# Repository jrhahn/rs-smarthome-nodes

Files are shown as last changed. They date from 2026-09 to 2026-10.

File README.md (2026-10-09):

# rs-smarthome-nodes

Async `no_std` Rust ([Embassy](https://embassy.dev)) firmware for a fleet of
**Seeed Studio XIAO ESP32-C3** smart-home sensor nodes. One image serves every
node: `NODE=<name>` at build time selects which sensors are populated, what the
node is called, and whether it sleeps between readings or stays associated.
Home Assistant picks the nodes up automatically over **MQTT
auto-discovery** — no hand-declared entities.

It started as a battery bird-feeder scale, which is still the default node
(`NODE=terrasse`): on each wake-up it reads a load cell via an HX711 amplifier
and compares it against a tare baseline kept in RTC RAM. While the feeder is
empty it polls every couple of seconds from **light** sleep — no radio, and no
cold boot per poll — which bounds how short a visit it can see at all. The
amplifier is powered down between those polls, and its settling time after
power-up is waited out asleep rather than awake. Once weight crosses the threshold it
stops sleeping and **watches the visit through awake**, so the published weight
is a settled median rather than whichever conversion happened to land first, and
the visit gets a real duration instead of one rounded to the sleep interval;
then it brings up Wi-Fi and publishes once (grams converted on-device). A
periodic **heartbeat** (default every 10 min) publishes anyway, so
Home Assistant always has a fresh reading. While online it also pulls any
retained calibration/tuning back from Home Assistant and persists it to flash.

```
┌──────────┐  bit-bang   ┌────────┐       Wi-Fi/MQTT            ┌────────────────┐
│  Load    │────────────▶│ HX711  │──▶ ESP32-C3 ───────────────▶│ Home Assistant │
│  Cell    │  DT / SCK   │ 24-bit │   smarthome/<node>/<key>    │                │
└──────────┘             └────────┘   ◀── config/* (retained) ──│  (calibration) │
   SHT31-D / SCD41 / SGP41 ─ I²C ────▶                          └────────────────┘
   SDS011 ─ UART ────────────────────▶  homeassistant/… (discovery, retained)
   battery divider ─ ADC ────────────▶
```

## The fleet

Pick a node with `NODE=` at build time (`src/node.rs`); an unknown name fails
the build rather than flashing the wrong personality onto a board. A board can
also be **provisioned** to another identity afterwards, without a rebuild.

| `NODE=` | Room | Sensors | Outputs | Power |
| --- | --- | --- | --- | --- |
| `terrasse` (default) | Terrasse | HX711 load cell + SHT31-D + cell voltage | — | battery, deep sleep |
| `schlafzimmer` | Schlafzimmer | SCD41 + SHT31-D | — | mains |
| `wohnzimmer` | Wohnzimmer | SCD41 + SHT31-D + SDS011 + SGP41 | — | mains (fan) |
| `kueche` | Küche | SHT31-D | — | mains, duty-cycled |
| `bad` | Bad | SHT31-D | — | mains, duty-cycled |
| `solarleuchte` | Garten | SHT31-D + cell voltage | LED string (LEDC) | battery, deep sleep |

A board can be told to become another node over MQTT, without reflashing — see
[provisioning](docs/flashing.md#7-provisioning-a-board-without-reflashing).

**Power profiles** decide the loop. *Battery* nodes cold-boot out of deep sleep,
measure, publish only when there is something to say, and sleep again, at the
runtime intervals set from [Home Assistant](docs/home-assistant.md#configure--calibrate-from-home-assistant). *Mains* nodes stay associated and sample on a fixed
per-node cadence — CO₂ continuity and the SDS011's duty-cycled fan both rule out
deep sleep. A sensor whose own cadence is slower than the node's round says so
per slot (`Slot::every`), which is how `wohnzimmer` reads CO₂ every minute while
its fan runs four times an hour.

*Mains, duty-cycled* is the third: on a cable, but deep-sleeping between rounds
anyway. The reason is heat rather than power. A node that keeps Wi-Fi up draws
something like 80–110 mA without pause, which is roughly a third of a watt
warming the inside of a small box, and a node whose entire job is to report the
room's temperature cannot afford to warm the air it is measuring. `kueche` and
`bad` carry nothing that needs continuity, so they stop running between
readings, sleeping their own `sample_secs` — the cadence they already published
at, so no history gets a step in it. Any node that sleeps at all keeps the
`config/deep_sleep` switch, which holds it awake for bench testing.

## Quick start

```bash
cp .env.example .env              # Wi-Fi + MQTT credentials; direnv loads it
NODE=kueche cargo run --release   # build, flash over USB-C, open the monitor
```

The full procedure — toolchain, the partition table, flashing a sleeping node,
what a healthy boot log looks like — is in [docs/flashing.md](docs/flashing.md).

## Documentation

| | |
| --- | --- |
| [docs/flashing.md](docs/flashing.md) | building, flashing, provisioning, Wi-Fi credentials over the console |
| [docs/wiring.md](docs/wiring.md) | pin map and wiring for every node |
| [docs/home-assistant.md](docs/home-assistant.md) | topics, entities, calibration and tuning knobs |
| [docs/enclosure.md](docs/enclosure.md) | the printed enclosures (`cad/`) |
| [docs/base-platform.md](docs/base-platform.md) | design notes: node abstraction, power profiles, discovery, testing |
| [docs/ota.md](docs/ota.md) | over-the-air updates |
| [docs/solar.md](docs/solar.md), [docs/solarleuchte.md](docs/solarleuchte.md) | solar for `terrasse`; the rebuilt garden lamp |
| [docs/long-term-history.md](docs/long-term-history.md) | keeping the fleet's data for years |
| [docs/commissioning.md](docs/commissioning.md) | what is physically built, board by board |
| [docs/annotations.md](docs/annotations.md) | fleet log: rollouts, outages, recalibrations — dated |
| [CHANGELOG.md](CHANGELOG.md) | what changed in the code |

## Repository layout

```
src/            firmware (lib + bin); sensors/ holds the bus-generic drivers
examples/       lamp_bench — bench rig for the solarleuchte lamp
timeseries/     the QuestDB archiver and dashboard (own crate)
cad/            CadQuery source (models.py) and exported STEP/STL
docs/           everything above
partitions.csv  OTA partition table, passed on every flash
```

## Tests

A firmware binary for `riscv32imc` cannot host a test harness, so the crate is
split: [`src/lib.rs`](src/lib.rs) holds everything the binary is made of, and
the parts that are **pure computation** — frame decoding, CRCs, the flash blob
layouts, `Config::apply`, the discovery payloads, the node table — build without
the HAL and therefore run on the host.

```bash
# What CI runs
cargo test --no-default-features --features host-tests \
    --target x86_64-unknown-linux-gnu
```

The sensor drivers themselves are covered too. They are generic over the
`embedded-hal-async` / `embedded-io-async` bus traits, so
[`src/sensors/mock.rs`](src/sensors/mock.rs) can feed the *real* SHT31, SCD41
and SDS011 drivers a scripted bus: canned I²C replies, and a UART that hands
over stale frames, falls quiet, then delivers the frame that matters. That
covers the resync, the CRC rejection, the fan duty cycle, the SCD41's two run
modes and its data-ready handshake, and what happens when a sensor is absent —
but not timing, bus contention or anything electrical, which stay bench
questions.

Anything that touches the chip itself — RTC RAM, flash, the radio, the bit-bang
drivers — sits behind the `hal` feature (on by default), so a normal
`cargo build` is unaffected. Compile-time
`const _: () = assert!(…)` checks stay where they are: they cost nothing and
fail the *build*, which is stronger than a test — the tests cover what
const-eval cannot reach, such as anything that formats a string, negative cases,
and inputs enumerated in a loop.

[CI](.github/workflows/ci.yml) runs the tests, both clippy passes, and builds
every node in the fleet — plus a check that a mistyped `NODE=` still fails the
build.

## Long-term history

Home Assistant sees every node the moment it publishes, and keeps a recorder
database — tuned for weeks. The questions this fleet was built for are slower
than that: did insulating the roof change the bedroom's overnight CO₂, how does
the terrace swing between summers, is the feeder busier this year than last.

[`timeseries/`](timeseries/README.md) is a second consumer on the same broker
whose only job is not to lose anything. It follows the topics the nodes already
publish, writes each reading into **QuestDB** with a **three-year retention**,
maintains three cascading rollup views (`_1m` → `_1h` → `_1d`) so a year-wide
chart reads thousands of rows instead of millions, and serves a small dashboard
that routes each query to the coarsest view still fine enough to answer it.

```bash
nix develop .#timeseries
cd timeseries && cargo run -- timeseries.example.toml   # then http://127.0.0.1:8087
```

It changes nothing about the firmware or the Home Assistant side — a node does
not know it is being archived. The flake carries a package and a NixOS module
(which brings up QuestDB too, since nixpkgs ships the package but no service)
for the home server; see [`timeseries/README.md`](timeseries/README.md) for the
schema, the rollup reasoning, and how to deploy it.

## License

MIT — see [LICENSE](LICENSE).

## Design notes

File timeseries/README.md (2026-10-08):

# `smarthome-timeseries`

The fleet's long-term memory: one process that follows the MQTT topics the
nodes already publish, writes every reading into **QuestDB** with a **three-year
retention**, and serves a small dashboard that reads it back.

```
┌──────────┐   smarthome/<node>/<key>   ┌───────────────┐   ILP/HTTP   ┌──────────┐
│  nodes   │───────────────────────────▶│   this        │─────────────▶│ QuestDB  │
│ (ESP32)  │   homeassistant/…/config   │   service     │◀── SQL ──────│ readings │
└──────────┘───────────────────────────▶│               │              │ + 3 views│
                                        └───────┬───────┘              └──────────┘
      ┌────────────────┐                        │  HTTP :8087
      │ Home Assistant │◀── same broker ────────┘  charts, live values, health
      └────────────────┘
```

Nothing here touches the firmware or Home Assistant's configuration. A node does
not know it is being archived; switching this off leaves the house working
exactly as before.

## Why it exists

Home Assistant already sees every node — the firmware announces itself over MQTT
auto-discovery — and it keeps a recorder database. What it does not keep is
*years*. Its recorder is tuned for weeks, and the questions this fleet was built
to answer are the slow ones: did insulating the roof change the bedroom's
overnight CO₂, how does the terrace swing between summers, is the bird feeder
busier this year than last.

So: a second consumer on the same broker, whose only job is not to lose
anything.

## What it stores, and what it does not

The firmware's topic layout is the entire schema:

| Topic | Stored as |
| --- | --- |
| `smarthome/<node>/<key>` | a row in `readings` |
| `smarthome/<node>/status` | a row in `node_status`, **on change only** |
| `smarthome/<node>/config/<key>` | nothing — a setting, not an observation |
| `smarthome/provision/<mac>` | nothing — an instruction |
| `homeassistant/sensor/<node>/<key>/config` | nothing; read for units and names |

Two details that are easy to get wrong, and are tested:

- **`provision` is not a node.** `smarthome/provision/a1b2c3d4e5f6` has the same
  three segments as a reading, and would otherwise be archived as a node called
  `provision` with a sensor called `a1b2c3d4e5f6`.
- **A retained reading is not a new reading.** The broker replays retained
  messages when this service subscribes, and the only timestamp available here
  is "now" — so a replay would stamp an old value as current. Readings arriving
  with the retain flag are skipped. This does not affect live publishes: MQTT
  clears the flag on messages delivered to an already-subscribed client, so a
  node publishing retained data is still archived normally.

Timestamps are when the bridge received the message. The nodes send none of
their own — they are `no_std` boards without a clock — and on a broker on the
same LAN the gap is milliseconds.

## The database

```sql
readings(timestamp TIMESTAMP, node SYMBOL, sensor SYMBOL, value DOUBLE)
  TIMESTAMP(timestamp) PARTITION BY DAY TTL 3 YEARS
```

plus three cascading materialized views, each aggregating the next finer one:

| View | Bucket | Reads | Partition |
| --- | --- | --- | --- |
| `readings_1m` | 1 minute | `readings` | day |
| `readings_1h` | 1 hour | `readings_1m` | month |
| `readings_1d` | 1 day | `readings_1h` | year |

Each stores `min`, `max`, `sum` and `count` per channel per bucket. The mean is
re-derived at read time as `sum(sv)/sum(n)` — the exact mean of the underlying
readings, not an average of averages that would weight a sparse hour (node
asleep, one reading) like a full one.

**Why cascade.** QuestDB refreshes a view by re-aggregating the buckets the new
rows touched. A daily view built directly on the base table therefore re-scans
the whole current day on every commit, for ever. Built on the hourly view it
re-reads twenty-four rows per channel.

**Why not timers.** The gateway firmware puts its coarse tiers on `REFRESH EVERY
5m` / `1h`, because at 100 Hz ingest an immediate refresh of every tier is what
pegged three CPU cores. This fleet publishes about one reading a minute per
channel, so there is nothing for a timer to save — and on QuestDB 9.3.5 a
timer-refreshed view created over a source that was still empty did not pick up
2160 rows inserted into that source over the following twenty minutes. That is
exactly the shape of a first install. Every tier here is `REFRESH IMMEDIATE`.

**Retention** is a QuestDB table TTL, applied to the base table and to every
view, and re-applied on each start — so changing `retention` in the settings
file is enough to change it on a table that already exists. QuestDB drops data a
whole partition at a time, which is why the setting must be a whole number of
days or coarser.

## Reading it back

`GET /api/series?node=…&sensor=…&from=…&to=…&points=…` picks a bucket from a
fixed ladder (1s … 30d), then routes the query to the **coarsest view whose
bucket is still fine enough**. Below a minute, and whenever a view is missing,
it reads the base table. The response is identical either way — `lo`, `hi`, `av`
per bucket — so the chart never branches on where the numbers came from.

Two things make that promise literal rather than approximate:

- The window is **widened to whole buckets** before querying. Ask for "the last
  365 days" at a daily grain and the window starts mid-day: the raw table would
  answer with a partial first bucket while the daily view's row for that day
  starts before the window and is filtered out entirely. Rounded out, both
  answer with the same full bucket.
- A rollup that returns nothing is **retried against the base table**, so a view
  that is somehow behind shows the truth rather than a blank chart.

This is checked against a live database rather than asserted: see the smoke test
below, which compares every zoom level against a full scan of the raw table.

| Endpoint | |
| --- | --- |
| `GET /` | the dashboard (three embedded files, no CDN, no build step) |
| `GET /api/overview` | every channel at once: labels, last value, and a sparkline |
| `GET /api/series` | one channel, full resolution |
| `GET /api/periods` | every channel per day / week / month in local time; meters as consumption |
| `GET /api/annotations` | the notes in a window; `POST` writes one |
| `POST /api/annotations/void` | takes one back, by `at_ms` and `node` |
| `GET /api/channels` | the channel list without any series — for scripts |
| `GET /api/health` | broker and database reachability, rollups, counters |

`/api/overview` is one database query for the whole screen rather than one per
channel. Thirty-one round trips to paint a page would be the obvious way and the
wrong one; the rollups are already grouped by channel, so the same `SAMPLE BY`
without a `node`/`sensor` filter answers all of them together.

## Periods: per day, week and month

`GET /api/periods?period=day|week|month&count=N` answers the question the
sliding window cannot: how much water did Tuesday take, is this month's
electricity more than last month's. Periods start where the house's day starts —
local midnight, Monday, the 1st, in `Europe/Berlin` — via `SAMPLE BY 1d|1w|1M
ALIGN TO CALENDAR TIME ZONE`.

- **Meters** — channels whose discovery message says `state_class`
  `total_increasing` or `total` — are reported as **consumption**: the period's
  last reading minus the previous period's last reading. Not the maximum: the
  water meters are read by a camera, a misread digit sends one reading up and
  the next back, and differences of last readings still sum to exactly the
  meter's movement over the range. A period that went backwards (misread,
  reset) is kept and flagged `approx`; so is the first period of a history,
  which has nothing to subtract.
- **Everything else** gets min / mean / max per period.

Meters are read from the base table, because the rollups keep no `last()`;
measurements from `readings_1h`, whose hourly buckets line up with local days in
both CET and CEST.

The page shows them as a second view (**Periods** in the header, `#p/day`): a bar
per period for every meter with a unit, unitless counts folded away beneath,
and a table of means per node. Channels Home Assistant marks `diagnostic` are
left out.

## What the dashboard shows

Two views, and the split is the useful part.

**The overview** is a wall of tiles, one per channel, grouped by node: the
current value, its unit, a sparkline over the selected range, and the span that
sparkline covers. Small multiples rather than one chart with thirty-one lines
on it — the channels are in different units, and a shared axis across
micrograms, parts per million and degrees would be a lie. Node headings carry an
online/offline word beside the dot, because green and red are precisely the pair
a colour-blind reader cannot separate.

**The detail view** is one channel at full size: the min/max band with the mean
through it, min / mean / max / last as numbers above it, a crosshair that reads
out the bucket under the pointer, and the same numbers as a table for anything a
curve reads badly. Time ticks land on the hour, midnight or the first of the
month rather than on the span divided by eight — evenly spaced ticks put
`10.09.` on the axis twice on a week-wide chart.

Both views live in the URL: `#c/<node>/<sensor>/<range>` is a chart worth
sending to someone, and reloading keeps it.

### Zooming

Drag a span on the chart, scroll to zoom around the pointer, double-click to go
back — the same three gestures as the gateway's plots, because a chart you have
to learn twice is a chart nobody drags.

Two things make it behave rather than merely respond. A zoom pins an **absolute**
window, so the 30 s refresh stops sliding it: a window that moves while you are
measuring something against it is worse than no zoom at all. And a double-click
returns to the view that was active *before* zooming in, not to the widest range
there is — it is an undo, not a reset.

The window goes into the URL as `#c/<node>/<sensor>/<from>-<to>` in epoch
seconds, so a zoomed chart is as shareable as a preset one. While a zoom is
active no preset button is lit, because none of them is what is on screen, and
the footer says so along with the way out.

Nothing is vendored for this. The chart is a few hundred lines of canvas, and
three mouse handlers is a smaller thing to own than a plotting library.

### Comparing with the windows before it

**Compare** lays the six preceding windows of the same length behind the current
one. With the 24 h range that is today against the same hours of the last six
days — which is the question a house actually raises: *is this normal for a
Tuesday, or is something different?* With 7 d it is this week against the last
six weeks.

Each overlay is shifted forward by exactly one window length, so the clock lines
up: an hour on the axis is the same hour in every line, and with a 7 d window
the same weekday too. That alignment is the whole feature.

They are drawn as six steps of **one** hue at falling opacity, not six colours.
These are the same measurement at different times, which is an *order*, and an
order wants a ramp — six hues would claim they are six different things. The
current window keeps the solid 2 px line; the rest are thinner and quieter,
because one of them is the subject and six are the backdrop.

Two details that make it readable rather than merely correct. The min/max band
is dropped while comparing: it is the spread *within* one window laid over six
other windows' lines, and it is the one element wide enough to hide exactly what
the mode was turned on to show. And the tooltip lists all seven values at the
crosshair — the eye can see the lines differ, and this is what says by how much.

The earlier windows count towards the y-axis by their mean only, so one old
outlier's envelope cannot squash the window being looked at.

**Where the alignment is approximate:** a shift is a fixed number of
milliseconds. For 6 h, 24 h and 7 d that is exact. For 30 d it is not a calendar
month, and for 1 y it is 365 days, so leap years and month lengths drift. Read
those two as "roughly a month/year back", not as the same date.

**The page is in English and formats in `en-GB`**, pinned rather than taken from
the browser. A dashboard whose decimal separator depends on who opens it makes
two screenshots of the same reading disagree, which is a bad property for a
thing whose whole job is to be looked at later.

### CSV

The detail view's **CSV** button downloads what is plotted: the buckets behind
the chart and the table, not the raw readings — a three-year range is millions
of rows, and the page never had them.

The file formats for whatever opens it next rather than for a reader, and the
two are not the same thing. Timestamps are ISO 8601 in UTC, numbers carry full
precision with a dot, the separator is a comma and the line ending is CRLF, per
RFC 4180. Column headings name the unit (`mean (°C)`), and the file begins with
a byte-order mark for one reason: without it Excel reads the degree sign as two
characters of noise.

The bucket width is in the filename —
`kueche_temperature_2026-09-13_2026-09-14_5m.csv` — so a spreadsheet found again
in three months still says what one row covers.

## Annotations

A series outlives the memory of the hardware that produced it. The terrace's
weight steps because the scale was recalibrated, not because a heavier bird
arrived; the living room's VOC index climbs from 1 for a day because the
algorithm is learning the room. None of that is in the numbers.

`annotations` is a table beside the readings — timestamp, node, one sentence —
and the notes are drawn on the chart at the moment they describe. **It carries
no TTL at any setting**: a note that expires before the data it explains is
worse than no note at all.

The dashboard's *Notiz …* button writes one. `docs/annotations.md` in this
repository keeps the same history in prose and is the better place for the long
version; this is the half that a chart can draw.

### A note is confirmed, and can be taken back

Two properties this table needs that the readings do not, both learned the
expensive way on 2026-09-13.

**The write is read back before it returns.** QuestDB answers before it stores:
ILP over HTTP returns 204 once the line is *accepted*, so a line written against
a table created moments earlier can be dropped with the caller told it
succeeded. That is tolerable for a reading — another arrives in two minutes —
and not for a note, which is written once, by hand, about something nobody will
remember well enough to write again. `insert` therefore polls until the row is
visible and fails loudly if it never is.

**A note can be voided, because it can never be corrected.** The timestamp is
the designated column, so no `UPDATE` may move it, and QuestDB deletes no rows
at all. Before this, one mistyped timestamp could only be fixed by dropping the
whole table. Each note now carries `voided`, the *zurücknehmen* button beside it
sets it, and voided notes are left out of `GET /api/annotations`.

Marked rather than removed, on purpose: a log of what happened to the fleet
that silently loses its own corrections has a blind spot exactly where somebody
already got something wrong once. The row stays, and `select ... from
annotations` still shows it.

`UPDATE` needs the same read-back as the insert, and for a sharper reason —
QuestDB reports `{"dml":"OK","updated":N}` where `N` is a running total, not the
rows this statement touched. An `UPDATE` that matched nothing is indistinguishable
from one that matched everything. So voiding checks that a note is standing
there first, and afterwards that it no longer is.

An existing table is migrated on start: `CREATE TABLE IF NOT EXISTS` leaves one
alone, so the column is added by a separate `ALTER TABLE ... ADD COLUMN IF NOT
EXISTS`, which QuestDB accepts repeatedly and backfills as `false` — every note
written before anyone could take one back still counts.

## Configuration

One TOML file, every field optional — see
[`timeseries.example.toml`](timeseries.example.toml). Defaults assume a broker
and a QuestDB on localhost. Passwords can come from `password_file` so they stay
out of the file (and, on NixOS, out of the store).

## Building and running

The firmware's toolchain pin does not apply here; this crate has a
`rust-toolchain.toml` of its own and a `.cargo/config.toml` that undoes the
riscv32 default.

```bash
nix develop .#timeseries      # nixpkgs rustc, plus questdb and mosquitto
cd timeseries
cargo test                    # 75 tests, no database needed
cargo clippy --all-targets -- -D warnings
cargo run -- timeseries.example.toml
```

### The end-to-end smoke test

The unit tests cover the parts that are pure computation — topic classification,
ILP formatting, DDL shape, tier routing, bucket snapping. What they cannot cover
is whether QuestDB accepts any of it. That needs a real database:

```bash
# a QuestDB and a broker of their own, on ports nothing else uses
mkdir -p /tmp/ts-smoke/qdb/conf
cat > /tmp/ts-smoke/qdb/conf/server.conf <<'EOF'
http.bind.to=127.0.0.1:19000
http.min.net.bind.to=127.0.0.1:19003
pg.net.bind.to=127.0.0.1:18812
line.tcp.net.bind.to=127.0.0.1:19009
EOF
questdb.sh start -n -d /tmp/ts-smoke/qdb &
printf 'listener 11883 127.0.0.1\nallow_anonymous true\n' > /tmp/ts-smoke/mosquitto.conf
mosquitto -c /tmp/ts-smoke/mosquitto.conf &

# then point a settings file at 11883 / 19000 and run the service against it,
# publish with mosquitto_pub, and compare a rollup-answered chart against a
# full scan of the base table.
```

Doing exactly that is what turned up the two edge cases the code now handles
(partial buckets at a window's edge, and coarse views left empty by a timer).

## On the home server

The flake exposes a package and a NixOS module. The module also brings up
QuestDB itself, because nixpkgs ships the package but no service:

```nix
{
  inputs.smarthome-nodes.url = "github:jrhahn/rs-smarthome-nodes";

  # in the host's configuration:
  imports = [ inputs.smarthome-nodes.nixosModules.smarthome-timeseries ];

  services.smarthome-timeseries = {
    enable = true;
    settings = {
      mqtt.host = "127.0.0.1";       # the broker Home Assistant already uses
      questdb.retention = "3y";
      web.bind = "127.0.0.1:8087";
    };
    # Kept out of the store; systemd hands it over as a credential.
    mqtt.passwordFile = "/run/secrets/mqtt-password";
  };
}
```

The archiver runs as a `DynamicUser` with no state of its own. QuestDB gets a
static user and `/var/lib/questdb`, which is **the one directory worth backing
up** — it holds the data, the write-ahead log and the configuration.

Both QuestDB ports bind to loopback by default. That is deliberate: QuestDB's
HTTP interface serves ingestion, arbitrary SQL *and* a web console, none of it
authenticated.

> **Upgrades are one-way.** QuestDB's storage format only moves forward: a data
> directory written by one version cannot be opened by an older one, so rolling
> the package back after an upgrade does not roll the data back with it.

### How much memory QuestDB takes

More than it needs, unless told otherwise. A JVM with no `-Xmx` uses a quarter
of physical memory as its maximum heap, and QuestDB's launcher adds
`-XX:+AlwaysPreTouch` and the parallel collector, which never gives a committed
page back. So the database does not settle at its working set; it drifts up to
25 % of the machine and stays there.

`questdb.maxHeapPercent` caps it, 12.5 % by default — half of what the JVM would
have taken. It is passed through `JVM_PREPEND`, the launcher's own hook, which it
appends after its own flags, and a later JVM flag wins over an earlier one.
Measured on a 14.7 GB machine: 3688 MB of maximum heap without it, 1844 MB with.

A percentage rather than a fixed size so one configuration is sane on a 4 GB box
and a 32 GB one. It is a smaller number than it looks, because most of QuestDB's
memory is not heap at all — columns are memory-mapped files, and the kernel
reclaims those under pressure. The symptom of setting it too low is a query
failing on heap, which is loud and obvious; raise it then.

This matters most at a moment that has nothing to do with the database. A
`nixos-rebuild` needs around a gigabyte just to *evaluate* a full home-server
configuration, before it compiles anything — and it asks for it on a machine
where the quarter QuestDB took is not available to give back.

## Operations

**Change the retention.** Edit `questdb.retention`, restart. The service issues
`ALTER TABLE … SET TTL` on every start, for the base table and for every view.

**Look at the data directly.** QuestDB's console is on port 9000 (loopback, so
over an SSH tunnel), and the PostgreSQL wire protocol on 8812 for anything that
speaks it — Grafana, `psql`, a notebook.

**After changing a view's definition** in `rollup.rs` or `schema.rs`: the DDL is
`IF NOT EXISTS`, so an existing view is left alone. Drop the affected views
(coarsest first) and restart; they backfill from the history on creation.

```sql
DROP MATERIALIZED VIEW readings_1d;
DROP MATERIALIZED VIEW readings_1h;
DROP MATERIALIZED VIEW readings_1m;
```

**If a view is ever behind**, `REFRESH MATERIALIZED VIEW readings_1h INCREMENTAL`
catches it up without a full rebuild. `SELECT view_name, view_status,
refresh_base_table_txn, base_table_txn FROM materialized_views()` is how to tell.

## How long to keep it, and what that costs

Measured rather than guessed, and written up in
[`docs/long-term-history.md`](../docs/long-term-history.md): the fleet produces
~25,900 readings a day, a finished daily partition of exactly that shape came to
**828 KB**, and three years of raw data is therefore under a gigabyte. That page
also argues why the rollups should outlive the raw table rather than expire with
it, and what threatens a long series once storage has stopped being the problem.

## Limits worth knowing

- **Readings are lost if the database is unreachable for a long time.** The
  writer retries a failed batch on the next flush and keeps up to 100 000 rows
  buffered — over a day of this fleet's output — then drops the backlog with a
  loud log line rather than growing until the machine swaps.
- **No authentication on the dashboard.** It is read-only and binds to
  loopback; anything more is the reverse proxy's job.
- **The service does not create the MQTT user.** It is a normal client; give it
  read access to `smarthome/#` and `homeassistant/#`.

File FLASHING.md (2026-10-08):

# Building & flashing `rs-smarthome-nodes`

Preparing the firmware and getting it onto a Seeed XIAO ESP32-C3.

**TL;DR — you flash by just plugging the XIAO into USB-C.** The ESP32-C3 has a
built-in USB Serial/JTAG controller, so no external programmer or probe is
needed. See [§4](#4-flash-over-the-xiaos-native-usb-c-the-normal-way).

The Raspberry Pi Pico probe in [§5](#5-optional-flash-with-a-raspberry-pi-pico-picoprobe)
is **entirely optional** — only for when the native USB isn't usable (board
sealed in the enclosure, galvanic isolation, USB-JTAG disabled).

---

## 1. Prerequisites (one-time)

```bash
# Toolchain (pinned by rust-toolchain.toml, but install it explicitly once)
rustup toolchain install 1.95.0
rustup target add riscv32imc-unknown-none-elf --toolchain 1.95.0

# Flasher / monitor. espflash speaks the ESP ROM bootloader over any serial port.
cargo install espflash --version '^4'
```

> **espflash 4.x since #32.** Until then this page pinned 3.x: espflash 4
> refuses an image without an ESP-IDF app descriptor, and esp-hal 0.22 emitted
> none. The firmware now carries one (`esp_app_desc!`), so the flasher in
> `nix develop` is plain `pkgs.espflash`.
>
> **An image built before #32 still needs 3.x** — flashing an old commit with
> 4.x fails with `ESP-IDF App Descriptor missing`, and that looks like a broken
> board rather than a wrong tool. Do not force it with `--ignore-app-descriptor`:
> that writes garbage into the header's min-efuse-revision fields and the
> bootloader then rejects the app on every boot.

> The XIAO ESP32-C3 is RISC-V, so it uses the stock bare-metal target —
> **no Xtensa `espup` toolchain is needed.**

## 2. Configure the build

Everything below is baked in at compile time (see [`.env.example`](.env.example);
`direnv` exports a local `.env` automatically):

| Setting | Where |
| --- | --- |
| **Which node** | `NODE` env var — decides the sensors, topics and power profile |
| Wi-Fi SSID / pass | `SSID` / `PASSWORD` env vars at build |
| MQTT broker | `MQTT_BROKER` env var (dotted IPv4) |
| MQTT credentials | optional `MQTT_USER` / `MQTT_PASSWORD` env vars |
| MQTT port | `MQTT_PORT` in [`src/main.rs`](src/main.rs) |

`NODE` is the important one — one image serves the whole fleet:

| `NODE=` | Sensors | Power |
| --- | --- | --- |
| `terrasse` (default) | the outdoor node and the bird scale; every slot off while it is wired up | battery, deep sleep |
| `schlafzimmer` | SCD41 + SHT31-D | mains |
| `wohnzimmer` | SCD41 + SHT31-D + SDS011 | mains |
| `kueche`, `bad` | SHT31-D | mains |

A typo fails the build rather than flashing the wrong personality onto a board:

```
error[E0080]: evaluation of constant value failed
  = the evaluated program panicked at 'unknown NODE; expected one of:
    schlafzimmer, wohnzimmer, kueche, bad, terrasse'
```

## 3. Compile

```bash
# Just build the ELF (defaults to NODE=terrasse)
cargo build --release
# -> target/riscv32imc-unknown-none-elf/release/rs-smarthome-nodes

# …or build for another node
NODE=kueche cargo build --release
```

> Each node is a **separate build**, so rebuild before flashing a different
> board — the ELF path is the same for all of them. Or flash the same image
> everywhere and tell each board what it is afterwards; see
> [§7](#7-provisioning-a-board-without-reflashing).

`espflash` reads that ELF directly; there's no separate objcopy/bin step.

---

## 4. Flash over the XIAO's native USB-C (the normal way)

**This is all you need.** The ESP32-C3 has a **built-in USB Serial/JTAG
controller**, so the XIAO's USB-C port is the programmer — plug it straight into
your computer, no probe or adapter involved.

```bash
# Build, flash, and open the serial monitor in one step
# (`cargo run` uses the runner from .cargo/config.toml, which passes
#  `--partition-table partitions.csv` -- see below)
SSID="MyNetwork" PASSWORD="s3cret" cargo run --release

# …for one of the other nodes
NODE=kueche SSID="MyNetwork" PASSWORD="s3cret" cargo run --release

# …or flash an already-built ELF explicitly:
espflash flash --monitor --partition-table partitions.csv \
  target/riscv32imc-unknown-none-elf/release/rs-smarthome-nodes
```

Useful checks:

```bash
espflash board-info          # confirm the chip is detected
```

### Every flash now carries the partition table

`cargo run` passes `--partition-table partitions.csv`, and a hand-written
`espflash flash` must do the same:

```bash
espflash flash --partition-table partitions.csv --port /dev/ttyACM0 "$ELF"
```

**Leaving it out is not a no-op.** `espflash` then writes its own default table
— one `factory` app, no second slot, no `otadata` — and the board silently loses
the ability to update itself over the air. It still boots and still publishes,
so nothing about it looks wrong.

The table splits the flash into two 1 984 KB application slots either side of a
selector sector, and keeps `nvs` exactly where it was: the config blob at
`0x9000`, the identity at `0xA000` and the stored Wi-Fi credentials at `0xB000`
all stay addressable, so **the migration costs no board its calibration**. The
reasoning, and what the second slot is for, is in [`docs/ota.md`](docs/ota.md).

Check what a board actually has before assuming:

```bash
espflash partition-table partitions.csv     # what we intend to write
```

and after flashing, the boot log lists what is really there — a board that has
been migrated shows `ota_0` and `ota_1` where it used to show `factory`.

> **Getting into download mode:** a battery node (`NODE=terrasse`) enters deep
> sleep a couple of seconds after boot, which can interrupt a flash — mains
> nodes stay awake. If `espflash` can't sync, force the
> ROM bootloader: **hold the `B` (BOOT / GPIO9) button, tap `R` (RESET), release
> `B`.** Then re-run the flash command.

### Flashing a battery node without reaching its buttons

The buttons are not always reachable — a node in its enclosure, on a mast, or
wired into a scale. There is no need for them.

The reason a single `espflash flash` fails is not that the node is unreachable;
it is that it is only reachable *briefly*. It deep-sleeps about two seconds
after boot and its USB port goes with it, so one invocation started at the
wrong moment finds nothing.

**Check `espflash --version` first.** A flasher that does not match the image
(see [Prerequisites](#1-prerequisites-one-time)) fails on every single attempt
for a reason that has nothing to do with timing, and a retry loop turns that into
thousands of identical failures that read like an unreachable board.

**Waking up is not enough, and this is the part that wasted half an hour on
2026-09-12.** The USB controller does come back on every wake and does start to
enumerate — but an idle round is awake for milliseconds, far less than a host
needs to read a device descriptor. What that looks like from the host is a
device that appears and fails, about every two seconds, forever:

```
usb 6-1: new full-speed USB device number 18 using xhci_hcd
usb 6-1: device descriptor read/all, error -71
usb 6-1: new full-speed USB device number 20 using xhci_hcd
usb 6-1: device descriptor read/all, error -71
```

Seventy-six such attempts in three minutes, and **no `/dev/ttyACM*` is ever
created**, so a poll loop has nothing to fire at. Check `journalctl -k` before
concluding the node is dead: the `-71` storm means it is alive and sleeping.

So the node has to be made to stay awake first, and it has a switch for exactly
that. Publish it retained, because the node is asleep when you send it:

```bash
mosquitto_pub -h "$BROKER" -u "$MQTT_USER" -P "$MQTT_PASSWORD" \
  -t smarthome/terrasse/config/deep_sleep -m 0 -r -q 1
```

It is picked up on the node's next publish round — up to `heartbeat_interval`
away, ten minutes by default — and from then on the port enumerates properly
and stays. Then flash normally, and **put it back afterwards**:

```bash
espflash flash --port /dev/ttyACM0 "$ELF"
mosquitto_pub ... -t smarthome/terrasse/config/deep_sleep -m 1 -r -q 1
```

Watch for `config: deep_sleep = 1` / `deep sleep re-enabled — sleeping` on the
monitor to confirm it took. A battery node left awake is not a small mistake:
it draws about 28 mAh an hour against the ~3.3 mA that makes the cell last
weeks.

The poll loop below is still worth having, but for a narrower case: the node is
awake for several seconds during a publish round, and that window *is* long
enough to enumerate. It is the tool for catching a node that publishes often,
or for firing the instant someone holds `B` (BOOT) while plugging the cable in.

```bash
ELF=target/riscv32imc-unknown-none-elf/release/rs-smarthome-nodes
while :; do
  p=$(ls /dev/ttyACM* 2>/dev/null | head -1)
  [ -n "$p" ] && espflash flash --port "$p" "$ELF" && break
  sleep 0.02
done
```

Start it *before* plugging the node in. The 20 ms poll matters: at 200 ms most
of the window is gone before the first attempt.

**`head -1` is wrong the moment a second board is plugged in**, and that is the
normal case when you are flashing one node from a desk with another already
attached. The loop above would have written the terrace image onto the living
room node on 2026-09-13. Pick the port by MAC instead — `udevadm` reports it
without touching the board, which `espflash board-info` cannot claim, since it
resets the chip to ask:

```bash
udevadm info -q property -n /dev/ttyACM0 | sed -n 's/^ID_SERIAL_SHORT=//p'
# -> AC:27:6E:80:51:F8
```

That is also the quickest way to answer "which of these two is which" before
doing anything at all.

**And check whether you need the loop.** It exists for a node that never
enumerates. Once a `/dev/ttyACM*` is present and *stays* — the board is in the
ROM bootloader, or `deep_sleep = 0` has taken effect — a plain
`espflash flash --port` is simpler, and it reports its own success. A poll loop
that is watching a port which is already sitting there is a loop with a bug in
it, not a safety net.

One more thing the loop has to survive: a port that has just appeared may not
have its udev ACL applied yet, so the first open fails with `Permission denied`
even though the device is there. Retry a few times rather than treating the
first failure as absence.

`--port` is required, not optional: without it `espflash` asks which port to
use, and a non-interactive shell gets `IO error: not a terminal` rather than a
prompt.

Whichever route you take: **a reflash does not clear RTC RAM.** The tare
baseline, the presence flag and the discovery digest all survive it (see
[`src/state.rs`](src/state.rs)). If the point of the reflash was to clear a bad
baseline, pull the power afterwards and leave the beam alone for that boot.

The same fact has a sharper edge for *new* firmware. A
`#[ram(rtc_fast, persistent)]` word is never zeroed by the startup code, so one
that has just been added comes up holding whatever was in that slot — and
because the reflash preserved RTC RAM, the first boot on the new firmware is
**not** a cold boot, so a cold-boot check does not save you. The visit counter
came up at 2,345,324,652 that way on 2026-09-12. Guard such a word with a
checked pair rather than with a boot-time branch; `scale::VISITS_MAGIC` is the
worked example.

### Do not use `espflash monitor` to check *whether* an app is running

It resets the chip in order to attach — `--before default-reset` is the
default — so on this chip it destroys the thing you are trying to observe:

1. the pre-connect reset drops the chip into the ROM bootloader, which prints
   `boot:0x0 (USB_BOOT)` and `wait usb download`;
2. `--after hard-reset` then resets again so the app runs;
3. that second reset makes the USB serial/JTAG **re-enumerate**, which
   invalidates the monitor's open handle — it dies with `Broken pipe`, usually
   before the app has logged anything.

The result reads exactly like a board stuck in download mode, and it is not.
Both lines come from `espflash` on the way in, not from the board's final
state. Cost of learning this the hard way: a board declared dead, a BOOT/RESET
dance, and a power cycle, all for a node that had been booting correctly the
whole time.

To watch a battery node, read the port **passively** instead — no `espflash`,
no reset:

```bash
# wait for the port to appear, then just read it
while [ ! -e /dev/ttyACM0 ]; do sleep 0.2; done; cat /dev/ttyACM0
```

Two independent signals are worth more than the monitor here:

- **Port presence.** A board in download mode holds USB open continuously. One
  whose `/dev/ttyACM*` *disappears* is in deep sleep, and only the app sleeps.
  Absence of the port is evidence the app is running.
- **`Saved PC:` in the boot banner.** It is only printed when the chip came out
  of deep sleep, so it says the app ran on the previous cycle.

`espflash flash` is unaffected — it reports `Flashing has completed!` on its
own, and that line is trustworthy. It is only *observation after the fact* that
needs the passive read.

---

## 5. (Optional) Flash with a Raspberry Pi Pico ("picoprobe")

> **You almost certainly don't need this.** Use [§4](#4-flash-over-the-xiaos-native-usb-c-the-normal-way)
> unless the XIAO's own USB-C is unavailable — e.g. the board is potted in the
> feeder enclosure, or you want galvanic separation from your PC.

### 5a. Turn the Pico into a probe

Flash the Pico with the official **debugprobe** firmware (hold BOOTSEL, drag the
`debugprobe_on_pico.uf2` from
<https://github.com/raspberrypi/debugprobe/releases> onto the `RPI-RP2` drive).
`debugprobe` exposes two USB interfaces: a CMSIS-DAP debug port **and a
USB-to-UART bridge**.

### 5b. Which method — UART, not JTAG

The ESP32-C3 is a **RISC-V JTAG** target, but the debugprobe's CMSIS-DAP port is
SWD-oriented, and routing the C3's JTAG to external pins (GPIO4-7) requires
**irreversibly burning the `DIS_USB_JTAG` eFuse**. So the practical picoprobe
path is the **UART bridge** driving the ESP32-C3 ROM serial bootloader — no
eFuse burning, fully reversible.

> For interactive *debugging* (breakpoints via `probe-rs`), skip the Pico and
> use the XIAO's own built-in USB-JTAG over its USB-C port:
> `probe-rs run --chip esp32c3 <elf>`.

### 5c. Wiring (Pico debugprobe UART → XIAO ESP32-C3)

| Pico (debugprobe) | XIAO ESP32-C3 | Direction |
| --- | --- | --- |
| `GP4` (UART TX) | `D7` / GPIO20 (U0RXD)| probe → target |
| `GP5` (UART RX) | `D6` / GPIO21 (U0TXD)| target → probe |
| `GND` | `GND` | common ground |

Power the XIAO from its own USB-C or the LiPo — **do not** back-feed 3V3 from the
Pico. Keep grounds common.

Because the debugprobe UART does not drive the C3's `EN`/`BOOT` lines, download
mode must be entered **manually** (hold `B`/BOOT, tap `R`/RESET, release `B`).

### 5d. Flash over the probe's serial port

The debugprobe UART shows up as a serial device (Linux: `/dev/ttyACM1`, the
second CDC interface; macOS: `/dev/cu.usbmodemXXXX`).

```bash
# 1. Put the C3 in download mode (hold B, tap R, release B).
# 2. Flash over the Pico's UART bridge:
SSID="MyNetwork" PASSWORD="s3cret" \
espflash flash --monitor \
  --port /dev/ttyACM1 \
  --baud 460800 \
  target/riscv32imc-unknown-none-elf/release/rs-smarthome-nodes
```

If sync fails, drop the baud to `115200` (long/loose jumper wires limit rate)
and confirm TX/RX aren't swapped.

---

## 6. Verifying it works

The first line names the node the image was built for — check it before anything
else, it is the one mistake that produces a board that looks perfectly healthy
while publishing to the wrong room.

**Outdoor scale (`NODE=terrasse`, battery)** — a publish cycle:

```
node 'terrasse' (Terrasse) booted, battery profile
config: offset=8388608 scale=420 threshold=10g idle=2s active=10s
HX711 raw reading: 8402193
presence: raw=8402193 baseline=8388608 delta=13585
weight = 32.3 g
DS18B20 = 25.1 °C
SHT31-D found at 0x44
SHT31-D: air_temperature = 21.4
SHT31-D: air_humidity = 47.2
Wi-Fi link up, waiting for DHCP...
Got IP: 192.168.1.42/24
published Home Assistant discovery for node 'scale'
Published 32.3 to smarthome/terrasse/weight
Published 25.1 to smarthome/terrasse/temperature
Entering deep sleep for 10s
```

Idle cycles are much quieter — an empty feeder skips the radio, the DS18B20 and
the I²C sensors entirely, which is the whole point of the battery profile:

```
node 'terrasse' (Terrasse) booted, battery profile
HX711 raw reading: 8388601
Entering deep sleep for 2s
```

**An air-quality node (`NODE=wohnzimmer`, mains)** stays associated and loops.
Most rounds are the 60 s ones; the SDS011 joins one round in fifteen, which is
the only time the fan is heard:

```
node 'wohnzimmer' (Wohnzimmer) booted, mains profile
Wi-Fi link up, waiting for DHCP...
Got IP: 192.168.1.51/24
SHT31-D: temperature = 21.8
SHT31-D: humidity = 61.4
SCD41: co2 = 734
SDS011: pm25_raw = 8.3
SDS011: pm10_raw = 12.1
SDS011: pm25 = 6.1
SDS011: pm10 = 8.9
published Home Assistant discovery for node 'wohnzimmer'
Published 6.1 to smarthome/wohnzimmer/pm25
```

Weight is published in **grams** (converted on-device from the flash-stored
calibration); the `config:` line shows the values loaded from flash (or
built-in defaults on a blank device). Calibration and tuning are changed from
Home Assistant — see the [README](README.md#configure--calibrate-from-home-assistant).

### If a sensor is quiet

Every sensor is optional at runtime: one that does not answer is logged and
omitted, never fatal. What the log says, and what it usually means:

| Log line | Check |
| --- | --- |
| `HX711 not responding` | DT/SCK on D1/D0, and that the amp has power |
| `DS18B20 not responding; skipping temperature` | DATA on D2 **and the 4.7 kΩ pull-up to 3V3** |
| `no SHT31-D at 0x44 or 0x45 — check SDA/SCL and the pull-ups` | nothing ACKed on the bus: SDA=D4, SCL=D5, pull-ups present, sensor powered |
| `SHT31-D found at 0x45 (ADDR strapped high); using it` | nothing — the breakout straps ADDR high and the firmware adopted it |
| `no SCD41 at 0x62 …` | same bus checks; the SCD41 also needs a solid 3V3 supply, it draws ~200 mA in bursts |
| `SCD41 found …` but no readings on the first round | expected: the first measurement on the low-power periodic cadence needs ~30 s, it arrives next round |
| `SDS011 not responding; skipping its readings` | UART RX on D3 ← sensor TX, TX on D10 → sensor RX (not swapped), and the sensor on **5 V** |

The `found at 0x…` lines come from a one-shot I²C probe on the first measurement
of each boot, so a bus problem is visible before the first reading is even
attempted.

Subscribe on the broker side to confirm the payload:

```bash
# One node
mosquitto_sub -h <broker-ip> -t 'smarthome/terrasse/#' -v

# Everything the fleet publishes, including the discovery configs
mosquitto_sub -h <broker-ip> -t 'smarthome/#' -t 'birds/#' -t 'homeassistant/#' -v
```

The entities appear in Home Assistant by themselves — each node publishes
retained discovery configs on its first connect after a power-up, for its
readings *and* for its calibration/tuning controls. Nothing is declared by hand;
see [`home-assistant/README.md`](home-assistant/README.md) for the entity list
and for calibrating the scale.

> **Re-flashing does *not* re-announce discovery.** The "already announced" flag
> lives in RTC fast RAM, which survives both the flash and the reset that
> follows it — confirmed on hardware. It survives a power cycle too, often
> enough that nothing may depend on power clearing it: the living-room node came
> back from several seconds unplugged with its flags intact.
>
> Discovery no longer cares. It is gated on a digest of every message it would
> publish, so switching a sensor on and reflashing re-announces on the next
> connect all by itself. If you want to force it anyway, clear the retained
> configs with
> `mosquitto_pub -h <broker-ip> -t 'homeassistant/sensor/<node>/<key>/config' -r -n`.

---

## 7. Provisioning a board without reflashing

`NODE=` is only the identity a board *starts* with. Any board can be told to
become another node over MQTT — useful to repurpose one, to swap in a spare, or
to flash the whole fleet with one image and sort out which is which afterwards.

Every boot prints the topic to address that board on. It is keyed by MAC,
because that is the only name a board is sure of before it knows anything else:

```
node 'terrasse' (Terrasse) booted, battery profile
provision topic: smarthome/provision/a1b2c3d4e5f6
```

```bash
# Become the kitchen node
mosquitto_pub -h <broker-ip> -r -t smarthome/provision/a1b2c3d4e5f6 -m kueche

# Go back to the identity it was flashed with
mosquitto_pub -h <broker-ip> -r -t smarthome/provision/a1b2c3d4e5f6 -m default
```

**Publish it retained** (`-r`). The node only looks while it is online for a
publish, so for a sleeping battery node the retained message is what gets the
change delivered on its next wake-up. Then:

```
provisioned as node 'kueche'; restarting
…
node 'kueche' (Küche) booted, mains profile
provisioned as node 'kueche' (from flash)
```

Notes:

- The restart is deliberate — the sensor set decides which buses are brought up,
  which happens during boot.
- A name the firmware doesn't know is logged and ignored, and the board carries
  on as it was: `provisioning asked for unknown node 'kuche'; expected one of: …`
- The retained message is re-delivered on every connect, so the firmware writes
  flash only when the value actually changes.
- The identity lives in its own flash sector, so provisioning a board never
  disturbs a scale's stored tare/calibration.
- Remember to clear the retained message (`-r -n`) if you later hand the board
  to a different room by reflashing, or it will provision itself back.

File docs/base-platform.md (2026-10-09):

# Base sensor platform — design notes

Tracking: **#11** (epic) with sub-issues #12–#17.

The firmware started as a single-purpose bird-feeder scale. It is now one
configurable base for several ESP32-C3 nodes, each carrying a different subset
of sensors, selected with `NODE=<name>` at build time.

## Fleet

The node table — which `NODE=` carries which sensors on which power profile —
is in the [README](../README.md#the-fleet); `src/node.rs` is its source.

A node's sensors need not share a cadence: `sample_secs` is the base round, and
a slot may ask for a slower one of its own (`Slot::every`). `wohnzimmer` is the
case that forced it — a 60 s round for the SCD41, and one round in fifteen for
the SDS011, whose fan is a ~8000 h consumable.

Per-node wiring — which sensor sits on which pad, with the pull-ups and supply
notes — is in [wiring.md](wiring.md).

## Sensor set

| Sensor | Bus | Emits | Status |
| --- | --- | --- | --- |
| HX711 load cell | bit-bang | force → grams | done (`hx711.rs`) |
| DS18B20 | 1-Wire | temperature | done (`ds18b20.rs`) |
| SHT31-D | I²C 0x44 | temperature, humidity | done (`sensors/sht31.rs`, #13) |
| SCD41 | I²C 0x62 | CO₂, temperature, humidity | done (`sensors/scd41.rs`, #14) |
| SDS011 | UART 9600 | PM2.5, PM10 | done (`sensors/sds011.rs`, #15) |
| SGP41 | I²C 0x59 | VOC index, NOx index | done (`sensors/sgp41.rs`) |

I²C addresses do not clash, so SHT31-D, SCD41 and SGP41 share one bus. SDS011 is the only
UART sensor, and on `wohnzimmer` it runs alongside that bus. HX711 stays a
blocking bit-bang critical section.

The SDS011's readings are corrected for humidity where a node also carries an
SHT31 (`Slot::compensated`): a nephelometer over-reads in damp air, so the
κ-Köhler growth factor is divided back out and both the corrected and the raw
values are published. κ is a Home Assistant slider, because it is a property of
the room's aerosol rather than of the sensor.

## Abstraction (#12)

`sensors::Sensor` is HAL-agnostic:

- `measure() -> Vec<Reading>` — one measurement; empty on absence (never fatal).
- `descriptors() -> &[EntityDescriptor]` — per-reading metadata for HA discovery.

`Reading` carries a `key` (topic suffix) + a pre-formatted, float-free `value`,
matching the existing on-device formatting. Shared helpers live in
`sensors/mod.rs`: `crc8_sensirion` + `crc_word` (SHT31/SCD41), `write_tenths`,
`write_int`.

The drivers are generic over the `embedded-hal-async` (I²C) and
`embedded-io-async` (UART) bus traits, so they name no esp-hal type.
`platform.rs` is the one place that does: it brings up only the buses this node
needs, wraps the single I²C peripheral in a `SharedI2c` handle (a
`NoopRawMutex` — everything is sequential on one executor) so both I²C drivers
can *own* their bus as the trait wants, and exposes one `measure_all()`.

`node.rs` holds the per-node table: identity (id/name/namespace), the sensor
slots, the power profile and the mains sampling cadence. A slot can rename its
readings (`prefix` / `label`) so two sensors emitting the same quantity don't
collide — the outdoor node's DS18B20 keeps `temperature` while its SHT31-D
publishes `air_temperature` / `air_humidity`. An unknown `NODE` value fails the
build in const-eval.

### Which node am I? (build-time default + NVS override)

The identity is resolved once at boot, before any peripheral is touched, since
the sensor set decides which buses come up at all:

1. `BUILT_AS` — the `NODE=` the image was compiled with (default `terrasse`);
2. a name stored in flash, which overrides it.

`node::active()` returns the result. It is a plain `Copy` struct read from a
`static`, written once by `node::init()` — the same single-context discipline
`state.rs` uses for its RTC-RAM cells, which is sound here because nothing runs
before `init()` and nothing writes after it.

The override is set over MQTT on `smarthome/provision/<mac>` (retained), keyed
by MAC because that is the only name an unprovisioned board is sure of. A valid,
*different* name is written to flash and the board restarts into it; anything
else — an unknown name, or the name it already answers to — is ignored without
touching flash, which matters because a retained message is re-delivered on
every single connect.

The identity blob lives in the **second** NVS sector (`0xA000`), separate from
the calibration blob at `0x9000`: provisioning must never be able to disturb a
scale's tare, and the two have completely different write frequencies. Same
discipline as the config blob — magic, version, length, CRC-32 — so a blank,
erased, corrupt or half-written sector reads back as "no override" and the board
falls back to what it was built as.

The publish path iterates whatever the node produced (`Samples`) instead of
hard-coded HX711/DS18B20 calls. The HX711 and DS18B20 keep their own read paths
— the first because its reading drives the tare baseline and presence edge, the
second because its 750 ms conversion is only worth spending on publish cycles —
and contribute their readings and discovery descriptors to the same pipeline.

### Three ways a visit used to go missing

The presence decision moved out of `main` into
[`presence`](../src/presence.rs) once it became clear that the one piece of
arithmetic deciding whether a visit is recorded *at all* was also the only part
of the firmware no host test could reach. Two of the three holes it had are now
closed; the third is a physical trade-off and stays open.

**Absorbed by the drift tracker.** The baseline nudged itself by `delta/16` on
*any* sub-threshold reading, which is right for slow thermal and mechanical
creep and wrong for a bird. A visitor whose load sat below `threshold` — a small
species, or one perched half on the rim — was pulled into the baseline within
roughly 16 cycles, so the scale read "empty" again while it was still standing
there. On departure the delta went *negative*, also sub-threshold, so no falling
edge fired either and the baseline crept back. The visit left no trace in the
logs or on the broker, and the failure was systematic rather than random: it
discriminated against light birds specifically. Drift is now confined to a band
of `threshold/4`; anything between that band and the threshold is
`Decision::Unexplained`, which leaves the baseline alone and says so in the log.

**Detected, then badly weighed.** On a rising edge the firmware used to publish
one arbitrary conversion and deep-sleep for `active_interval` (default 10 s) —
*slower* than the 2 s idle poll, so the cadence dropped exactly when dense data
was wanted. One unaveraged sample could land while the bird was still settling,
the departure was quantised to the same 10 s grid, and every one of those cycles
paid its own Wi-Fi connect: a two-minute visit cost about twelve of them. A
visit is now watched through awake with the radio off — cheap, since visits are
short — sampling the cell continuously into a 32-deep ring. The published weight
is the median of that ring, which is deliberately the *most recent* samples: a
bird that has just landed is still moving, so the tail of a visit describes it
better than the head. `VISIT_MAX` caps one awake window at 60 s so a load that
is not a bird (snow, a twig) cannot hold the CPU awake; such a load falls back
to the old `active_interval` polling, which is all that knob is still for.

**Shorter than the idle interval.** A visit that begins and ends between two
polls is invisible, and with `idle_secs: 2` plus the ~0.3 s cold boot that
window is real. This one is not a bug and is not fixed: the HX711 has no
threshold output that could wake the ESP32-C3 from deep sleep, so the only
control is the wake rate — which is itself the dominant battery cost on this
node, well ahead of the radio. Lowering `idle_interval` trades runtime for
short-visit coverage, and nothing in the firmware can make that trade for you.

The published visit duration is a **lower bound** for the same reason: the
arrival is only known to within one idle interval.

### Where the battery actually goes

The node was built around "deep sleep is free, the radio is expensive", and
that turned out to have the ranking backwards. Two things dominated instead,
and neither was the radio.

**The boot overhead.** Deep sleep sat inside the poll loop, so a 2 s idle poll
cost a full ROM boot plus app init — 269 ms measured — to clock out one 100 ms
conversion. At `idle_secs: 2` that is roughly a quarter of the node's life
spent booting, against the ~18 s an hour the radio was actually up. The polls
now run inside one boot with light sleep between them, so a cold boot happens
once per *publish*: about six an hour rather than eighteen hundred.

**The amplifier.** The HX711 and the bridge it excites draw continuously —
about 1.5 mA for the chip plus whatever the load cell's bridge takes, which for
a 1 kΩ cell at ~3.2 V excitation is another ~3 mA. `power_down()` and
`power_up()` had been written, documented and then never called, because there
was no sleep that retained the pad level: in deep sleep the pad goes
high-impedance and `PD_SCK` is left to leakage, which is also why the
amplifier's deep-sleep current was never a known quantity. The amplifier is now
powered down between polls, and the datasheet's 400 ms settling wait after
power-up is spent *in light sleep* rather than awake — the amplifier needs to be
on for it, the CPU does not, and waiting it out awake would have cost more than
the power-down saves.

The two changes compose: light sleep is what makes the power-down possible,
because it retains GPIO output levels. RTC pad hold on `SCK` (issue #5) was only
ever necessary because deep sleep was the steady state. It no longer is — deep
sleep now lasts one poll interval per publish, purely so the next cycle gets a
fresh `Radio`, since `publish` consumes it.

**These are estimates, not measurements.** The only measured figure in the
paragraphs above is the 269 ms boot time, read off a real serial log. The
current figures come from datasheets, and the two that would move the answer
most are the load cell's bridge resistance — a 350 Ω cell triples that term —
and the light-sleep current with this chip's `RtcSleepConfig` default, which
keeps the digital domain powered and so does not match the datasheet's headline
light-sleep number. A multimeter in series with the cell, once asleep and once
awake, settles both.

There is a third answer that does not touch the budget at all: stop discharging
the cell on a schedule and let a panel carry it. That is [solar.md](solar.md),
and it is the only one of the three that also stops the box being opened.

### The measurement happened, and the estimate was 3× optimistic

Measured 2026-09-16, and it settles the paragraphs above: the node draws
**~10 mA**, not 3.3 mA. Runtime on the 2000 mAh cell is 8–9 days, not 25.

It needed no bench meter. The QuestDB archiver on the family server records
`battery_voltage`, and the discharge curve *is* the measurement — 4.14 V →
3.70 V over 3.5 days, roughly 840 mAh, i.e. ~10 mA averaged over everything the
node actually does, at the real duty cycle and the real temperature. That is
strictly better than a shunt reading of the standing states, which is what this
page asked for: no extrapolation from datasheet currents, no assumption about
how long a connect takes.

**It also answers the second question, and the answer is no.** The connect rate
over those days was 143/day ≈ 6/h — exactly what the estimate assumed, so joins
are not slow or failing. The radio is therefore 6 × 3 s × 110 mA ≈ 0.55 mA,
which was the right figure all along; only the denominator changed. So the radio
is **~5 %** of the budget, not 17 %, and the two options below cap out near
1.05× runtime rather than 1.2×. **Neither is worth building.**

Where the other ~9.5 mA goes is now the open question. The candidates are the
ones this page already names as unknown: the light-sleep floor with this chip's
`RtcSleepConfig` default, and the amplifier's on-time, which at ~500 ms of every
2 s idle cycle is a 25 % duty on ~4.5 mA. The cheap experiment is the runtime
knob rather than a meter — `idle_interval` went 2 s → 5 s on 2026-09-16, and if
the poll cycle is the dominant term the discharge curve will visibly flatten
within a week.

### Measuring it with what you have

The measurement above does not need a lab supply or a current probe, which is
the usual reason it does not get done.

**What a cheap multimeter cannot do is average.** The node alternates between
light-sleep polls, brief awake conversions and ~110 mA radio bursts of a few
seconds, six times an hour. A DMM updates two or three times a second and shows
something instantaneous; the figure wanted here is an integral, and it will
never appear on that display. Resolution is not the problem — a 200 mV
full-scale meter on its 200 mA range has a 1 Ω shunt, so 3.3 mA reads as 3.3 mA
with 3.3 mV of burden voltage, which is plenty to tell 1.5 mA from 3.3 from 8.

Two ways round it, in order of preference:

**1. Let the node measure itself.** It already publishes `battery_voltage` every
heartbeat. Charge the cell, run it flat, and read the answer off the broker:

```
I_avg [mA] = 2000 mAh / (24 h × days)
```

25 days is 3.3 mA; 12 days is 6.9 mA. This is not a worse substitute for the
bench measurement, it is a better one — it integrates every burst, every slow
Wi-Fi join and every visit, at outdoor temperature and the real duty cycle,
which is exactly the quantity the estimates above are guessing at. It costs
nothing but time, and it needs `src/battery.rs` on the hardware, which is
outstanding anyway.

**2. A 1 Ω shunt in the battery lead, read as millivolts.** For the breakdown —
how much is the amplifier, how much the light-sleep floor — the standing states
are steady and a meter reads them fine. Use voltage mode across a fixed shunt
rather than the meter's own current range: no fuse, no range switching, and no
brownout when the radio comes up. **On the 20 mA range a 110 mA burst puts
1.1 V across the meter's 10 Ω shunt**, which drops the board to ~2.6 V and
resets it mid-measurement. Short the leads first and note the offset; these
meters have one.

The second question — how long a real connect takes — comes off the serial log's
timestamps and needs no instrument at all.

### Radio options, parked behind a measurement

Two further battery ideas are on the table. **Neither should be started before
the measurement above exists**, and that is the whole reason they are written
down here rather than built: both of them optimise the radio, and on this node
the radio is the term everybody suspects first and the smallest one that
matters.

Against the estimated budget the radio is roughly **17 %** — about 0.55 mA of
~3.3 mA, from six connects an hour at ~3 s and ~110 mA. Driving it to *zero*
therefore caps out near **1.2×** runtime. Any proposal promising more than that
is either counting a different budget or assuming a different failure rate.

Which is the one case that changes the ranking: `WIFI_BUDGET` is **20 s**, the
bound on a join that never completes. If joins here are routinely slow or
failing, six of those an hour is ~3.7 mA and the radio genuinely does dominate.
So the measurement has to answer two questions, not one:

1. **What is the standing current**, asleep and awake — which settles whether
   the amplifier and the light-sleep floor are where the estimate puts them.
2. **How long does a real connect take**, from wake to `Entering deep sleep`.
   The serial log timestamps this for free. If it is seconds, the table above
   holds and neither option below is worth much. If it regularly approaches
   `WIFI_BUDGET`, go straight to option A.

#### Option A — static address plus a cached BSSID and channel

`ClientConfiguration` is built with `..Default::default()`, so `bssid` and
`channel` are both `None` and every join pays a full scan across all channels;
the stack then pays DHCP on top (`NetConfig::dhcpv4`). Caching the AP's BSSID
and channel in RTC RAM next to the tare baseline, and configuring a static
address, removes both. Estimated to recover a good half of what the radio costs,
for two more `#[ram(rtc_fast, persistent)]` words and a fallback path.

It needs no gateway, no second protocol and no change to the data model, and
its failure mode is benign: a stale cached channel falls back to the full scan
and the node connects anyway.

#### Option B — ESP-NOW to a mains-powered gateway

Connectionless frames on the Wi-Fi PHY: no association, no handshake, no IP,
250 bytes per packet. `esp-wifi` 0.11 gates it behind `esp-now = ["wifi"]` and
we already enable `wifi`, so it is a feature flag on a crate already in the
tree — no new dependency. A mains node would receive and republish to MQTT.

It would shorten the expensive window from seconds to milliseconds, and it
removes the 20 s worst case entirely. The costs are architectural rather than
incidental, and three of them are specific to this fleet:

- **The gateway conflicts with the self-heating fix.** A gateway has to listen
  continuously on-channel, so it cannot run modem sleep — and the obvious
  candidates, `kueche` and `bad`, both carry an SHT31. Keeping the radio awake
  on a mains node costs about 1 °C at the board, measured. The comment
  justifying `PowerSaveMode::Maximum` says the trade works because everything
  inbound is a Home Assistant knob nobody times; inbound sensor frames from a
  sleeping node are neither untimed nor buffered by an AP, so that reasoning
  does not survive the change.
- **Discovery would have to be published by proxy.** Nodes announce their own
  entities from `discovery::entities`. A gateway doing it for them means the
  fleet table moves there or goes over the air.
- **The config path is bidirectional.** A node subscribes to
  `node.config_wildcard()` and drains retained values into `Config::apply`,
  which is the broker's retention doing real work. A sleeping node cannot be
  pushed to, so it would have to *request* its config inside its awake window
  and the gateway would have to answer inside it.

Its failure mode is also worse than option A's rather than equivalent. Both
depend on a cached channel, but a Wi-Fi node with a stale one scans and
connects; an ESP-NOW node with a stale one is mute, and the gateway cannot tell
it, because it cannot reach it. Announcing the channel retained over MQTT only
helps nodes that already got through — precisely not the ones with the problem.
The remaining fix is pinning the AP's channel, which makes the sensor network
depend on a router setting that any firmware update can undo.

#### If they are looked at again

Take option A first regardless: it is strictly smaller, it shortens the same
window option B would delete, and the two are not exclusive. Option B earns its
keep only if the AP turns out to be unreliable, if the fleet grows several more
battery nodes (today there is exactly one, `terrasse`), or if
something needs sub-second latency — a button or a PIR rather than a scale that
reports every ten minutes.

## MQTT auto-discovery (#16)

On the first connect after a power-up, each node publishes one retained
`homeassistant/sensor/<node>/<key>/config` per reading, so Home Assistant creates
the device (identifiers = node id) and all its entities. State topics are
`<namespace>/<node>/<prefix><key>`; the config/command topics stay
`<namespace>/<node>/config/<key>`.

Whether to announce is decided by a digest of every topic and payload the
node would publish, kept in RTC RAM (`discovery::announcement_tag`): a changed
sensor set, cadence or identity re-announces on the next connect, and an
unchanged one sends nothing, so a deep-sleep wake costs no airtime for it. It
replaced a plain "announced once per power cycle" flag, which survived reflashes
and even short power cuts and so could stay wrong for days — see
[home-assistant.md](home-assistant.md#forcing-a-re-announce).

Every node now publishes under the fleet's own `smarthome/<node>/…` namespace.
The outdoor node used to be the exception — it kept a historical `birds/scale/…`
namespace and mirrored its weight to a pre-discovery `birds/scale/state` topic,
both carried purely so hand-declared Home Assistant entities would keep working.
That history was deliberately let go when the node was renamed to `terrasse`,
and the mirror (`legacy_weight_topic`) has since been removed from the firmware.

### Command entities

The knobs that flow the other way — the ones Home Assistant publishes to
`<namespace>/<node>/config/<key>` — are discovered as well, as `number`,
`switch` and `button` entities under the device's *Configuration* category. They
used to be the one thing still hand-declared in YAML, which meant each node in
the fleet needed its own copy-pasted block.

Which knobs a node gets follows from what it *is*: the calibration ones only on
a node with a load cell, the three interval ones only on a battery node, since
any node on a cable samples on its build-time cadence. The `deep_sleep` switch
splits off from those and follows *sleeping* rather than the power source, so a
duty-cycled mains node keeps its one way of being held awake on the bench. A
dead control on a device card is worse than a missing one.

Two details that are not obvious:

- **The button consumes its own message.** A button's payload is a constant, so
  the firmware cannot tell one press from the next; and the message must be
  retained, because a sleeping node is asleep when the button is pressed. So the
  node deletes the retained message (empty retained payload) once it has
  re-zeroed. The older timestamp-token scheme still works and is still
  remembered, which doubles as a backstop if a delete is ever lost.
- **`stat_t` points back at the command topic.** The node never echoes its
  stored config, so the sliders would otherwise sit at "unknown" until moved.
  Since commands are retained, the command topic already holds the last value
  set — which is exactly the state an optimistic control would show, except this
  one survives a Home Assistant restart.

### Availability

Two mechanisms, because neither alone covers a fleet that is half asleep:

| | Always-on node | Sleeping node (battery or duty-cycled) |
| --- | --- | --- |
| Last will (`avty_t` → `<ns>/<node>/status`) | yes | **no** |
| `expire_after` | 3 × `sample_secs` | 3 × `heartbeat_secs` (battery) or 3 × `sample_secs` (duty-cycled) |

A last will catches the node that dies *while connected*: the broker publishes
retained `offline` and Home Assistant greys the entities out at once. The node
publishes retained `online` right after each connect, and — importantly — sends
a proper MQTT `DISCONNECT` when a round is done, which tells the broker to
discard the will. Without that, a mains node that reconnects per round would be
declared dead after every single publish.

Sleeping nodes get **no** will at all: they are legitimately disconnected almost
all the time, so a will would mark them offline seconds after every reading.
That is about reachability rather than about the power source, so a duty-cycled
mains node drops its will along with the battery one. They rely on
`expire_after` instead, which is also what catches an always-on node that dies
*between* rounds (a clean disconnect discards the will, so nothing else would
notice). Three missed rounds is the threshold — one miss is a lost packet or a
failed join, three is a node that stopped — with a 120 s floor.

`expire_after` is derived from the live config, so changing the heartbeat
interval clears the "discovery published" flag and re-announces the entities
with the new expiry.

## Power profiles (#17)

- **battery**: deep-sleep between samples (the bird-scale behaviour), at the
  runtime idle/active/heartbeat intervals.
- **mains**: stay awake with Wi-Fi up, sample + publish every
  `NodeConfig::sample_secs` (60 s in the bedroom and living room). Continuous
  operation is required for the CO₂ value and for the SDS011's fan, whose duty
  cycle is a per-slot period rather than a node cadence (`Slot::every`).
- **mains, duty-cycled**: on a cable, but deep-sleeping between rounds anyway,
  for `sample_secs` (120 s in the kitchen and bathroom). See below — this
  profile exists because of the thermal problem, not the power one.

The profile is a per-node build-time choice. The live `config/deep_sleep` switch
works on any node whose profile sleeps at all — a node that stays awake has
nothing to gain from sleeping and CO₂/PM continuity to lose, so it ignores it.
The SCD41 follows sleeping rather than the power source: periodic measurement
where the node stays up (what its self-calibration expects), single-shot
wherever it sleeps, because a periodic measurement cut off by a deep sleep is
not periodic.

### Staying awake is a thermal problem

A node that never sleeps turns everything it burns into heat inside the
enclosure — and the sensors then measure their own board instead of the room.
Measured on `schlafzimmer` against a reference thermometer, 2026-09-03: the air
at the electronics sat ~1.5 °C above the room, and both the SHT31-D and the
SCD41 reported it faithfully. Worse, the SCD41's temperature offset had been
calibrated against that same warm SHT31-D, so the error had been copied into it
and the two agreeing with each other proved nothing.

Four things came out of that, in order of how much they were worth:

1. **Mount the sensors away from the board, and get the board's heat out of the
   box.** No firmware can undo a sensor sitting in warm air. This is the fix;
   the rest are refinements. "Away from the board" is not enough on its own —
   see the 2026-09-13 entry below, where a separate chamber still read 2.5 °C
   warm because the board's only way out led through it.
2. **80 MHz instead of 160.** The minimum esp-wifi will run the radio at
   (`MIN_CLOCK` in its `init`), and dynamic power scales with the clock. A round
   is a few I²C transactions and one publish, and I²C/UART timing comes off APB
   rather than the CPU clock, so nothing here notices the difference.
3. **Modem sleep, `PowerSaveMode::Maximum`.** esp-wifi never calls
   `esp_wifi_set_ps` by itself and the stack below comes up in MIN_MODEM, so
   `Minimum` would have been a no-op — `Maximum` is the setting that actually
   changes something. It costs up to ~300 ms before an inbound packet is
   collected; everything inbound here is a Home Assistant knob, and outbound
   traffic never waits on the sleep schedule.

4. **Stop running.** The three above shave the heat; this removes it. A node
   carrying nothing that has to be attended to continuously does not need to be
   associated between readings at all, and `PowerProfile::MainsDutyCycled` says
   so: mains-powered, deep-sleeping for its own `sample_secs`. `kueche` and
   `bad` took it on 2026-09-13. It is not available to `schlafzimmer` or
   `wohnzimmer` — the SCD41's self-calibration and the SGP41's hotplate both
   need a node that stays up — which is exactly why it is a profile and not a
   global setting.

Deliberately *not* done: a software temperature offset for the SHT31-D. The
overtemperature is roughly constant (P·R_th), so an offset is defensible in
principle, but it hides the problem rather than fixing it, depends on airflow,
and would have to correct the humidity alongside the temperature. The last of
those is the one that keeps deciding it: relative humidity is read against
temperature, so a box 2.5 °C warm reports an RH about seven points low, and an
offset that fixes only the temperature leaves the humidity wrong and now also
unexplained.

## Testing

`cargo test` cannot link for `riscv32imc`, and the crate used to be a single
binary that pulled in esp-hal, so it could not be built for the host either.
That left compile-time `const` assertions as the only harness, and the awkward
habit of validating things like the discovery JSON with throwaway host replicas
of the real code — copy-paste that proves nothing once it drifts.

So the crate is now a library plus a thin binary, and everything that touches a
bus, RTC RAM, flash or the radio sits behind the `hal` feature. With it off, the
remainder builds for the host: the protocol decoding, the CRCs, the flash blob
layouts, `Config::apply`, the node table and the discovery payload builders.
That is most of the logic that can be silently *wrong* rather than fail to
build.

Two changes fell out of making that possible, both of which stand on their own:

- `discovery` takes the `NodeConfig` as an argument instead of reading the
  global identity, so the payloads are a pure function of the node;
- the provisioning-payload parser moved out of `main.rs` into `node`, with the
  two facts it needs (the current identity, whether flash holds an override)
  passed in rather than read.

The tests worth having are the cross-checks, not the arithmetic: that a
discovered state topic is exactly the topic the publish path uses, that every
control key is one `Config::apply` accepts, that no two entities on a node share
a topic or a unique id, that the `val_tpl` a sensor announces names the member
its state payload actually writes, and that `KNOWN_NODES` still lists the fleet.
Those are the failures that would otherwise show up as an entity stuck at
"unknown".

That last-but-one is worth naming, because it is the shape all of them share. A
value template is Jinja, evaluated inside Home Assistant: rename the JSON member
a reading carries and nothing fails to compile, nothing fails on the node, and
every sensor in the house goes blank on the next reflash. The test reads the
member name back out of the template string and looks for it in a real payload —
the only place those two halves meet before Home Assistant does.

Compile-time assertions stay: they fail the build rather than a test run, and
they cover invariants a test cannot reach.

### Telling a dead bus from a missing sensor

A targeted probe cannot distinguish them: "no SHT31-D at 0x44" is what you get
whether the sensor is absent, at another address, or the bus is not working at
all — and those have completely different fixes. So when an expected device is
missing, and only then, the firmware sweeps `0x08`–`0x77` with zero-length
writes and reports what answered. Anything answering proves the wiring and the
pull-ups are fine; nothing answering proves they are not.

It is ~110 transactions, which is why it is a reaction to a problem rather than
part of every boot.

### Driver tests against fake buses

Making the drivers generic over `embedded-hal-async` / `embedded-io-async` was
about keeping them free of esp-hal types; the other half of that payoff is that
the **real** drivers run on the host against a scripted bus (`sensors/mock.rs`).
The `hal` feature was split for it: `drivers` brings in only the bus traits and
embassy-time, whose `std` time driver is what lets a test await a conversion.

The UART mock is the interesting one, because the SDS011 driver distinguishes
"stale frames buffered while the fan span up" from "the frame I want" purely by
draining until the line falls quiet. So the script is a list of segments with an
optional gap before each, and a run-dry mock returns `Pending` rather than
`Ok(0)` — which is what a real UART does, and what lets the driver's timeout
fire. Covered: the full duty cycle, the fan being parked on *every* exit path,
resync past noise, a rejected checksum, an absent sensor, and a stray `0xAA`
costing exactly one frame.

Writing them turned up one real hazard. `read_byte` and `drain` looped on a
read that completed with zero bytes, which never yields — so the surrounding
timeout could never fire and the driver would spin for ever. esp-hal's UART does
not do that (it waits for a byte) but the trait permits it, so both loops are
now bounded, with a `StarvedUart` test to keep them that way.

The SCD41 gets the same treatment, and there the two run modes are the point.
Periodic (mains) must send `start_low_power_periodic_measurement` exactly
**once** — a node that re-sent it every round would restart the conversion cycle
and never read anything — and must poll data-ready before reading, or it gets
the previous measurement. The low-power cadence (one sample per 30 s) rather
than the 5 s one: no mains node publishes faster than every 60 s, and the
measurements nobody collects are paid for in heat next to the SHT31-D. Single-shot (battery) does neither: it asks for one conversion,
waits it out, reads. Both must treat `0 ppm` as "no measurement yet" rather than
as air, which would otherwise draw a plausible flat line at zero. That one
single-shot test really does sit through the datasheet's ~5 s conversion; unlike
the SDS011 warm-up it is a fixed sensor timing, not a policy knob, so there is
nothing honest to shorten.

The HX711 gets the same treatment through the `embedded-hal` pin traits, and it
is the one driver that has actually been running — which is precisely why the
bit protocol is worth pinning down. The fake pins share a line, so a test can
check not only *what* was read but *when*: 24 bits most-significant-first, each
sampled while the clock is high (sampling on the low phase reads the next bit on
real hardware and produces plausible numbers rather than obvious ones), 25/26/27
total pulses depending on gain, the clock parked low afterwards so the chip is
not latched into power-down, and a disconnected amplifier timing out rather than
returning noise as a weight.

What this does *not* cover: timing, bus contention, anything electrical. A green
test says the driver handles the bytes correctly, not that the SHT31 answers
within 15 ms on the real bus.

## SDS011 warm-up

The fan cannot run continuously (~8000 h rated), so it is woken per sample — and
how long it stays awake was, until recently, a flat 20 s. That is a guess in
both directions: too long for still air, and too short for air that is actually
changing, which is exactly when the reading matters.

It now serves a **floor** and then watches. The floor (10 s) is not optional:
before the airflow establishes, the sensor repeats its last value, so frames
agree with each other perfectly and a settling check alone would stop on air
that is not moving yet. After it, the driver reads frames until three in a row
agree — within 1 µg/m³ plus 5 % of the larger, an absolute floor for clean air
where the sensor's own noise dominates and a proportional band for dirty air
where it does not — on **both** particle sizes, since PM2.5 settling while PM10
still climbs is not a settled reading.

A ceiling (30 s) stops it there and reports whatever it has: unsettled air is a
reason to publish the latest number, not to keep the fan spinning. One frame is
always read however tight the budget, because an unsettled reading beats an
empty round.

In still air this typically ends around 13 s rather than 20 — roughly 7 s of fan
life back on every sample, which on the kitchen node's four samples an hour is
the difference the duty cycle exists for.

## Wi-Fi credentials

Credentials were compile-time only, which made the one failure that matters
unrecoverable: a board that cannot join the network cannot be told anything
over the network either. MQTT provisioning — how the node identity is set — is
no help, because reaching the broker is precisely what is broken.

So the escape hatch is the **serial console**, the one channel that still works.
On a **cold boot** the board listens briefly for `ssid` / `psk` / `save`, stores
the pair in its own flash sector and restarts into it; `clear` returns it to
whatever it was flashed with. Physical access already implies the ability to
reflash, so this gives away nothing a USB cable did not.

Three decisions worth recording:

- **Cold boot only.** RTC RAM is wiped by a power-up and survives deep sleep, so
  the existing flag distinguishes "someone just plugged this in" from "this woke
  up to take a reading". A battery node pays the window once per power cycle
  rather than every two seconds.
- **The window depends on how stuck the board is.** Three seconds when it has
  usable credentials — it is only offering the chance to intervene — and two
  minutes when it does not, since a board that cannot join has nothing better to
  be doing.
- **Stored credentials are not trusted blindly.** After three consecutive
  refusals the connection task falls back to the build-time pair for the rest of
  the run. Unlike a wrong node name, a wrong passphrase cannot be corrected over
  the air, so without this a single typo would take a board off the network
  until someone walked over with a cable. The count deliberately lives in RAM,
  not RTC RAM: a power cycle should give the stored pair another try, because
  the likeliest cause of a run of failures is an access point that was down.

The passphrase is taken verbatim after the keyword, so one containing spaces
survives; only the line ending and trailing whitespace are stripped. A mangled
passphrase would be indistinguishable from a wrong one, which is a bad evening.
`show` prints the SSID and the passphrase's *length*, never its content — those
lines go to a log that may be scrolling in someone else's terminal.

## Known gaps

- Console provisioning is the only way to *set* credentials; there is no way to
  rotate them across the fleet remotely. Changing the router's passphrase means
  visiting each board with a cable.
- The battery budget is measured only as a whole (~10 mA, 2026-09-16, see
  *The measurement happened*); where the ~9.5 mA that is not the radio goes is
  still open. Both radio options stay parked — the measurement put the radio at
  ~5 % of the budget.
- RTC pad hold on the HX711's `SCK` (issue #5) is still undone, so the
  amplifier's state during deep sleep is undefined rather than powered down.
  Deliberate: deep sleep now lasts one poll interval per publish, so it is not
  worth the register work. It would matter again if deep sleep ever became the
  steady state.

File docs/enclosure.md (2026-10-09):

# Enclosures

[`cad/models.py`](../cad/models.py) is the CadQuery source for every printed
part; the exports are in [`cad/export/`](../cad/export/).

| Parts | For |
| --- | --- |
| `terrasse_body`, `_floor`, `_charger_tray`, `_anchor` | the bird-scale node, outdoors |
| `terrasse_beam_spacer`, `_beam_hanger` | the clamps the scale's bending beam hangs from |
| `wohnzimmer_tray`, `_lid` | the air-quality node |
| `schlafzimmer_tray`, `_lid` | the CO₂ node |
| `climate_tray`, `_lid` | `kueche` and `bad`, the plain climate nodes |
| `solarleuchte_body`, `_lid` | the garden lamp's electronics (#48) |
| `wasserzaehler_tube`, `_strap`, `_cap`, `_bar` | a camera tube for the water meters — not a node, see below |

Only the two terrasse groups are described below; the rest are documented in the
comments above their section of `cad/models.py`.

The clamps the file *started* as were retired in `f858d60` and are not
these — `git show d0df819:models.py` still has the originals, which put the wire
hole where the bar puts it rather than on the box's centre line.

The `wasserzaehler_*` parts are the one real exception to the naming rule. Every
other part here is named after a `NODE=` slug (`climate` after the pair of them) from [`src/node.rs`](../src/node.rs),
and `wasserzaehler` is not one and never will be: it is a camera tube for the
flat's two water meters, which are read by an ESP32-CAM running jomjol's
AI-on-the-edge-device, not by this crate. It lives here because this is where
the CAD toolchain lives, and a second copy of it elsewhere would be worse than
one stretched convention. The meters, the board criteria and the reasoning
behind the camera route are in `nixos-private/docs/zaehler.md`.

```bash
nix develop .#cad        # separate shell: OpenCASCADE is ~500 MB, cargo has no use for it
python cad/models.py     # writes cad/export/*.stl and *.step
```

CadQuery is not in nixpkgs (only the `opencascade-occt` kernel, without the
Python bindings), so the shell pins the wheels and installs them into
`.venv-cad` on first entry (ignored). The exports under `cad/export/` are
tracked, so printing a part does not require the toolchain at all — `.stl` to
slice, `.step` to open in CAD.

## `terrasse_body` + `terrasse_floor` + `terrasse_charger_tray` + `terrasse_anchor`

An **88 × 78 × 71 mm** box for the bird scale, in four parts. The size is not a
choice — it comes from the measured envelopes, plugs included:

| | | | |
|---|---|---|---|
| ESP32-C3 board | 40 × 30 × 35 | HX711 board | 40 × 25 × 30 |
| battery | 65 × 50 × 10 | SHT31 | 20 × 10 × 10 |

That is 128 cm³ with clearance. The first version of this box had a 98 cm³
interior, so no amount of rearranging would have done it; a grid packing search
puts the smallest interior that takes all four at 76 × 66 × 52, and only with
everything stood on end. This one is 80 × 70 × 66, which leaves room for the
mounts themselves — and, since 2026-09-18, for a fifth part the floor could
never have held: the solar charger, on a shelf above the other two boards.

The design follows from it hanging outdoors in the rain:

- **The roof has no seam and no penetration.** The box is a cup opening
  *downward*; the only joint faces the ground, where water cannot climb to it.
  The top 5 mm flare 2 mm past the walls as an eave, so water crossing the roof
  drips clear instead of running down the sides. Nothing is drilled through the
  top — the cord attaches to two round-ended tabs *outboard* of the walls,
  which is why the part reaches 108 mm across.
- **The SHT31 lives in the −X/−Y corner, no longer behind a wall.** Air enters
  through floor slots beneath it and leaves through slots high in *both*
  adjacent walls, tilted 30° down-and-out — every opening faces down or
  outward-down, so there is still a local draught across the sensor.

  There *was* a baffle around it, and it came out because the cable could not
  be got past it during assembly: the slot was widened, then run full height,
  and it still fouled. That costs accuracy, since the board's heat now shares
  the sensor's air — about 0.9 °C on the bedroom node. A box that cannot be
  assembled is worse than one that reads half a degree warm, but keep the SHT31
  in that corner rather than beside the board, or the loss compounds.
- **The floor screws go into M3 heat-set inserts**, Ø4 bores in 9 mm posts,
  which leaves 2.5 mm of wall — thinner than one would choose, and what the
  already-printed floor plate allows.

  The screw positions are not free: they are where the 8 mm post this box
  shipped with put them, and the plate in hand has its countersinks there. So
  the post has to grow *around* a fixed hole, and it meets two features of that
  same plate — the cell reaches x = 31 and the battery guides reach y = ±26.
  Nine millimetres leaves 0.5 mm to both; ten does not fit. The plate's HX711
  rib still fouled one post by 0.5 mm, so that post is relieved there rather
  than shrunk: the rib only has to slide past, the wall has to survive brass
  being melted into it. Warm the inserts properly and do not lean on them; if
  one splits, the way out is a reprinted floor with the holes further in, which
  buys 3.5 mm.
- **The load hangs off a pad** matching the clamp's 25 × 12 face and its screw
  pitch. Two **M4 × 25 countersunk** screws run *down* from inside the box —
  heads countersunk into the nut boss, nuts in a hex pocket under the beam
  spacer, which is the end you can still reach with a spanner once the box is
  together. They ran the other way until 2026-09-18, with captive nuts in
  pockets inside the box; a nut that drops out during assembly is a nut inside
  a sealed enclosure. That pad is
  `terrasse_anchor`, its own part since 2026-09-18 and clamped under the plate
  by the same two M4 screws. It was part of the plate until then, and it was
  the only thing on that face: while it was there the plate could not be
  printed without support, because an 84 × 74 plate laid anchor-down steps out
  over a 33 × 18 flange. Now **no part of this box needs support** — body roof
  down, floor plate down, anchor pad down.
- **The solar charger sits on a tray over the two boards**, on three columns
  rising from the floor plate, and the panel lead comes in through the floor.
  Both are why the box is 71 mm tall rather than 60. See
  [`solar.md`](solar.md).

## `terrasse_beam_spacer` + `terrasse_beam_hanger`

The two clamps that pad exists for. The **spacer** bolts up into the floor's
captive nuts and carries the bar's fixed end; the **hanger** grips the load end,
and the wire leaves from its far end.

Two parts rather than one, because both ends of the bar share the anchor's 15 mm
screw pitch — a single pair of screws cannot fasten the box and the bar at once.
The spacer offsets the fixed end until the pairs clear. `BEAM_DIR` decides which
way the bar runs from there; flipping its sign mirrors the whole assembly, and
since every feature sits on `y = 0`, an already-printed part just turns round.

The hanger is 80 mm, the bar's own length, with the M5 bolts at one end and the
wire hole at the other, **61.5 mm apart**. The wire leaving from the far end is
a requirement — it is where the feeder hangs — and the section is dimensioned
for it rather than around it.

What follows is a cantilever in the load path, which is why the **spine** is the
deep part at 20 mm and not the pad: stiffness goes with depth cubed. Deflection
here is an accuracy problem rather than a strength one — what bends does not
spring back exactly, and that shows up as hysteresis in the weight. If readings
ever differ between a loaded and an unloaded pan, deepen `RAIL_T` before
suspecting anything in the firmware.

**`RAIL_T` was 14 mm until 2026-09-27, and that was not enough.** Over three warm
days the terrace zero walked from +1.4 g to −75.8 g at matched air temperature and
did not return overnight — creep in the printed spine, not deflection. See
[`annotations.md`](annotations.md). 20 mm is 2.9× the stiffness and, since
bending stress goes with the square of the depth, about half the stress. It grows
*downward* into open air, so the 4 mm clearance below is untouched.

**The material matters more than the number.** That spine was PLA, which yields
under sustained load far below its glass transition, and a dark part in direct sun
runs well above the shaded air the SHT31 reads. **Print the hanger and the spacer
in PETG at the least, ASA for preference.** No `RAIL_T` survives PLA in August sun.

> **Nothing but the bar may bridge the two clamps.** Only the hanger's pad
> touches the bar; the spine runs 4 mm clear of it along its whole length and
> 16.7 mm clear of the spacer. If anything touches, the load path goes around
> the strain gauges and the scale reads a fraction of the weight — or none of
> it — without any sign that something is wrong.

**Printing.** The pad reaches down to the rail's underside rather than standing
proud of it, so there is one flat face across all 80 mm and a single 4 mm step
on top — a step *up*, overhanging nothing. The only downward faces off the bed
are the two counterbore ceilings, 112.9 mm² of bridge over a 5.3 mm hole. No
support. The pad is 24 mm thick as a result, and the bolts are **still M5 × 16** —
the counterbore swallows whatever the pad gains, so it deepens with `RAIL_T`
instead of asking for a longer bolt. What the M5 spans is the 8 mm of
`BOLT_BEARING` plus the bar's thread, which is why M5 × 12 does not reach. The
counterbore is now 16 mm deep at 10 mm across, so bring a hex key with the reach.

Calibrate in the fixture: `scale_factor` is what absorbs whatever the mounting
does to the sensitivity.

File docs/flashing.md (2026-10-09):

# Building & flashing

Preparing the firmware and getting it onto a Seeed XIAO ESP32-C3.

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

---

## 1. Prerequisites (one-time)

```bash
# Toolchain (pinned by rust-toolchain.toml, but install it explicitly once)
rustup toolchain install 1.95.0
rustup target add riscv32imc-unknown-none-elf --toolchain 1.95.0

# Flasher / monitor. espflash speaks the ESP ROM bootloader over any serial port.
cargo install espflash --version '^4'
```

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

## 2. Configure the build

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

`NODE` is the important one — one image serves the whole fleet:

| `NODE=` | Sensors | Power |
| --- | --- | --- |
| `terrasse` (default) | HX711 load cell + SHT31-D + cell voltage | battery, deep sleep |
| `schlafzimmer` | SCD41 + SHT31-D | mains |
| `wohnzimmer` | SCD41 + SHT31-D + SDS011 + SGP41 | mains |
| `kueche`, `bad` | SHT31-D | mains, duty-cycled |
| `solarleuchte` | SHT31-D + cell voltage, LED string | battery, deep sleep |

A typo fails the build rather than flashing the wrong personality onto a board:

```
error[E0080]: evaluation of constant value failed
  = the evaluated program panicked at 'unknown NODE; expected one of:
    schlafzimmer, wohnzimmer, kueche, bad, terrasse, solarleuchte'
```

## 3. Compile

```bash
# Just build the ELF (defaults to NODE=terrasse)
cargo build --release
# -> target/riscv32imc-unknown-none-elf/release/rs-smarthome-nodes

# …or build for another node
NODE=kueche cargo build --release
```

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

`espflash` reads that ELF directly; there's no separate objcopy/bin step.

---

## 4. Flash over the XIAO's native USB-C (the normal way)

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

```bash
# Build, flash, and open the serial monitor in one step
# (`cargo run` uses the runner from .cargo/config.toml, which passes
#  `--partition-table partitions.csv` -- see below)
SSID="MyNetwork" PASSWORD="s3cret" cargo run --release

# …for one of the other nodes
NODE=kueche SSID="MyNetwork" PASSWORD="s3cret" cargo run --release

# …or flash an already-built ELF explicitly:
espflash flash --monitor --partition-table partitions.csv \
  target/riscv32imc-unknown-none-elf/release/rs-smarthome-nodes
```

Useful checks:

```bash
espflash board-info          # confirm the chip is detected
```

### Every flash now carries the partition table

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

```bash
espflash flash --partition-table partitions.csv --port /dev/ttyACM0 "$ELF"
```

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

The table splits the flash into two 1 984 KB application slots either side of a
selector sector, and keeps `nvs` exactly where it was: the config blob at
`0x9000`, the identity at `0xA000` and the stored Wi-Fi credentials at `0xB000`
all stay addressable, so **the migration costs no board its calibration**. The
reasoning, and what the second slot is for, is in [`ota.md`](ota.md).

Check what a board actually has before assuming:

```bash
espflash partition-table partitions.csv     # what we intend to write
```

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

### Flashing a battery node without reaching its buttons

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

```
usb 6-1: new full-speed USB device number 18 using xhci_hcd
usb 6-1: device descriptor read/all, error -71
usb 6-1: new full-speed USB device number 20 using xhci_hcd
usb 6-1: device descriptor read/all, error -71
```

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

```bash
mosquitto_pub -h "$BROKER" -u "$MQTT_USER" -P "$MQTT_PASSWORD" \
  -t smarthome/terrasse/config/deep_sleep -m 0 -r -q 1
```

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

```bash
espflash flash --port /dev/ttyACM0 "$ELF"
mosquitto_pub ... -t smarthome/terrasse/config/deep_sleep -m 1 -r -q 1
```

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

```bash
ELF=target/riscv32imc-unknown-none-elf/release/rs-smarthome-nodes
while :; do
  p=$(ls /dev/ttyACM* 2>/dev/null | head -1)
  [ -n "$p" ] && espflash flash --port "$p" "$ELF" && break
  sleep 0.02
done
```

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

```bash
udevadm info -q property -n /dev/ttyACM0 | sed -n 's/^ID_SERIAL_SHORT=//p'
# -> AC:27:6E:80:51:F8
```

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

### Do not use `espflash monitor` to check *whether* an app is running

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

To watch a battery node, read the port **passively** instead — no `espflash`,
no reset:

```bash
# wait for the port to appear, then just read it
while [ ! -e /dev/ttyACM0 ]; do sleep 0.2; done; cat /dev/ttyACM0
```

Two independent signals are worth more than the monitor here:

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

---

## 5. (Optional) Flash with a Raspberry Pi Pico ("picoprobe")

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

### 5a. Turn the Pico into a probe

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

### 5b. Which method — UART, not JTAG

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

### 5c. Wiring (Pico debugprobe UART → XIAO ESP32-C3)

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

### 5d. Flash over the probe's serial port

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

```bash
# 1. Put the C3 in download mode (hold B, tap R, release B).
# 2. Flash over the Pico's UART bridge:
SSID="MyNetwork" PASSWORD="s3cret" \
espflash flash --monitor \
  --port /dev/ttyACM1 \
  --baud 460800 \
  target/riscv32imc-unknown-none-elf/release/rs-smarthome-nodes
```

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

---

## 6. Verifying it works

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

**Outdoor scale (`NODE=terrasse`, battery)** — a publish cycle:

```
node 'terrasse' (Terrasse) booted, battery profile
config: offset=8388608 scale=420 threshold=10g idle=2s active=10s
HX711 raw reading: 8402193
presence: raw=8402193 baseline=8388608 delta=13585
weight = 32.3 g
SHT31-D found at 0x44
SHT31-D: temperature = 21.4
SHT31-D: humidity = 47.2
battery = 3.94 V
Wi-Fi link up, waiting for DHCP...
Got IP: 192.168.1.42/24
published Home Assistant discovery for node 'terrasse'
Published 32.3 to smarthome/terrasse/weight
Published 21.4 to smarthome/terrasse/temperature
Entering deep sleep for 10s
```

Idle cycles are much quieter — an empty feeder skips the radio entirely, which
is the whole point of the battery profile. The SHT31-D is still read on every
wake, quietly, because the scale's temperature correction needs the air
temperature before the presence check:

```
node 'terrasse' (Terrasse) booted, battery profile
HX711 raw reading: 8388601
Entering deep sleep for 2s
```

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

```
node 'wohnzimmer' (Wohnzimmer) booted, mains profile
Wi-Fi link up, waiting for DHCP...
Got IP: 192.168.1.51/24
SHT31-D: temperature = 21.8
SHT31-D: humidity = 61.4
SCD41: co2 = 734
SDS011: pm25_raw = 8.3
SDS011: pm10_raw = 12.1
SDS011: pm25 = 6.1
SDS011: pm10 = 8.9
published Home Assistant discovery for node 'wohnzimmer'
Published 6.1 to smarthome/wohnzimmer/pm25
```

Weight is published in **grams** (converted on-device from the flash-stored
calibration); the `config:` line shows the values loaded from flash (or
built-in defaults on a blank device). Calibration and tuning are changed from
Home Assistant — see [`home-assistant.md`](home-assistant.md#configure--calibrate-from-home-assistant).

### If a sensor is quiet

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

Subscribe on the broker side to confirm the payload:

```bash
# One node
mosquitto_sub -h <broker-ip> -t 'smarthome/terrasse/#' -v

# Everything the fleet publishes, including the discovery configs
mosquitto_sub -h <broker-ip> -t 'smarthome/#' -t 'homeassistant/#' -v
```

The entities appear in Home Assistant by themselves — each node publishes
retained discovery configs on its first connect after a power-up, for its
readings *and* for its calibration/tuning controls. Nothing is declared by hand;
see [`home-assistant.md`](home-assistant.md) for the entity list
and for calibrating the scale.

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

---

## 7. Provisioning a board without reflashing

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

```
node 'terrasse' (Terrasse) booted, battery profile
provision topic: smarthome/provision/a1b2c3d4e5f6
```

```bash
# Become the kitchen node
mosquitto_pub -h <broker-ip> -r -t smarthome/provision/a1b2c3d4e5f6 -m kueche

# Go back to the identity it was flashed with
mosquitto_pub -h <broker-ip> -r -t smarthome/provision/a1b2c3d4e5f6 -m default
```

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

```
provisioned as node 'kueche'; restarting
…
node 'kueche' (Küche) booted, mains profile
provisioned as node 'kueche' (from flash)
```

Notes:

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

---
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

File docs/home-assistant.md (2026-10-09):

# Home Assistant

No YAML. Every node announces itself over retained MQTT discovery, both
directions:

- the **readings** become `sensor` entities (weight, temperature, humidity, CO₂,
  PM2.5/PM10, VOC/NOx index, battery, RSSI);
- the **calibration and tuning knobs** become `number` / `switch` / `button` /
  `light` entities, filed under the device's *Configuration* section.

Adding a node to the fleet therefore needs no change on the Home Assistant side
at all. The only requirement is the MQTT integration with discovery enabled (the
default) on the `homeassistant/` prefix.
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

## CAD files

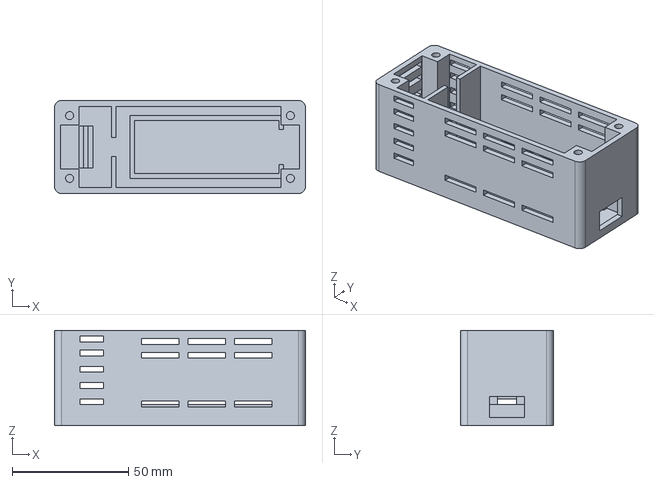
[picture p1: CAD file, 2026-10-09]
cad/export/schlafzimmer_tray.step
108.0 x 40.0 x 41.0 mm

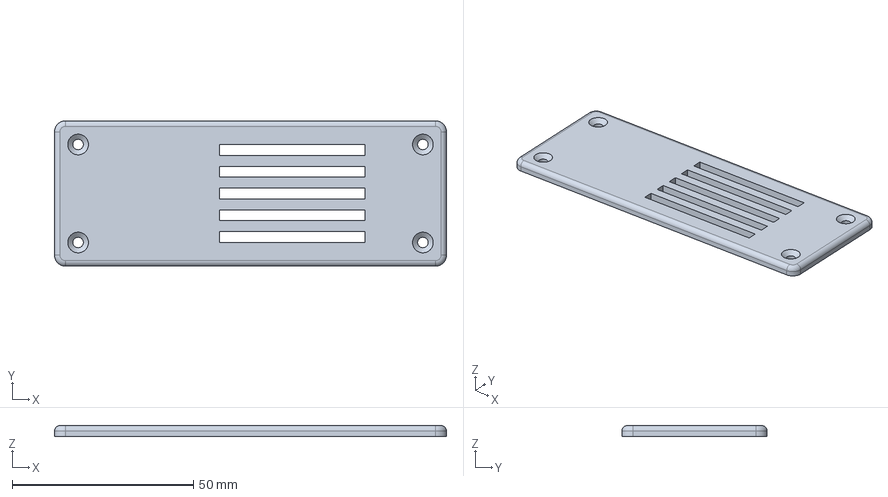
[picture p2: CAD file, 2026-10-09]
cad/export/schlafzimmer_lid.step
108.0 x 40.0 x 3.00 mm

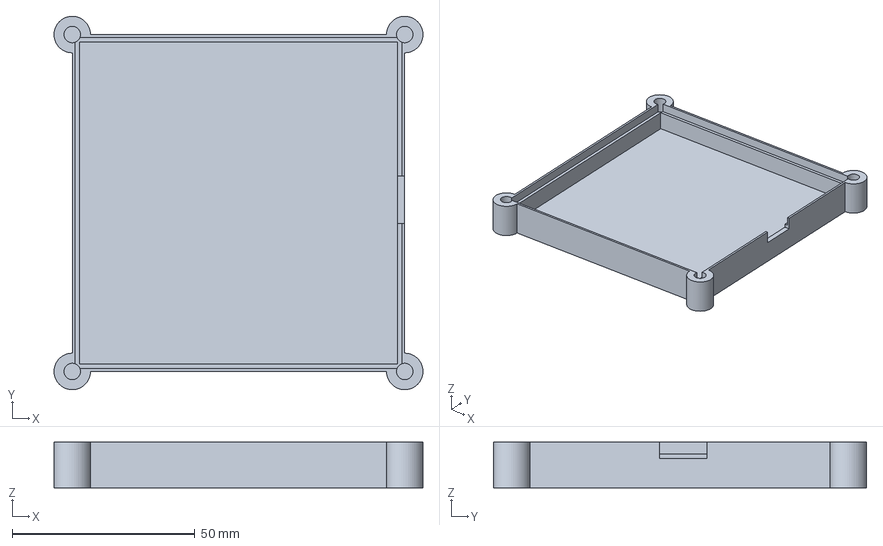
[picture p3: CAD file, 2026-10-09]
cad/export/solarleuchte_lid.step
101.0 x 102.2 x 12.5 mm

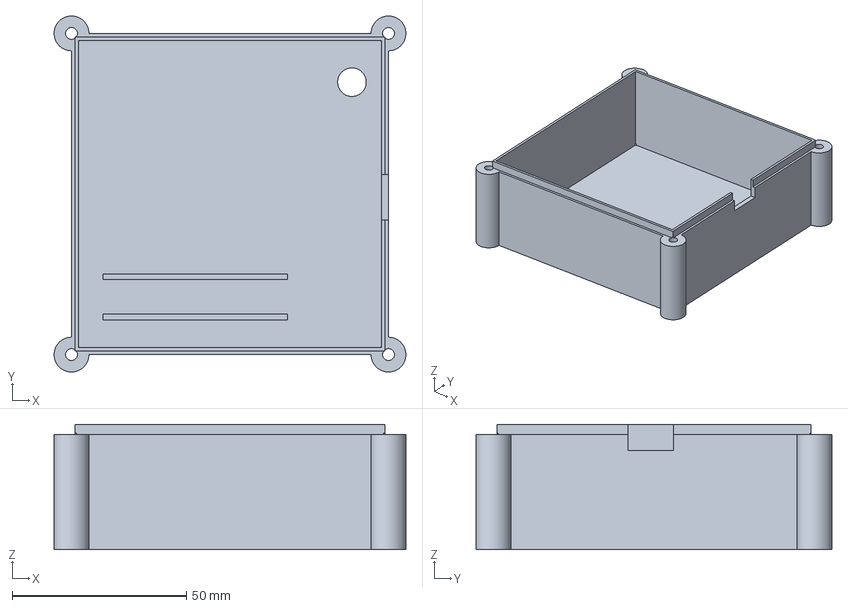
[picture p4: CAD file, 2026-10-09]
cad/export/solarleuchte_body.step
101.0 x 102.2 x 36.0 mm

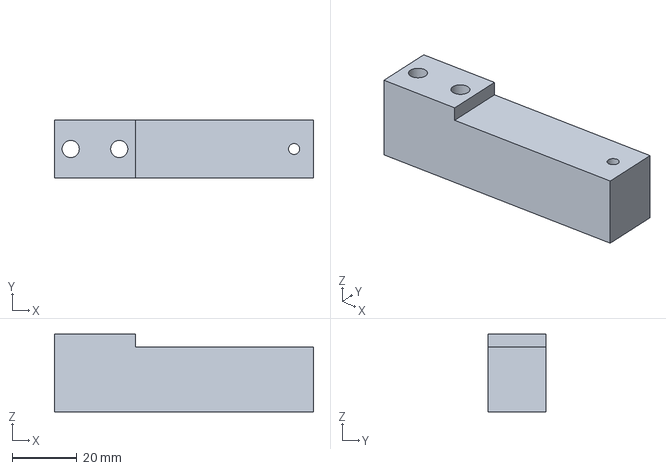
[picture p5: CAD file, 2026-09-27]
cad/export/terrasse_beam_hanger.step
80.0 x 18.0 x 24.0 mm

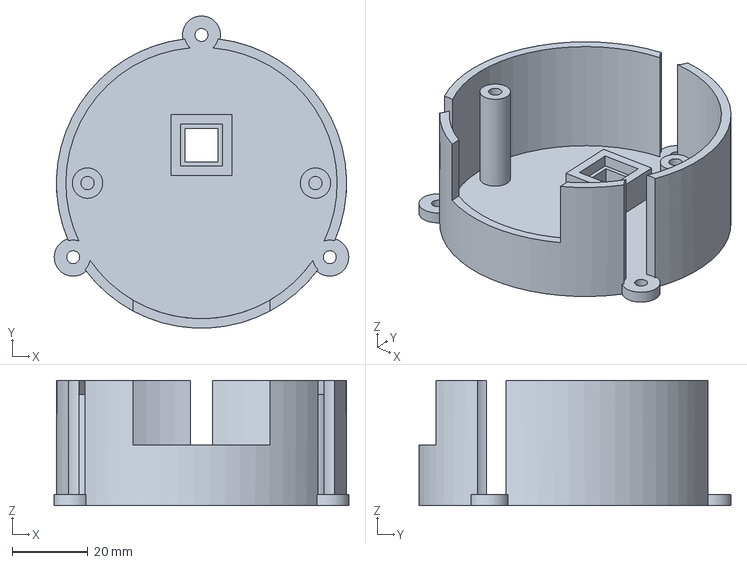
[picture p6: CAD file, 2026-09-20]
cad/export/wasserzaehler_cap.step
77.5 x 82.1 x 33.0 mm

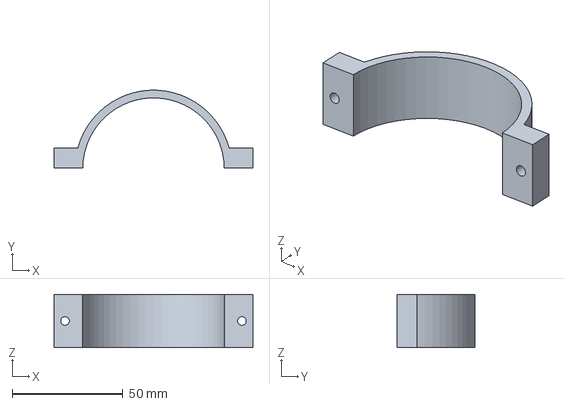
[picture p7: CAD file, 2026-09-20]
cad/export/wasserzaehler_strap.step
90.0 x 35.1 x 24.0 mm

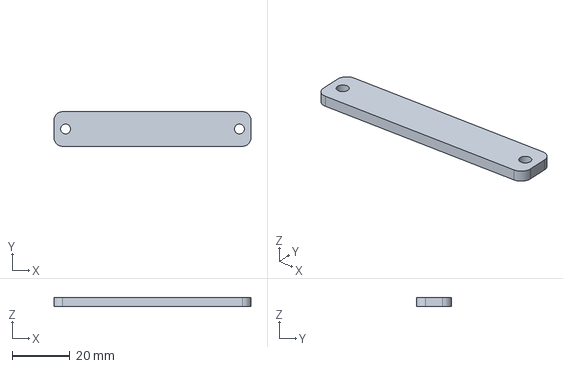
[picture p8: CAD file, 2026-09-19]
cad/export/wasserzaehler_bar.step
68.0 x 12.0 x 3.00 mm

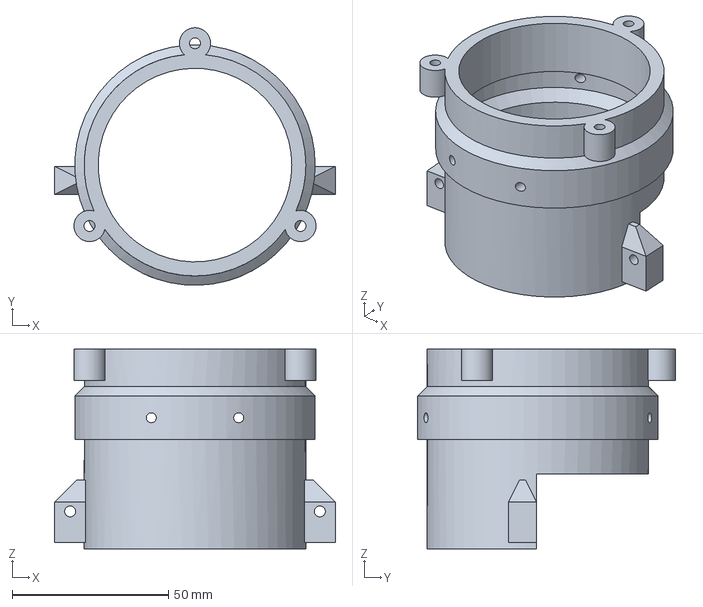
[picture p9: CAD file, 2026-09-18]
cad/export/wasserzaehler_tube.step
90.0 x 82.5 x 64.0 mm

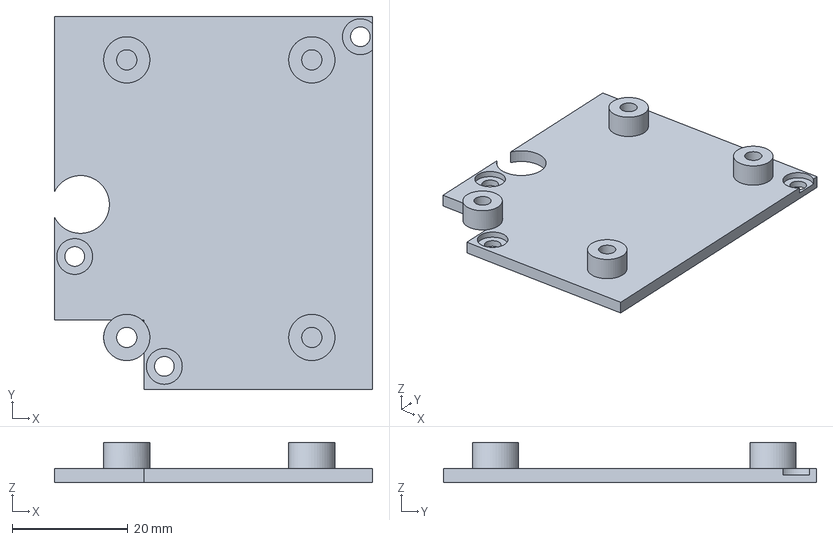
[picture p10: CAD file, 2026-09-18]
cad/export/terrasse_charger_tray.step
55.0 x 64.5 x 7.00 mm

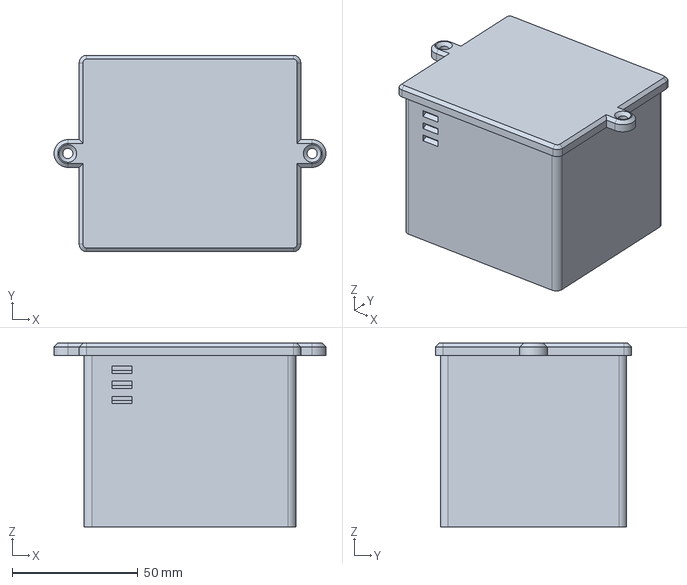
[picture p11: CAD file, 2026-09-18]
cad/export/terrasse_body.step
108.0 x 78.0 x 73.0 mm

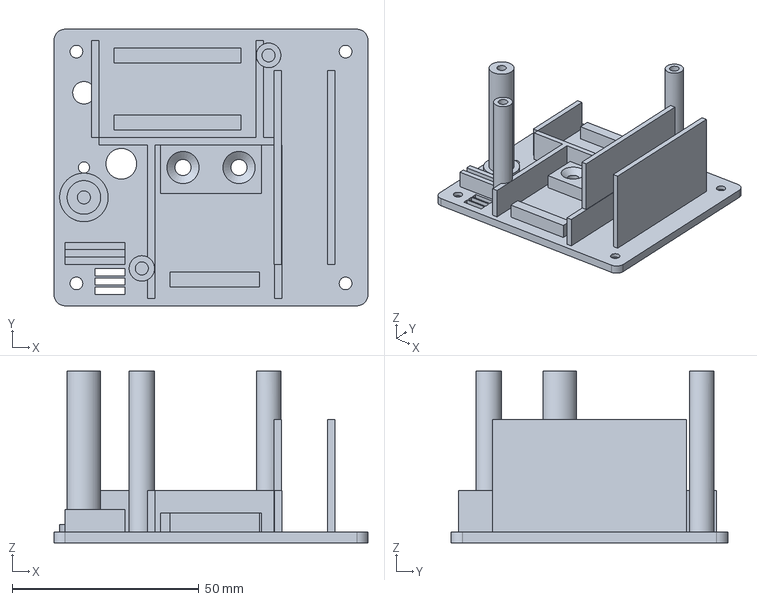
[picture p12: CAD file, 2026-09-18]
cad/export/terrasse_floor.step
84.0 x 74.0 x 46.0 mm

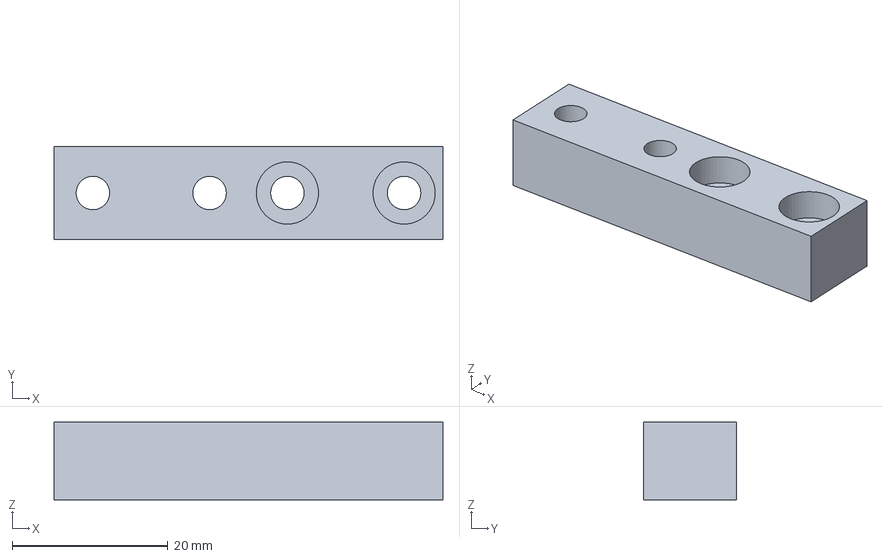
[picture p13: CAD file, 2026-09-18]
cad/export/terrasse_beam_spacer.step
50.0 x 12.0 x 10.0 mm

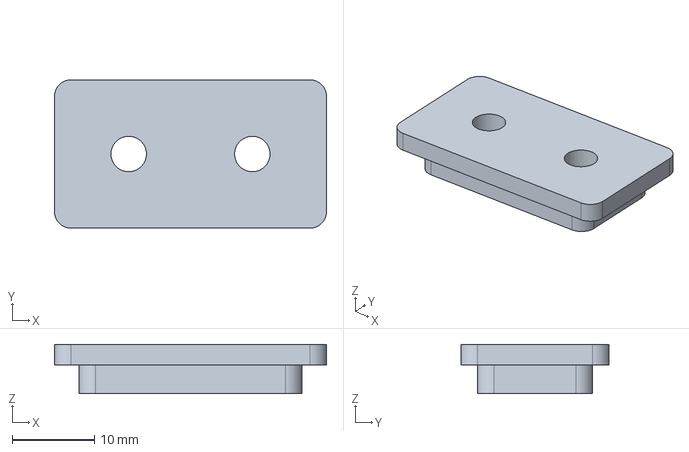
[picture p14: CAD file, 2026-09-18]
cad/export/terrasse_anchor.step
33.0 x 18.0 x 6.00 mm

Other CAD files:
cad/export/wohnzimmer_lid.step
cad/export/wohnzimmer_tray.step
cad/export/climate_lid.step
cad/export/climate_tray.step
cad/export/climate_lid.stl
cad/export/climate_tray.stl
cad/export/schlafzimmer_lid.stl
cad/export/schlafzimmer_tray.stl
cad/export/solarleuchte_body.stl
cad/export/solarleuchte_lid.stl
cad/export/terrasse_anchor.stl
cad/export/terrasse_beam_hanger.stl
cad/export/terrasse_beam_spacer.stl
cad/export/terrasse_body.stl
cad/export/terrasse_charger_tray.stl
cad/export/terrasse_floor.stl
cad/export/wasserzaehler_bar.stl
cad/export/wasserzaehler_cap.stl
cad/export/wasserzaehler_strap.stl
cad/export/wasserzaehler_tube.stl
cad/export/wohnzimmer_lid.stl
cad/export/wohnzimmer_tray.stl

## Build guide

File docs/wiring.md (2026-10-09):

# Wiring, per node

One firmware image, six different boards. What you solder depends on which
`NODE=` the board is going to be — this page has the complete wiring for each,
so you should not have to read the source to build one.

The pin assignments here are taken from the firmware
([`src/platform.rs`](../src/platform.rs) and [`src/main.rs`](../src/main.rs)); if
the two ever disagree, the source wins and this page is the bug.

> Every node on this page is built and running; what is actually on which
> board, and what went wrong building it, is in
> [commissioning.md](commissioning.md). Still check each connection against
> your own modules' silkscreen before powering anything up.
>
> `solarleuchte` is wired on its own page, [solarleuchte.md](solarleuchte.md):
> it is a rebuilt garden light rather than a sensor box.

## The board

Seeed Studio XIAO ESP32-C3. The silkscreen numbers the pads `D0`–`D10`, which
are *not* the GPIO numbers the datasheet and the firmware use:

| Pad | GPIO | Used for | On which node |
| --- | --- | --- | --- |
| D0  | 2  | HX711 SCK | `terrasse` |
| D1  | 3  | HX711 DT | `terrasse` |
| D2  | 4  | Battery divider tap (ADC1); a DS18B20 1-Wire line on a node that has one instead | `terrasse`, `solarleuchte` |
| D3  | 5  | UART RX ← SDS011 TX | `wohnzimmer` |
| D4  | 6  | I²C SDA | every node |
| D5  | 7  | I²C SCL | as SDA |
| D6  | 21 | — **console UART TX** | keep free |
| D7  | 20 | — **console UART RX** | keep free |
| D8  | 8  | LEDC → lamp MOSFET gate | `solarleuchte` |
| D9  | 9  | — **BOOT button** | keep free |
| D10 | 10 | UART TX → SDS011 RX | `wohnzimmer` |

`D6`/`D7` carry the log output. `D9` is the BOOT button, which the bootloader
samples at reset — pulling it low with your own wiring puts the board into
download mode instead of running the firmware. `GPIO0`/`GPIO1` are not broken
out on this board at all.

Power pads: `3V3` (regulated output, and also the input if you feed it from a
regulated supply), `5V` (tied to USB VBUS — an *output* when USB is plugged in),
`GND`, and `B+`/`B-` on the underside for a LiPo through the onboard charger.

## Rules that apply everywhere

- **One ground.** Every module's `GND` goes to the XIAO's `GND`. Sensors on
  their own supply still need their ground tied to the board's, or nothing
  works and the failure looks random.
- **3V3 unless stated.** Only the SDS011 wants 5 V.
- **Nothing above 3.3 V on a GPIO.** The ESP32-C3 is not 5 V tolerant.
- **Keep sensor leads short**, especially I²C. The bus runs at 100 kHz
  (`I2cConfig::default()`), which is forgiving, but 20 cm of unshielded ribbon
  next to a switching supply is not a bus.
- **Wire it with the board unpowered**, then plug USB in last.

---

## `NODE=bad` / `NODE=kueche` — SHT31-D only

The simplest build, and the right one to start with: four wires and one sensor.
If this works, the I²C half of every other node works.

Identical hardware; the two names differ only in which room they publish as.
Both are rooms that get wet on purpose, where the signal worth a long series is
the humidity and how long it takes to fall again after a shower or a pot.

> The kitchen carried the SDS011 particulate sensor until it moved to
> `wohnzimmer` — see that section for why, if you are looking at an older build
> or an older note.

**You need:** XIAO ESP32-C3, SHT31-D breakout, USB-C supply.

| SHT31-D pin | XIAO pad | GPIO | Note |
| --- | --- | --- | --- |
| VIN / VCC | 3V3 | — | |
| GND | GND | — | |
| SDA | D4 | 6 | |
| SCL | D5 | 7 | |
| ADDR | — | — | leave unconnected, see below |

**Address.** The firmware probes `0x44` (ADDR low) and `0x45` (ADDR high) and
adopts whichever answers, so you do not have to care which way your breakout
straps it — but you do have to leave the strap alone rather than floating it
against something. Most breakouts pull ADDR low on board.

**Pull-ups.** SDA and SCL need pull-ups to 3V3. Nearly every SHT31-D breakout
has them fitted (usually 10 kΩ); if yours does not, add 4.7 kΩ on each line.

**Power.** Mains — a USB-C phone charger. It samples every 120 s, and since
2026-09-13 it deep-sleeps in between rather than staying associated: the cable
means energy is free, but the heat is not, and this node has nothing to report
except the air it is sitting in. See `docs/base-platform.md`.

**Expected at boot** (`kueche` says `Küche` in place of `Bad`):

```
node 'bad' (Bad) booted, mains, duty-cycled profile
SHT31-D found at 0x44
SHT31-D: temperature = 21.4
SHT31-D: humidity = 48.2
```

If instead you get `no SHT31-D at 0x44 or 0x45`, the firmware immediately
sweeps the whole bus and tells you which of two very different problems you
have:

```
I²C scan: nothing answered between 0x08 and 0x77 — the bus itself is not working
```

means SDA and SCL swapped, no pull-ups, or the breakout not actually powered.
Whereas:

```
I²C scan: 0x76 answered
I²C scan: the bus works, so the missing sensor is at none of those addresses
```

means the wiring is fine and you have a different device fitted, or one that
straps its address somewhere unexpected.

---

## `NODE=schlafzimmer` — SCD41 **and** SHT31-D

The living room is this build plus a particulate sensor; everything in this
section applies there too, so read it first and then the `wohnzimmer` section
for what it adds.

> **Do not peel the white film off the SCD41's metal cap.** It is not a
> protective sticker or a shipping label — it is the gas-permeable membrane over
> the sensor opening, and it is part of the sensor. Removing it leaves the
> optical path exposed, and the sensor then answers every command perfectly
> while reporting `0 ppm` for ever. That failure cost a module on 2026-08-26 and
> looks exactly like a wiring or supply fault from the outside, so it is worth
> being sure: the film stays on.

**You need:** XIAO ESP32-C3, SCD41 breakout, SHT31-D breakout, USB-C supply.

### Why two sensors

The SCD41 has a temperature and humidity sensor built in, and it is the weaker
one. Sensirion specifies it at **±6 %RH** (±9 outside 15–35 °C / 20–65 %RH)
against the SHT31-D's **±2 %**, because it sits on a die that heats itself for
the CO₂ measurement. So the SHT31-D measures the room, and the SCD41 measures
CO₂ — plus its own temperature and humidity, which are published separately
under `scd41_` because you need them to calibrate its offset (below).

### Wiring

Both sensors share one I²C bus. Four wires leave the XIAO; both breakouts tap
them.

| Sensor pin | XIAO pad | GPIO | Note |
| --- | --- | --- | --- |
| VIN / VDD | 3V3 | — | see *Supply* |
| GND | GND | — | |
| SDA | D4 | 6 | both sensors in parallel |
| SCL | D5 | 7 | both sensors in parallel |

**Addresses** do not collide: the SCD41 is fixed at `0x62`, the SHT31-D sits at
`0x44` or `0x45` and the firmware adopts whichever answers. Nothing to strap.

**Pull-ups.** Both breakouts usually fit their own, which puts them in parallel:
two 10 kΩ become 5 kΩ, and even 2.2 kΩ against 10 kΩ lands near 1.8 kΩ. That is
still inside the 3 mA sink current the SCD4x datasheet guarantees its low level
for, so leave both fitted and only unsolder one set if the bus actually
misbehaves.

**Supply — and this is the one place the topology matters.** The SCD41 draws
175 mA typical, 205 mA maximum while its IR source fires, against microamps
between measurements. Sensirion allows **30 mV** of ripple at the sensor, which
over a 205 mA pulse is a total resistance budget of about **146 mΩ** — for the
regulator, both leads, and every contact on the way. Four DuPont contacts alone
eat most of that, which is why this node wants soldered joints rather than
jumper headers. Ten centimetres of 26 AWG is only ~27 mΩ for the pair, so length
is cheap and distance from the board is affordable.

Run 3V3 and GND from the XIAO **directly to the SCD41** as their own pair rather
than daisy-chaining its supply through the SHT31-D breakout — that would put
extra pads and contacts in the path that carries the pulse. The SHT31-D draws
almost nothing and may branch off anywhere. SDA and SCL carry milliamps, so
those can be looped through in any order.

```
XIAO   3V3 ─────────────────► SCD41 VDD      own pair, short, soldered
       GND ─────────────────► SCD41 GND
        └┬─────────────────► SHT31 VIN       may branch off
         └─────────────────► SHT31 GND

       D4  ──┬─────────────► SCD41 SDA       bus, order irrelevant
             └─────────────► SHT31 SDA
       D5  ──┬─────────────► SCD41 SCL
             └─────────────► SHT31 SCL
```

### Placement

**Both sensors in the same air, both away from the board.** Same air, because
the offset calibration below is the difference between their two temperatures —
mount them next to each other or it measures nothing useful. Away from the
board, because Sensirion's design-in guide names the Wi-Fi module explicitly as
a heat source and asks for maximum distance from self-heating components; a
fixed offset cannot compensate a heat source that varies with radio traffic.

Otherwise as for any air sensor: not inside a sealed enclosure, not where
someone breathes directly on it. The SCD41's automatic self-calibration assumes
the room reaches roughly outdoor CO₂ at some point in a week — a room that is
never aired will drift.

**Power.** Mains, always on. The firmware runs the SCD41 in *periodic* mode on
mains, which is what its self-calibration expects, and samples every 60 s.

### Expected at boot

```
node 'schlafzimmer' (Schlafzimmer) booted, mains profile
SHT31-D found at 0x44
SCD41 found at 0x62
SCD41 serial 0x41AC3D073BD4
```

The serial number is worth a glance. It identifies the physical sensor, and it
is the cheapest counterfeit check available — the SCD4x is widely copied, and
fakes tend to answer with zeroes or with the same number on every unit, which
the firmware calls out. Two genuine modules must return different numbers.

The **first SCD41 round after a power-up reports nothing** — the first
conversion needs about five seconds and the firmware does not block the publish
path waiting for it. Readings appear on the next round:

```
SHT31-D: temperature = 26.3
SHT31-D: humidity = 52.9
SCD41: co2 = 367
SCD41: scd41_temperature = 26.6
SCD41: scd41_humidity = 55.9
```

### Calibrating the temperature offset

The SCD41 cancels its own self-heating with a temperature offset, 4 °C out of
the box — a figure chosen for continuous operation in a particular enclosure,
not for yours. It is not cosmetic: the humidity output is compensated to the
offset-corrected temperature, so an offset that does not match the real
self-heating skews **both** signals, temperature low and humidity high. The
datasheet only claims its RH/T accuracy if the offset is set correctly.

Do this once per node, after the sensors are mounted where they will live:

1. Let it run **at least 15 minutes** in place. Sensirion asks for that much for
   complete thermal equilibration, and the reading really does still drift for
   the first several minutes.
2. Read `temperature` (the SHT31-D) and `scd41_temperature` off the device card.
3. New offset = `4.00 + (scd41_temperature − temperature)`, i.e. subtract however
   much the SCD41 reads *colder* than the reference.
4. Enter it in the **Temperatur-Offset** number entity on the node's device card.

The value is written to the sensor on the next round — which costs one round,
because applying it stops and restarts the measurement. It is deliberately not
persisted to the sensor's own EEPROM (limited write cycles); the firmware keeps
it in flash and reprograms it on every boot.

Calibrate in the final position and enclosure. On a bench, dangling off a USB
cable, the self-heating is different and so is the answer.

### If something is wrong

`no SCD41 at 0x62` or `no SHT31-D at 0x44 or 0x45` — read the bus scan that
follows it, same two cases as for the SHT31-D-only node above.

If a sensor is *found* but produces no readings, the log says where it fell
over rather than just "not responding": whether it refused to start, never
reported a ready measurement, answered with a bad CRC, or returned a well-formed
measurement it considers invalid (`reported 0 ppm`). After three empty rounds
the firmware runs the SCD41's built-in self test, which settles the only
question that matters:

```
SCD41 self test reports a malfunction — the part itself is faulty
SCD41 self test passed — the sensor believes it is healthy, so look at
wiring, supply or placement rather than the part
```

---

## `NODE=wohnzimmer` — SCD41, SHT31-D, SDS011 **and** SGP41

The busiest mains node, and the only one on two buses at once. Build the
`schlafzimmer` node above first — the I²C half is identical, down to the
membrane warning and the supply budget — and then add the SDS011.

**You need:** everything the bedroom node needs, plus an SDS011 and a USB-C
supply that can spare ~100 mA more for its fan.

### Why the particulate sensor is here and not in the kitchen

The kitchen is where the particulates come from, which makes it the obvious
place and the wrong one.

The SDS011 is a nephelometer: an open optical path with a fan pulling room air
through it. Kitchen air carries fat aerosol from frying, and that films the
optics and the fan blade. The sensor does not fail when this happens — it keeps
answering, with a calibration that has quietly walked off. That is the same
shape of failure as the SCD41's membrane, and it is the expensive one, because
nothing in the log says it is happening.

The second reason is that the interesting question is answerable here and not
there. That frying makes smoke is not worth a year of data. How much of it
reaches the room people sit in, and how long it takes to clear, is — and it is
the number an automation can act on.

It also lands where an SHT31 already is, which is what makes the humidity
correction below possible at all.

### SDS011 → XIAO

| SDS011 pin | XIAO pad | GPIO | Direction |
| --- | --- | --- | --- |
| 5V | 5V | — | supply |
| GND | GND | — | |
| TXD | D3 | 5 | sensor → board |
| RXD | D10 | 10 | board → sensor |
| 1µm / 2.5µm | — | — | leave unconnected |

**Crossed, not straight.** The sensor's TX goes to the board's RX and vice
versa. Getting this backwards is silent: no error, just no frames.

**The 5V pad is USB VBUS**, so this node only works while it is plugged into
USB — which it is, being a mains node. If you power the XIAO from a regulated
3V3 supply instead, the `5V` pad gives you nothing and the SDS011 needs its own
5 V source (with the grounds tied together).

**Logic levels.** The SDS011's UART is 3.3 V logic despite the 5 V supply, so no
level shifter is needed in either direction. This is what the module's datasheet
states; if you have a meter, confirming TXD idles at ~3.3 V and not ~5 V before
connecting it to D3 costs a minute and could save the pin.

**Nothing shared with the I²C sensors** but the supply rails. Keep the SDS011's
own 5V/GND pair away from the run that feeds the SCD41, which has a 146 mΩ
budget of its own (see the bedroom section) and does not want a fan's current
steps in it.

### Fan life, and the two cadences

The fan and laser are rated around 8000 hours, so the firmware keeps them asleep
and wakes them only to measure. On this node that matters more than it used to,
because the SCD41 beside it wants a reading a minute and the SDS011 must not
have one.

So the node has a **base round of 60 s** — the SCD41's and the SHT31's cadence —
and the SDS011 sits out fourteen of every fifteen of them, giving it one round
every 15 minutes. That is `Slot::every(900)` in
[`src/node.rs`](../src/node.rs); Home Assistant is told about both cadences
separately, so the PM entities are not marked stale during the fourteen minutes
they are legitimately quiet.

Do not "helpfully" leave the fan running.

### Humidity correction

A nephelometer infers mass from scattered light. Above roughly 60 %RH
hygroscopic particles take up water and scatter like something bigger than
their dry selves, so the reported mass runs high — steeply so as the air
approaches saturation. Without a humidity figure you cannot tell a dusty room
from a damp one.

Because this node has an SHT31, the firmware corrects for it, using the
κ-Köhler growth factor:

```text
C_dry = C_wet / (1 + κ · (RH/100) / (1 − RH/100))
```

Both values are published: `pm25` / `pm10` are corrected — build automations on
those — and `pm25_raw` / `pm10_raw` are what the sensor actually said. You need
the pair to judge the correction, exactly as you need `scd41_temperature` to
judge the CO₂ sensor's offset.

**κ is a property of your air, not of the sensor.** Published values run from
about 0.25 to 0.62 for ambient aerosol; indoor aerosol sits at the low end, so
the default is **0.25** — a starting point, not a calibration. It is a slider in
Home Assistant (*Feuchte-Korrektur κ*, `smarthome/wohnzimmer/config/sds011_kappa`):
watch corrected against raw over a few humid days and move it. Setting it to `0`
turns the correction off and leaves both entities in place.

Two limits worth knowing. Above **95 %RH** the correction is capped — the growth
factor has a pole at 100 %, and air that wet is fog, where the model's premise
has stopped holding anyway. And if the SHT31 does not answer in a round, only
the raw values are published; the corrected ones expire rather than being
quietly filled with uncorrected numbers.

### Placement

The I²C pair goes as in the bedroom section. The **SDS011 belongs next to the
SHT31**, close enough that the humidity it is corrected against is the air it
actually sampled — that is what makes the correction mean anything.

Beyond that: airflow in and out unobstructed, and the sensor must stay dry.
Condensation ruins both the reading and the hardware.

### Expected at boot

```
node 'wohnzimmer' (Wohnzimmer) booted, mains profile
wifi: 'your-network' (built in)
SHT31-D found at 0x44
SCD41 found at 0x62
SCD41 serial 0x4E7003073BC3
Sgp41 found at 0x59
SGP4x serial 0x000005A5F259
```

`Sgp41` and not `Sgp40` on that line matters: the two parts share the address
and most of the command set, and only the SGP41 has a NOx channel. The driver
asks once and remembers, so a board that turns out to carry an SGP40 publishes
one index instead of two rather than inventing the second.

Nothing about the SDS011 — it is only touched on a round of its own. What you
should *not* see is:

```
SDS011 UART init failed: ...; sensor disabled
```

which means the UART could not be configured at all — a build or pin problem,
not a wiring one. A sensor that is wired wrong instead shows up, once every 15
minutes, as:

```
SDS011 not responding; skipping its readings
```

A working PM round takes 10–30 s from the fan starting, then:

```
SDS011: pm25_raw = 24.5
SDS011: pm10_raw = 100.0
SDS011: pm25 = 18.1
SDS011: pm10 = 74.1
```

The corrected values being *below* the raw ones is the expected direction: the
correction only ever removes water, never adds particles.

### SGP41 → XIAO

The gas sensor joins the I²C bus the other two are already on. Nothing is
strapped and nothing collides: the SCD41 is fixed at `0x62`, the SHT31-D sits at
`0x44`/`0x45`, the SGP4x at `0x59`.

| SGP41 pin | XIAO pad | GPIO | Note |
| --- | --- | --- | --- |
| VDD | 3V3 | — | see *Supply* below |
| GND | GND | — | |
| SDA | D4 | 6 | third device on the bus |
| SCL | D5 | 7 | |

**Supply.** The part heats a metal-oxide plate, and that is the whole current
budget: about 50 mA while the hotplate pulse runs, a few microamps between. At
one sample a second the average lands near 3 mA, so it changes nothing on a
mains node — but it is a pulsed load on the same 3V3 the SCD41 pulses on, and
the SCD41's ripple budget is tight (see the bedroom section). Give it its own
short pair back to the XIAO rather than daisy-chaining it through the SCD41's.

### Why the gas sensor is on this node

Because it is the only one that can sample it correctly. What the SGP4x returns
is a hotplate resistance, comparable only while the heater keeps running, and
Sensirion's index algorithm is specified for a 0.5–10 s interval. The firmware
ticks it **once a second** between publish rounds (`GAS_STEP_INTERVAL` in
`main.rs`). A battery node is asleep between rounds and could not do that at
all; a node sampled once a minute would publish a number that looks like a VOC
index and is not one.

The second reason is the same as the SDS011's: this is the room people sit in,
and a VOC index is a statement about the air they are in.

### What the index is, and is not

1 to 500, where **100 is the running average of roughly the last 24 hours in
this room**. It is not a concentration: there is no µg/m³ and no ppb behind it,
because a metal-oxide film responds to a mixture and the same resistance can
mean very different mixtures. What it is good for is *change* — cooking,
cleaning products, a room that has not been aired — against this room's own
recent normal.

That also means a fresh boot has nothing to say for about a minute: ten
conditioning steps, then the algorithm's 45-second blackout, and only then does
`voc_index` appear in a publish. Silence in that window is the sensor working.

**NOx will read its floor indoors, more or less for ever.** NOx comes from
combustion; a flat NOx index is the channel working, not failing.

### When the gas sensor goes quiet

A bus scan is not the answer here, and on 2026-09-13 it was actively
misleading: the scan found `0x59`, so the part was on the bus and powered, and
it answered no command at all. "The sensor is missing" and "the sensor is there
and has stopped talking" look identical from a scan.

What tells them apart is how far a command got, and the driver now says which of
the three it was:

| Log line | What it means | Where to look |
| --- | --- | --- |
| `refuses every measure command at 0x59` | the write was not acknowledged | the part itself, or a stuck state — a **power cycle** clears the second and not the first |
| `takes a measure command at 0x59 and then returns nothing` | the write landed, the read did not answer | the part or its supply, not SDA/SCL |
| `answers at 0x59 with a failed checksum` | bytes arrive and are corrupted | contacts, bus length, a marginal jumper |

Two habits are worth having with this node. **A reset is not a power cycle**:
`espflash monitor` and a reflash both restart the MCU while the sensors keep
their 3V3, and a Sensirion part left part-way through a command answers its
address for ever after while refusing every command — the SHT31-D did exactly
that for three rounds until the board was actually unplugged. And **a sensor
that has stopped answering is no longer asked every second**: after ten
consecutive failures the driver drops to one attempt a minute (see
`sgp41::Cadence`), so a dead part stops competing for the bus with the ones that
still work. It goes back to 1 Hz the moment one attempt succeeds.

---

## `NODE=terrasse` — the bird scale

The busiest board: two sensors, two buses, a battery and the only analogue
measurement in the fleet. This is the one that already exists; the others are
simplifications of it.

**You need:** XIAO ESP32-C3, 1 kg straight-bar load cell, HX711 breakout,
SHT31-D breakout, 1S protection board, two 100 kΩ resistors, one 100 nF
capacitor, LiPo cell.

### Load cell → HX711

The four leads go to the HX711's **input** side. Colours follow the common
straight-bar convention — check against your cell's own datasheet, they vary.

| Load-cell lead | HX711 pin | Meaning |
| --- | --- | --- |
| Red | E+ | excitation + |
| Black | E− | excitation − |
| Green | A+ | signal + |
| White | A− | signal − |

If loading the pan makes the reading go *down*, swap A+ and A−.

### HX711 → XIAO

| HX711 pin | XIAO pad | GPIO | Direction |
| --- | --- | --- | --- |
| VCC | 3V3 | — | |
| GND | GND | — | |
| SCK | D0 | 2 | board → amp |
| DT | D1 | 3 | amp → board |

`DT` is configured with the internal pull-up on, so a *disconnected* amplifier
reads as permanently "not ready" and times out cleanly instead of feeding you
floating garbage. That is deliberate: a scale reading nonsense is worse than one
reading nothing.

### SHT31-D → XIAO

Exactly as for `NODE=bad`: 3V3, GND, SDA→D4, SCL→D5.

On this node the SHT31-D publishes the plain `temperature` and `humidity` keys.
Under its old name, `draussen`, it used `air_temperature` / `air_humidity` to
leave the plain keys to a DS18B20; the prefix went with the rename to
`terrasse`, so history before that sits under the old entities.

### No DS18B20 on this node

The probe used to sit on D2 with a 4.7 kΩ pull-up. The battery divider below
needs the same pad, and there is no second candidate (see *Battery sense*), so
the probe came off. If you are rebuilding an older board: **remove the 4.7 kΩ**,
or it will pull the divider's tap towards 3V3 and every voltage reading with it.

The DS18B20 driver and its node slot are still in the firmware — the pin is a
per-node choice, and the build fails if any node ever enables both. For a node
that takes the probe instead of a divider:

| DS18B20 lead | XIAO pad | GPIO | |
| --- | --- | --- | --- |
| Red (VCC) | 3V3 | — | |
| Black (GND) | GND | — | |
| Yellow (DATA) | D2 | 4 | 1-Wire, **4.7 kΩ pull-up to 3V3** |

The internal pull-up is enabled as a backup, but over a ~1 m cable the external
one is required. The ~750 ms conversion only runs on publishing rounds, never on
an idle poll.

### Power

A LiPo on `B+`/`B-` through the XIAO's onboard charger. This is the only battery
node: it cold-boots out of deep sleep every couple of seconds, reads the load
cell, and only brings up Wi-Fi when there is weight on the pan or the heartbeat
is due.

Two consequences for how you build it:

- **The 5V pad is dead** on battery, which is why the SDS011 is not on this node.
- **Keep the sensors on 3V3 from the XIAO**, so they go down with it in sleep.

Recharging means opening the box and spending another cycle on a USB port that
has already failed once out there. Fitting a panel instead — which panel, which
charger, and why not the XIAO's own — is worked out in [solar.md](solar.md).
None of it is built.

#### Protection board

The XIAO charges the cell but does **not** protect it: there is no low-voltage
cutoff, so a flat battery keeps being drained until it is damaged. Unless your
pack already has a protection PCB tucked under the tape at the tab end — many
do — put a 1S board inline between the cell and the board.

```
LiPo  +  ──►  B+  ┌──────────────────┐  P+  ──►  XIAO  B+
                  │  1S protection    │
LiPo  −  ──►  B−  └──────────────────┘  P−  ──►  XIAO  B−
                      (B = battery)        (P = load)
```

**Read the silkscreen before soldering.** Plenty of 1S boards expose only three
pads — `B+`, `B-`, `P-` — because the positive rail passes straight through and
the MOSFETs switch the *negative* side. On those, the XIAO's `B+` comes from the
board's `B+` and only the negative goes through `P-`. Both layouts are fine;
wiring one as though it were the other is not.

Solder the board to the cell first (`B-`, then `B+`), insulate it, and only then
run the load wires to the XIAO — a bare 2000 mAh pouch will deliver tens of amps
into a slipped iron. Nothing on the XIAO side has reverse-polarity protection.

What such a board does **not** do is keep the cell healthy. The common DW01A-class
part cuts off around 2.4-2.5 V, far below the ~3.0 V where a LiPo starts losing
capacity for good. It is a safety device against fire and deep-discharge damage,
not a longevity one. Noticing the difference is what the divider below is for.

#### Battery sense

**The XIAO has no battery-sense path at all** — `B+` reaches the charger and the
regulator, never an ADC — so reading the cell means fitting a divider:

```
  XIAO B+ (= P+)
        │
      [ R1 ]  100 kΩ
        │
        ├──────────────────►  D2 / GPIO4
        │
        ├────────┐
        │        │
      [ R2 ]   [ C ]
      100 kΩ   100 nF
        │        │
  XIAO GND ──────┴───────  (= P−)
```

As a netlist, which is harder to misread than any diagram:

| Part | From | To |
| --- | --- | --- |
| R1 100 kΩ | XIAO `B+` | node **A** |
| R2 100 kΩ | node **A** | XIAO `GND` |
| C 100 nF | node **A** | XIAO `GND` |
| wire | node **A** | XIAO `D2` |

Node **A** is the tap: four legs meet there, and the two resistors are always in
series between `B+` and ground — never a bridge across one of them.

**Why D2, and why it costs the probe its pin.** The divider needs an ADC1 input.
On the ESP32-C3 those are GPIO2/3/4 = `D0`, `D1`, `D2`, and the HX711 has the
first two. `D3` is on ADC2, which is unusable while Wi-Fi is up, so `D2` is the
only candidate — and the DS18B20 wanted it. The SHT31-D measures air temperature
anyway. `node.rs` fails the build if a node ever asks for both.

**Why the foot goes to `GND` and not to the cell.** The XIAO's ground is the
protection board's `P−`, the switched side. Tie the divider there and the
low-voltage cutoff switches it off along with everything else; tie it straight to
the cell's `B−` and it keeps drawing ~21 µA *after* the cutoff — exactly the deep
discharge the board was fitted to prevent.

**Numbers.** 4.2 V full becomes 2.1 V at the pin, 3.0 V empty becomes 1.5 V; both
sit inside the ~2.5 V that 11 dB attenuation spans, with no over-range while
charging. The 100 nF supplies the ADC's sampling charge, so the 50 kΩ source
impedance does not skew the reading. Standing draw is ~21 µA, about 184 mAh a
year — roughly 9 % of a 2000 mAh pack. Two 1 MΩ resistors would cut that to ~2 µA
if it ever matters.

Use 1 % metal film. The firmware calibrates the *ADC* against the chip's eFuse
reference, so readings arrive in millivolts already corrected for that part — but
nothing corrects the resistors. If a multimeter disagrees, the fix is
`R_TOP_KOHM` / `R_BOTTOM_KOHM` in [`src/battery.rs`](../src/battery.rs) and a
reflash; there is no runtime knob for it yet.

The reading is published as `smarthome/terrasse/battery_voltage`, and the log warns
below 3.0 V. A reading under 2.0 V is not published at all — that is not a flat
cell, it is a divider that is not there, and it says so:

```
battery reads 41 mV, which is no cell at all — check the divider is fitted
between B+ and GND with its tap on D2, and that a cell is connected
```

### Outdoors

Nothing on this node is waterproof, so all of it needs an enclosure — but the
SHT31-D needs to *breathe*, or it reports the humidity of the inside of your box.
A vent with a membrane, or a shielded underside opening, not a sealed lid.

**Expected at boot:**

```
node 'terrasse' (Terrasse) booted, battery profile
provision topic: smarthome/provision/a1b2c3d4e5f6
SHT31-D found at 0x44
HX711 raw reading: 8402913
battery = 4.03 V
```

The node's build-time name and its id are the same string, `terrasse`, as they
are for every node in the fleet. That was not always so: this node answered to
`draussen` while its id — and so its topics — said `scale`, a leftover from
before the fleet existed. Provisioning still compares by **id** rather than by
name, so the two are free to diverge again without a board re-provisioning
itself in a loop.

---

## Which pads stay free

Useful if you want to add something, or are checking you have not double-booked
a pin:

| Node | Free pads |
| --- | --- |
| `bad`, `kueche` | D0, D1, D2, D3, D8, D10 |
| `schlafzimmer` | D0, D1, D2, D3, D8, D10 |
| `wohnzimmer` | D0, D1, D2, D8 |
| `terrasse` | D3, D8, D10 |
| `solarleuchte` | D0, D1, D3, D10 |

`D6`, `D7` and `D9` are excluded everywhere: console UART and the BOOT button.

## Before you power it up

1. Continuity from every module's GND to the XIAO's GND.
2. No 5 V anywhere near a GPIO — only the SDS011's supply pin.
3. SDA and SCL not swapped (the single commonest mistake on these boards).
4. SDS011 TX→RX crossed.
5. On `terrasse`: the divider's foot on the XIAO's `GND` (the protection board's
   `P−`), not on the cell's `B−` — and no 4.7 kΩ left over from a DS18B20 on D2.

Then plug in USB and watch the log — every node reports what it found on its
buses within the first second of booting, which is precisely so that a wiring
mistake is visible before the first reading is even attempted. See
[flashing.md](flashing.md) for getting the firmware onto the board, and
[the platform notes](base-platform.md) for why the fleet is shaped this way.

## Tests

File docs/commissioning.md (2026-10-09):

# Commissioning log

What is physically built, on which board, and what still has to happen to it.

The rest of `docs/` describes how the firmware is *meant* to work. This page
records the state of the actual hardware, which nothing in the code can tell
you: a node's slot being `Slot::on()` says a sensor is expected, not that one
is soldered on.

Keep it honest rather than complete. A stale entry here is worse than a missing
one, because it will be believed.

---

## Boards

Identified by the MAC in the USB serial descriptor, which is also what
`espflash board-info` reports. **Check it before flashing.** Two boards were
plugged in at once during the 2026-09-04 session and the wrong one got written;
the MAC is the only thing that distinguishes them, and reading it takes a
second.

| MAC | Node | Power | Address |
| --- | --- | --- | --- |
| `e0:72:a1:18:e2:c0` | `terrasse` | battery | 192.168.1.81 |
| `ac:27:6e:80:51:f8` | `wohnzimmer` | mains | 192.168.1.87 |
| `ac:27:6e:82:43:94` | `kueche` | mains, duty-cycled | 192.168.1.30 |
| `ac:27:6e:7e:10:a0` | `schlafzimmer` | mains | 192.168.1.72 |
| `ac:27:6e:7f:a6:b4` | `bad` | mains, duty-cycled | 192.168.1.143 |

Complete as of 2026-09-10: the last two were read off `espflash board-info`
during the RSSI rollout, so every board in the fleet is now identifiable
without opening anything. The addresses were filled in on 2026-09-17 from the
nodes themselves — since that evening each one publishes its MAC and address
retained, so this table can be checked against reality rather than trusted:

```bash
mosquitto_sub -h <broker> -u <user> -P <pass> -t 'smarthome/+/meta/board' -v
```

---

## `terrasse` — outdoor, battery

Replaced the node formerly called `draussen`. It carries the bird-feeder scale.

**Verified on hardware 2026-09-04:**

- **HX711** on `D0`/`D1`. Resting readings scatter about ±70 counts out of a
  ±8.4M range — a clean, low-noise chain. A press produced a real presence
  edge: `visit` is published only on the arrival path, so seeing it proves the
  threshold crossing fired and `watch_visit` ran through the press.
- **SHT31-D** at `0x44`, no prefix — it owns the plain `temperature` and
  `humidity` keys.
- **Battery divider** on `D2`, reading 4.11 V off the XIAO's charger with no
  cell fitted. That is the check worth doing before connecting a LiPo: it
  proves the divider is wired and scaled while nothing is at stake.

**Verified on hardware 2026-09-06:**

- **The cell is connected and the node runs on it.** With USB unplugged it
  keeps publishing, `battery_voltage` included, which is the only proof that
  matters — the divider sits on the rail the charger drives, so a reading near
  4.1 V with USB attached is indistinguishable from the 4.11 V measured above
  with no cell at all.
- **It charges.** 3.80 V before a short USB session, 3.93 V after.

**Verified on hardware 2026-09-10 — the scale is calibrated:**

- **Zero taken in the working position**, hanging outdoors with the bird house
  fitted and empty. The mount's own load, the cord tension and the beam's
  orientation all enter the raw value, so a zero taken on the desk would carry
  that whole difference as a standing error. Residual reading afterwards:
  0.5–2.1 g, about a thousandth of the calibration mass.
- **`scale_factor` = 1862.8 ticks/g**, from 545 g of known mass reading 2417.2
  with the placeholder 420 still in place. Verified by the same mass reading
  **545.2 g** afterwards — 0.04 % out.
- **The bird house and mount weigh 451 g**, which is what the +1999 g jump on
  hanging it works out to once the factor is right. Worth writing down as the
  sanity check it is: an implausible number here means the factor is wrong.
- **The threshold was too sensitive, not too coarse.** With the placeholder
  factor, `threshold_grams: 10.0` amounted to `10 × 420 / 1862.8` ≈ **2.3 g** of
  real mass. That, not a mechanical fault, is what had the node publishing
  visits all day against an uncalibrated scale.

### Taring takes its own readings

Since 2026-09-13 a tare **measures**: the press is noticed while the node is
draining retained config, and once that round is over — back where the load cell
is reachable — it takes `presence::TARE_SAMPLES` readings, about 1.6 s at the
cell's ~10 SPS, and adopts their **median** as both the gram zero and the
presence baseline. If the readings spread more than `TARE_MAX_SPREAD` ticks it
refuses, says so, and leaves the old zero standing; press it again once things
are still.

The median is there because the press arrives retained and is acted on whenever
the node next wakes, which nothing stops a bird from coinciding with. A landing,
a hop or a gust occupies a minority of the window and the median ignores it. A
bird that sits *still* through the whole 1.6 s is not caught and cannot be — no
measurement taken at tare time can tell that weight from the feeder's own. That
one is yours to avoid, which is why the window is short enough to stay inside
"I am looking at it".

**What this replaced, and why it is worth knowing.** `Config::apply` used to set
`offset = tare_ref`, and `main` passed `state::baseline()` — the drift-tracked
presence baseline, not a reading taken when the button was pressed. That made
taring inherit every problem the baseline had:

- *You had to wait for the baseline to catch up.* Hanging the house is a load
  far above the threshold, so the node read `Arrived`/`Staying` and only
  absorbed it once `STUCK_AFTER_SECS` (600 s) had passed. Taring before that
  copied a stale zero.
- *Removing a calibration mass left the baseline stuck.* Once absorbed, taking
  the mass off is a large negative delta, which `decide` classifies as
  `Unexplained` — deliberately leaving the baseline alone, with nothing to ever
  move it back. Taring then copied the mass-inclusive value and showed roughly
  minus its weight. The same trap caught any remount that did not reproduce the
  beam's preload.
- The documented way out was to raise `threshold` until the step fell inside the
  drift band (`threshold/4`) — 3000 g for a 545 g mass — wait for the `Quiet`
  drift to pull the baseline back, then set it to 10 g again. The arithmetic
  still holds if you ever need it: the drift keeps 15/16 of the error per 2 s
  round, so 600 s is 300 rounds and `(15/16)^300 = 3.9e-09`, leaving 0.004 ticks
  of 1 015 226. You should not need it. A tare now writes the baseline itself,
  which is the same escape in one button press.

The firmware accepts any finite `threshold ≥ 0` over MQTT; the 500 g maximum is
only the Home Assistant slider's.

**Checking whether a tare worked, without being fooled twice.** Both mistakes
below were made on 2026-09-24 and each produced a confident wrong answer.

The round that *consumes* the press still carries the old zero. `publish()`
sends the samples first and only then re-zeroes:

```rust
let drained = connect_and_publish(...).await;
let updated = if drained.tare { retare(board, drained.cfg).await } else { drained.cfg };
```

So the reading that arrives alongside the press being cleared is the pre-tare
one, and reading it as "still not zero, so it was refused" is wrong. **Check the
round after that.**

And a refused tare is silent from outside. The retained press is cleared whether
or not the readings settled, so a press made while the feeder swings is spent
for nothing; only the serial log says why. `TARE_MAX_SPREAD` is 2000 ticks,
which at `terrasse`'s 1862.8 ticks/g is **1.07 g** across the sixteen samples —
tight enough that a feeder still moving will not pass. Wait until consecutive
published weights agree to a few grams over half an hour; by then the 1.6 s
window is easily still enough.

### The zero moves with temperature, and the coefficient is positive

Measured on `terrasse` across three days and both directions:

| When | Direction | Coefficient |
| --- | --- | --- |
| 2026-09-22 evening | cooling | 9.9 g/K |
| 2026-09-23 morning | warming | 8.6 g/K |
| 2026-09-24 midday | cooling | 8.6 g/K |

Both branches agree to 15 %, which is what says a single linear factor is the
right model and hysteresis is not worth carrying. `temp_coeff` was set to
**8.6** on 2026-09-24 at 15:00, against a tare anchor of 17.5 °C taken at 13:32.

**The sign is the part to get right**, and it is *not* the direction the zero
drifts. This mount's zero falls as it cools, but the coefficient describes the
correction that cancels that, and `drift_ticks` subtracts:

```
kelvin = air − tare_temp          → negative when cooling
drift  = kelvin × coeff × scale   → negative for a positive coeff
raw − drift                      → adds back what the cooling took
```

A negative coefficient would double the error instead of removing it, and
nothing in the published numbers would say so until a cold night.

**Fit it from two quiet points hours apart, not from a transient.** The SHT31
measures air and settles in seconds; the beam and its PLA clamps lag it. Bringing
the node from 22 °C indoors to 16.6 °C outdoors, the air stopped falling at
12:26 while the weight kept moving for another forty minutes — 7.0 g, then 4.6,
2.8, 1.6. A coefficient fitted inside that window comes out far too large.

### The socket is wired with the colours crossed, and that is correct

On this pigtail, **black goes to `B+` and red to `B−`.**

That looks wrong and is not. The JST-PH housing is keyed, so the cell's plug
mates one way only; what is *not* standardised is which contact of the housing
carries positive. This pigtail was made with the opposite convention from the
cell's plug, so matching the colours at the solder joints would have mated them
backwards. **Decide this by continuity and a voltmeter, never by wire colour** —
probe which socket contact reaches `B+`, then check the cell's plug puts red on
that contact.

### A reversed cell reads exactly like a broken divider

It was mated backwards the first time. Nothing was damaged and the cell stayed
cold, but the failure was thoroughly misleading and cost an evening:

1. The 1S protection board **latched off**. `P+`/`P−` collapsed to 1.2 V while
   the cell's own terminals still held 3.8 V.
2. The divider sits on the *protected* rail by design (see the module note in
   [`src/battery.rs`](../src/battery.rs)), so it measured that dead rail and
   reported **exactly 0 mV** — tripping the firmware's "no cell at all — check
   the divider is fitted" warning.
3. The board went on running the whole time, because it was on USB.

So the symptom was a firmware message naming the divider, on a node that was
otherwise healthy, with an intact divider. **0 mV does not distinguish "divider
open" from "protected rail dead."** The signature that separates them is
measuring the two rails against each other: **3.8 V at the cell, 1.2 V at
`P+`** can only be the protection board.

Recovery needed no soldering: plugging in USB applies the charger's voltage
across `P+`, which is the ordinary way to unlatch a DW01A-class board. It went
1.2 V → 4.1 V and has behaved since. The protection did its job — it shut off
instead of dying.

**Not done:**

- **Not calibrated.** `offset` is the factory default, so weight publishes as
  roughly -20 kg. Calibration is `tare` on an empty, mounted pan and then
  `scale_factor` against a known mass, both over the Home Assistant knobs, no
  reflash. It waits on the enclosure.

**Answered 2026-09-09 — the runtime config path was broken, and is fixed:**

`deep_sleep = 0` sat retained on the broker for days and never took effect.
The cause was two `subscribe_to_topic` calls in a row in `publish_samples`.
`rust-mqtt` polls for its own SUBACK and discards anything else that arrives —
*"If an application message comes at this moment, it is lost"*, says
`client.rs:145`, and then it returns an error. So the second subscribe swallowed
the retained config the first one had just asked for. Deterministic, whenever
retained config existed.

It now sends one SUBSCRIBE carrying both filters. Verified on hardware:
`config: heartbeat_interval = 660` followed by `config updated and saved to
flash`. That matters here beyond the flag, because **`tare` and `scale_factor`
go through the same code** — the calibration above could not have landed.

**Five things that cost an evening, so that they do not cost another one:**

- **An address that ACKs while every command NAKs means VCC, not the bus.**
  Verified 2026-09-09, and it cost most of a night. The log said these two
  things at once, every cycle, and they read as a contradiction:

  ```
  WARN - no SHT31-D at 0x44 or 0x45
  INFO - I²C scan: 0x44 answered
  ```

  The sensor's **VCC wire was loose**. With the supply open the chip still
  draws a trickle through the ESD diodes on SDA and SCL, which sit on the bus
  pull-ups to 3V3 — enough to run the address comparator and return an ACK,
  nowhere near enough to execute a command or a conversion. The scan writes
  zero bytes (address only) and passes; the probe writes address plus two
  command bytes and fails. The fault lives exactly in that gap.

  Everything that looked strange follows from it: the sensor recovered
  spontaneously at 22:36:53 while the load-cell readings went unsteady — the
  wire making momentary contact as the node was handled — and only this node
  was affected, because it is a wiring fault and not a driver one. Swapping the
  sensor fixed it; the first full reading set in the session arrived at
  23:29:28 (25.5 °C, 43.1 %).

  **So: when a device answers its address but nothing else, check its supply
  before suspecting the bus, the pull-ups or the driver.** A dead bus fails the
  scan too, which is the distinction the scan exists to draw.

  Recorded against a wrong turn, for honesty: this was first blamed on the
  SHT31's soft reset never being issued (`CMD_SOFT_RESET` was defined and
  unused). That change shipped anyway — it is correct and datasheet-conformant
  — but it is **not** what fixed this, and flashing it changed nothing.
- **The tare baseline lives in RTC RAM** and is taken on the first boot after a
  power cycle. The beam has to be left completely alone for that boot. Taring
  while handling it captured a loaded state and left the node 38k ticks off —
  far outside the drift band and far below the threshold, so every poll landed
  in `Decision::Unexplained` and the baseline was, correctly, never absorbed.
  There is no way out of that except another power cycle.
- **A battery node's USB port enumerates only in flashes.** The earlier note
  here said it does not enumerate at all; that was wrong. It appears for a
  fraction of each 2 s poll cycle. Polling `/dev/ttyACM*` every **20 ms** and
  reading it passively catches whole log lines, including the heartbeat window
  where Wi-Fi comes up; polling every 200 ms mostly misses. Verified
  2026-09-06. Flashing still needs the boot window right after plugging in, or
  the BOOT/RESET hold, and `espflash monitor` is still the wrong tool — see
  [`flashing.md`](flashing.md).
- **Never debug this node on USB with the cell disconnected.** Verified
  2026-09-09, after an evening spent on the wrong three theories. The LiPo is
  what buffers the radio's TX bursts; without it the board browns out and
  resets at the first transmission, and the failure is silent in the worst way:
  the serial log ends on `Wi-Fi modem sleep: max`, which `main.rs` prints
  immediately *before* `connect_async().await`. So output stops at the first RF
  current peak, the USB port vanishes, and the board reboots — with **no**
  `Connected to Wi-Fi` and, crucially, **no `connect to … failed (attempt N)`
  either**. Nothing is failing to join; it never gets that far. The SHT31-D
  fails the same way at the same time, logging the contradictory pair
  `no SHT31-D at 0x44 or 0x45` and `I²C scan: 0x44 answered`. Reattach the cell
  and both come back at once: 4.09 V, 24.5 °C, 38.9 %.

  Two hours went into the credentials before that. They were never the problem
  — the boot banner reads `wifi: 'wifi_42_ext' (built in)`, `.env` agrees, the
  network scans at signal 84 on 2.4 GHz, and nothing is stored in flash, so
  `clear` is a no-op. That banner is printed before the console window and is
  almost impossible to catch, since the C3 discards serial output no host is
  reading yet; it took five cold boots to see it once.
- **Discovery used to be announced once per *power cycle*, and that was not
  something power could be relied on to reset.** A boolean in RTC RAM said
  "already announced"; it survived deep sleep, a reflash, a reset — and, as the
  living-room node showed on 2026-09-09, several seconds with the USB cable out.
  Its entities were simply missing while its readings kept arriving. Discovery
  is now gated on a digest of every message it would send
  (`discovery::announcement_tag`), so a changed entity set re-announces itself
  and a stale word in RTC RAM fails to match by construction.

**Reflashed 2026-09-13**, from `develop`, to pick up the one-second minimum on a
visit (`deeafed`) and the I²C failure reporting (`afb34db`). Two things it
settled:

- **The visit counter survived the reflash: `visits` came back at 219.** That is
  the first real test of the `VISIT_COUNT` / `VISIT_CHECK` pair from `36b5e36`,
  against the 2 345 324 652 that leftover RTC memory produced before it existed.
  The pair is only a defence while both words are already on the board; a board
  flashed from *before* `36b5e36` gains `VISIT_CHECK` as fresh garbage, the two
  disagree, and the counter correctly reads zero and restarts. Either outcome is
  fine and neither needs intervention — but they look different in Home
  Assistant, so know which one to expect.
- **A battery node held awake on the bench publishes every `idle_secs`, i.e.
  every two seconds by default.** `sample_period_secs` takes the idle interval
  for a battery profile, and the stay-awake loop publishes every round. Off its
  beam the node also reports nonsense weight (−456.6 g here, with an
  `Unexplained` warning each round, because the RTC baseline is from the
  mounted state). Both go straight into Home Assistant *and* into QuestDB's
  three-year retention, and `smarthome/terrasse/temperature` is the outdoor
  series — so bench-testing this node indoors writes room temperature into it at
  two-second resolution. Set `deep_sleep` back to `1` as soon as the flashing is
  done, not when the node goes back outside.

After remounting on the beam, press **Tarieren** once with the feeder empty: the
RTC baseline is from the previous mounting and no remount reproduces the beam's
preload exactly. The button publishes retained, so a sleeping node collects it
on its next round — up to ten minutes away. Press it once and wait.

**Re-tared on a desk 2026-09-18 at 00:10**, and this is the one to remember:
the boot after that evening's reflash logged `tared baseline = -194505` with the
node lying on a table. The stored calibration came through untouched
(`scale=1862.8`, as it has been since 2026-09-10 — the partition migration left
`nvs` alone, as intended), but the *baseline* is now the desk. **Press Tarieren
once after remounting**, with the feeder empty, or every reading is measured
against a preload that no longer exists.

### 2026-09-17 — flashed with a `wohnzimmer` image, and eleven hours as a second living room

At **10:39:41** this node published its last round under its own name, with
`reset_reason 21` — a USB reset, so a cable was attached at that moment. It did
not then go quiet. It came back as a **second `wohnzimmer`** and stayed one
until 21:49, so `terrasse` shows an eleven-hour hole while the living room's
series carried two boards at once.

**How it was spotted**, because the shape is worth recognising: `reset_count` on
`smarthome/wohnzimmer` read 2, then 1, then 2 on consecutive rounds. A counter
that only a power-on clears cannot go down, so the rounds had to be coming from
two boards. The confirmation was on the same topics — `status offline`
immediately followed by `status online`, about once a minute, which is two
clients sharing one MQTT client id and kicking each other off the broker. The
values alternated with them: 23.7 °C at −52 dBm against 25.2 °C at −47.

**It was a wrong image, not provisioning.** Those are worth telling apart,
because the fix differs: an identity in the flash sector (`smarthome/provision/
<mac>`, see [`flashing.md`](flashing.md#7-provisioning-a-board-without-reflashing))
survives a reflash and the board would have come back wrong a second time.
There was no retained provision message on the broker, and flashing
`NODE=terrasse` fixed it on the first attempt — so the identity was only ever
in the image.

**Recovered 21:49:28**, first round at 21:51:12: `weight 35.4`, `visits 1`,
`reset_count 3`, `battery_voltage 4.09` / `battery_percent 87`.

Two things that survived, and one that did not:

- **The cell is fine.** The board was on USB the whole time, so the eleven hours
  of a mains profile — no deep sleep, ~28 mAh an hour — were paid by the supply
  and not by the pack. Had it been on the mast, that is roughly 300 mAh out of a
  2000 mAh cell.
- **The stored configuration is fine.** `espflash` skipped `0x0` and `0x8000`
  again, so the `nvs` sector kept the calibration through both wrong and right
  flash.
- **The tare baseline is not.** `weight` came back at 35.4 g against a 25 g
  threshold, i.e. the node believes it is being visited while it sits on a
  desk, and the retained value before the fix was −467.2 g. Eleven hours of an
  image with no scale in it will have left the persistent RTC words holding
  something else. **Press Tarieren once after remounting**, as above — this time
  it is not optional.

---
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

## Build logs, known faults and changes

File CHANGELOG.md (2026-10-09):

# Changelog

What changed in this repository, newest first. Format follows
[Keep a Changelog](https://keepachangelog.com/en/1.1.0/); versions follow
[Semantic Versioning](https://semver.org/spec/v2.0.0.html).

**This is not [`docs/annotations.md`](docs/annotations.md), and the two must not
drift into each other.** This file says *what changed in the code*, one entry
per change, written when the change is made. The fleet log says *what happened
to the hardware* — a rollout, an outage, a measurement that corrected an
assumption — written when it happens. A commit that fixes a join retry belongs
here; the evening it went on `kueche` and `bad` belongs there, and the two link
to each other rather than repeating.

**The version here is part of `FW_VERSION`.** A node publishes
`<node>-<release>-<commit>` (`build.rs`), e.g. `kueche-0.2.0-6c81631`: the
release is `version` from `Cargo.toml`, the commit names the exact build and is
what an over-the-air offer must match. Images built before #39 publish
`<node>-<commit>` only.

Entries start at 0.2.0. Earlier history is in `git log` and in the fleet log;
nothing was backfilled, because a changelog written after the fact is a
reconstruction and reads like one.

## [Unreleased]

### Fixed

- **A mistyped `NODE=` now lists `solarleuchte` among the valid names.** The
  build-time error spelled the list out a second time and had missed it; the
  message and `KNOWN_NODES` now share one literal.
- **A restart of the archiver no longer suspends the readings table** (#53).
  The service re-applied `SET TTL` and `DEDUP` on every start. Each is a
  structure change in QuestDB's WAL even when it changes nothing, and since
  the 2026-10-07 power loss the base table cannot apply those, so every
  restart or reboot stopped ingestion until the transaction was skipped by
  hand. It now reads `SHOW CREATE` first and alters only what differs.
- **The dashboard no longer reads rollup views QuestDB has invalidated** (#53).
  The service lists only `valid` views, drops any view whose source view is not
  usable, and re-checks every minute, so a broken view stops being read and a
  rebuilt one is picked up without a restart. The overview's sparklines now fall
  back to the base table when a view has nothing for the window, as the detail
  chart already did: after the 2026-10-07 power loss the overview showed "no
  data" on every tile while each chart behind it drew.

### Added

- **The dashboard has a second view: values per day, week and month** (#52).
  Periods follow the house's calendar (`Europe/Berlin`, weeks from Monday).
  Meters — electricity in kWh, water in m³, anything announced
  `total_increasing` — show their consumption per period as bars, computed from
  the last reading of each period so a camera meter's misread cancels itself
  out; everything else shows its mean, min and max. New endpoint
  `/api/periods`; `ChannelMeta` now carries `state_class` and
  `entity_category` from the discovery messages.
- **A battery node parks on a low cell.** Below 3.0 V (`battery::LOW_CELL_MV`)
  `terrasse` stops polling the scale, reports once and sleeps 3 h between
  checks, each of which publishes. It resumes above 3.3 V, so a cell that
  recovers at rest does not flap. A reading under 2.0 V is treated as a wiring
  fault and never parks. `solarleuchte` already went dark and slept until the
  next dusk below its 20 % charge gate, and is unchanged (#37).

### Changed

- **The firmware moved to esp-hal 1.1** (#32), and the image now carries an
  ESP-IDF app descriptor, so it flashes with **espflash 4.x**; the 3.x pin and
  the second nixpkgs input in `flake.nix` are gone. Chosen as the newest set
  with no beta crate in it: `esp-hal` 1.1.2, `esp-radio` 0.18 (was `esp-wifi`),
  `esp-rtos` 0.3 (was `esp-hal-embassy`), `esp-bootloader-esp-idf` 0.5,
  `embassy-net` 0.9. Rust moves from 1.83 to 1.95. No intended change in what a
  node does; RTC RAM may be re-laid-out, so counters held there (`reset_count`,
  the join counter, the parked flag) can read once as garbage after the update.
  rust-mqtt stays at 0.3 behind a small adapter to embedded-io-async 0.7.
- **`FW_VERSION` now carries the release: `<node>-<release>-<commit>`**, e.g.
  `kueche-0.2.0-6c81631`, with `-dirty` still last. The release is read from
  `Cargo.toml`, so `ota/version`, `meta/board` and the Home Assistant `sw`
  field say which changelog entry a board is on. OTA offers must use the new
  string; the comparison stays exact, and a node on an old-format version takes
  a new-format offer and then recognises it as running (#39).

## [0.2.0] — 2026-10-07

### Fixed

- **A refused Wi-Fi join no longer costs a whole publish round.** The join
  retried on a flat five seconds, which fits twice inside the 20 s
  `WIFI_BUDGET`, so a single refusal ended the round. It now backs off from
  500 ms to a 30 s ceiling, paced by a task-local counter so every round keeps
  its fast first retry. Measured on `kueche`: 47 of 635 rounds lost in 22 hours,
  and 42 of those refusals had cleared by the following round.
- **`reset_count` and the join backoff no longer share a counter.**
  `JOIN_REFUSALS` lives in RTC RAM so it can accumulate towards
  `FALLBACK_AFTER` across a sleeping node's rounds; pacing retries from it had
  every round after the first open already backed off.

### Added

- **A node that cannot reach the broker now sleeps on it.** A publish round that
  never reached the broker doubles the next sleep; the first round that lands
  resets it. The ceiling hangs off `PowerProfile` — one doubling on mains, four
  on a cell — and is bounded by over-the-air reach rather than by power, because
  a node that has backed off cannot be updated for that long. A battery node's
  idle poll is deliberately not stretched: it reads the load cell with the radio
  off, so backing it off would cost presence detection to save nothing.

### Notes

- Neither change addresses the **watchdog resets** (`reset_reason` 7) seen on
  both duty-cycled nodes. An expired `with_timeout` is a clean abort, not a
  stopped executor. That hang is still open.
- Rolled out to `kueche` and `bad` on 2026-10-07; see the fleet log.

[Unreleased]: https://github.com/jrhahn/rs-smarthome-nodes/compare/v0.2.0...develop
[0.2.0]: https://github.com/jrhahn/rs-smarthome-nodes/releases/tag/v0.2.0

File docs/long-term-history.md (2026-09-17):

# Keeping the fleet's data for years

What it costs to keep every reading, what the retention should actually be, and
the three things that threaten a long series once storage stops being the
problem. The service that does the keeping is
[`timeseries/`](../timeseries/README.md); this is the reasoning around it.

## What the fleet produces

Forty-one channels, at the cadences `node.rs` configures — every node also
carries `reset_reason` and `reset_count`, two per node on top of its sensors:

| Node | Channels | Every | Per day |
| --- | --- | --- | --- |
| `schlafzimmer` | temperature, humidity, co2, scd41_temperature, scd41_humidity, rssi, reset ×2 | 60 s | 11,520 |
| `wohnzimmer` | the same six minus co2's siblings, plus voc_index, nox_index, reset ×2 | 60 s | 14,400 |
| `wohnzimmer` | pm25, pm10, pm25_raw, pm10_raw | 900 s | 384 |
| `kueche`, `bad` | temperature, humidity, rssi, reset ×2 | 120 s | 3,600 each |
| `terrasse` | weight, visits, temperature, humidity, battery ×2, rssi, reset ×2 | ~600 s | ~1,300 |

**≈ 34,400 readings a day**, up from ~25,900 before the reset diagnostics.
The two extra channels per node are constant almost all the time, which
compresses to nearly nothing — see the disk figures below, which were measured
on the earlier shape and are not invalidated by a column that repeats.

## What that costs on disk

Measured rather than estimated: three days of exactly that shape were written
into QuestDB 9.3.5 and the finished daily partition read back.

```
2026-09-10    25,872 rows    828 KB    ≈ 32 bytes/row
```

Thirty-two bytes is what the columns come to — an 8-byte timestamp, two 4-byte
symbol references, an 8-byte double — plus the symbol index. So:

| | Raw | With the rollups (estimated) |
| --- | --- | --- |
| 1 year | 0.3 GB | ~0.8 GB |
| 3 years | 0.9 GB | ~2.4 GB |
| 10 years | 3 GB | ~8 GB |

The rollup figure is arithmetic, not measurement: `_1m` holds about as many rows
as the base table with four more columns per row, and `_1h` (≈740 rows/day) and
`_1d` (31 rows/day) are noise beside either.

> **Do not read the size off the active partition.** QuestDB pre-allocates
> append space, so `table_storage()` reported 81 MB for the day being written
> while the finished neighbour beside it was 828 KB. The number only settles
> when the partition closes.

## What follows: three years is too short

`retention = "3y"` was chosen before any of this was measured. At 0.3 GB a year
it is not a storage decision, and the rollups exist for *speed*, not for space —
a full-range chart reads `_1d` either way.

**The shape is raw for a few years, rollups for decades.** A year-on-year
comparison in 2032 reads 31 rows a day; there is no reason for that to expire
with the readings it summarises. The service now keeps two retentions —
`retention` for the raw table and the minute view, `rollup_retention` for the
hour and day views.

Not *unlimited*, though, and the reason is worth knowing before someone tries to
"fix" it: QuestDB accepts `ALTER MATERIALIZED VIEW ... SET TTL` but rejects a
TTL of zero ("must be an integer multiple of partition size"), and `ALTER TABLE
... SET TTL` is refused on a view outright. A view created without a TTL keeps
none, but one created *with* one can only ever be changed, never cleared. Fifty
years is therefore the honest way to say "not in this house's lifetime" while
leaving the number adjustable.

## What actually threatens a long series

### Gaps, when the archiver is not running

The nodes publish at **QoS 0** (`main.rs`). A QoS 0 message is never queued for
an absent subscriber — not with a persistent session, not with a QoS 1
subscription, because delivery happens at the lower of the two. Every restart of
the archiver, every deploy, every crash is therefore a hole in the series.

Publishing at QoS 1 would close it and cost a battery node an extra round trip
per reading — the wrong trade for the node that is hardest to keep alive. What
was done instead closes the part of the hole that actually hurts, for free.

**Readings are retained, and they carry their own timestamp.** The broker keeps
the last value of every topic, so on reconnect the archiver is handed the most
recent reading of every channel at once. That used to be worthless: the only
clock available on receipt is "now", so a replayed value would have landed at
the head of the series carrying the wrong time, and the archiver dropped every
retained reading for exactly that reason. A reading that can date itself can be
replayed, so the nodes now ask the home server for the time once per publish
round (`src/ntp.rs`) and stamp each reading with when its sensor produced it
(`src/clock.rs`, walking back by the sample's own age — on a node duty-cycling
an SDS011 fan the gap between measuring and publishing is tens of seconds).

Two things make that safe rather than merely appealing:

- The readings table deduplicates on `(timestamp, node, sensor)`, so ingesting
  the same retained value again — which happens on every reconnect — is a no-op
  rather than a second row skewing the `_1m` average.
- A timestamp is a claim, and it is checked on both sides against the same
  window (2025–2100). A node whose clock is confused loses its precision, not
  its readings: it publishes unstamped, and is dated on arrival as before.

What this does **not** do is recover the whole gap. Retain holds one message per
topic, not a queue, so an outage of ten minutes at a one-minute cadence gives
back the last reading and not the other nine. For a deploy — seconds — that is
effectively the whole hole; for an afternoon it is the head of each series and
nothing more. The ordinary mitigations still apply: run the archiver on the same
host as the broker, keep restarts short, and remember that Home Assistant's
recorder is a second subscriber holding the last ~10 days independently.

A hole is at least visible: the chart simply has no points there.

### Backups that are not backups

`/var/lib/questdb` is the directory that matters, and copying it while the
database is running is a coin flip — the WAL may be mid-apply. QuestDB's answer
is a checkpoint: `CHECKPOINT CREATE`, let the backup run over the directory,
`CHECKPOINT RELEASE`. (`SNAPSHOT PREPARE` / `SNAPSHOT COMPLETE` is the older
spelling of the same pair; 9.3.5 accepts both.) Without it, a restore is
untested by construction.

The release is the half that is easy to get wrong. It has to run even when the
backup fails, because a checkpoint left held makes QuestDB keep every WAL
segment from that moment on — which shows up days later as a disk filling up,
with nothing pointing back at the night the backup broke. In `home-server` it is
therefore an `ExecStopPost` on the borg unit rather than the job's own
`postHook`, which does not run on failure.

### A series nobody can interpret in three years

The data will outlive the memory of what happened to the hardware. The step in
the terrace's weight on 2026-09-09 was a recalibration. The CO₂ offset changed
when an SCD41 was replaced. The living room's VOC index starts at 1 and climbs
for a day because the algorithm is learning the room, not because the air is
improving.

None of that is in the numbers. A small `annotations` table — timestamp, node,
one sentence — or even a dated list in this repo is what turns a pile of
readings into a measurement series. It is the cheapest thing here and the one
most likely to be skipped; [`annotations.md`](annotations.md) is where it is
being kept until the table exists.

## The order of work

1. **Deploy the archiver.** It is built and verified against a real QuestDB, and
   runs nowhere. The NixOS module is in `timeseries/nix/module.nix`; the home
   server needs the flake input, the module import, an MQTT password as a
   secret, and a proxy entry. Everything below is hypothetical until this is
   done.
2. ~~**Retention per tier**~~ — done: the raw table and the `_1m` view follow
   `retention` (3 years), the `_1h` and `_1d` views follow `rollup_retention`,
   which defaults to fifty. *Long* rather than unlimited because QuestDB will
   change a view's TTL but not clear it, so the alternative was a view that
   could never be re-tuned.
3. ~~**Snapshot-aware backup**~~ — done, in `home-server`: the data directory is
   in the family borg paths, the job brackets itself with `CHECKPOINT CREATE` /
   `CHECKPOINT RELEASE`, and the release hangs off `ExecStopPost` so a failed
   backup cannot leave a checkpoint held.
4. **Annotations** — started, by hand, in [`annotations.md`](annotations.md). A
   table in the database is still the better home for them, so a chart can show
   them; a dated list costs nothing and is already worth more than the memory it
   replaces.
5. Optionally, once the archive has been running a while: trim Home Assistant's
   recorder to ~10 days. Its job becomes the live view; the history lives here.

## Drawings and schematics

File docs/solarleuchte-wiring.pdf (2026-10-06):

# Solarleuchte — Verdrahtung

## Panel

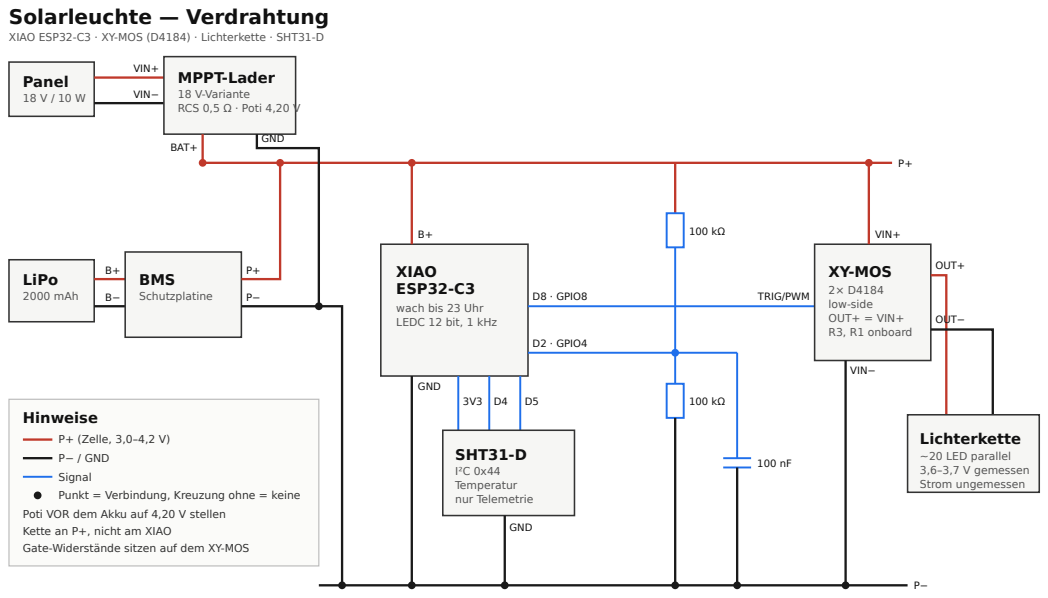
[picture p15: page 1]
VIN+; VIN−; MPPT-Lader; 18 V-Variante RCS 0,5 Ω · Poti 4,20 V; BAT+; GND; LiPo; 2000 mAh; BMS; Schutzplatine; D8 · GPIO8; TRIG/PWM; D2 · GPIO4; XY-MOS; 2× D4184 low-side OUT+ = VIN+ R3, R1 onboard; OUT+; OUT−; Lichterkette; ~20 LED parallel 3,6–3,7 V gemessen Strom ungemessen; SHT31-D; I²C 0x44 Temperatur nur Telemetrie; Hinweise

XIAO ESP32-C3 · XY-MOS (D4184) · Lichterkette · SHT31-D

XIAO
ESP32-C3
wach bis 23 Uhr
LEDC 12 bit, 1 kHz

P+ (Zelle, 3,0–4,2 V)
P− / GND
Signal
Punkt = Verbindung, Kreuzung ohne = keine
Poti VOR dem Akku auf 4,20 V stellen
Kette an P+, nicht am XIAO
Gate-Widerstände sitzen auf dem XY-MOS

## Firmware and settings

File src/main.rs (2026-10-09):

//! rs-smarthome-nodes — async firmware for a fleet of ESP32-C3 sensor nodes.
//!
//! One image serves every node: which sensors are populated, what the node is
//! called and how it is powered come from [`node`], picked by `NODE=<name>` at
//! build time or by a provisioned identity in flash. It started life as a
//! battery bird-feeder scale, and that node — now `terrasse`, the default —
//! still drives the flow described below.
//!
//! **Battery profile** — to catch short bird visits without keeping the radio
//! awake, the firmware polls by cold-booting out of deep sleep on a short
//! interval and only spends Wi-Fi energy when weight is actually on the scale:
//!   1. Bring up the HAL + Embassy executor (TIMG0).
//!   2. Read a raw weight sample from the HX711 (with a timeout, so a missing
//!      sensor can't wedge the boot).
//!   3. Compare against the tare baseline persisted in RTC RAM across sleep:
//!        - empty house  -> drift-correct the baseline, skip Wi-Fi, deep-sleep
//!          a short *idle* interval to catch the next visit;
//!        - weight present -> join Wi-Fi (STA + DHCP), publish every populated
//!          sensor over MQTT, deep-sleep a longer *active* interval to keep
//!          tracking. A final reading is published on the falling edge when the
//!          bird leaves.
//!
//! **Mains profile** — indoor air-quality nodes stay associated and sample on a
//! fixed cadence instead, because CO₂ continuity and the SDS011's duty-cycled
//! fan both rule out deep sleep.
//!
//! Home Assistant discovers every node's entities over retained MQTT config
//! messages (see [`discovery`]); calibration and tuning live in flash and are
//! updated live from Home Assistant (see [`config`]).

#![no_std]
#![no_main]

use core::time::Duration as CoreDuration;

extern crate alloc;

use embassy_executor::Spawner;
use embassy_net::{
    tcp::TcpSocket, Config as NetConfig, Ipv4Address, Runner, Stack, StackResources,
};
use embassy_sync::{blocking_mutex::raw::CriticalSectionRawMutex, signal::Signal};
use embassy_time::{with_timeout, Duration, Instant, Timer};
use embedded_hal::delay::DelayNs as _;
use esp_backtrace as _;
use esp_hal::{
    clock::CpuClock,
    delay::Delay,
    efuse,
    gpio::{DriveMode, Flex, Input, InputConfig, Level, Output, OutputConfig, Pull},
    interrupt::software::SoftwareInterruptControl,
    peripherals::{GPIO2, LPWR, TIMG0, WIFI},
    rng::Rng,
    rtc_cntl::{sleep::TimerWakeupSource, Rtc},
    system::software_reset,
    time::Duration as HalDuration,
    timer::timg::{MwdtStage, TimerGroup, Wdt},
    usb_serial_jtag::UsbSerialJtag,
};
use esp_radio::wifi::{
    sta::StationConfig, Config as WifiConfig, ControllerConfig, Interface, PowerSaveMode,
    WifiController,
};
use log::{info, warn};
use rust_mqtt::{
    client::{client::MqttClient, client_config::ClientConfig},
    packet::v5::publish_packet::QualityOfService,
    utils::rng_generator::CountingRng,
};

use node::{NodeConfig, Provision};
use rs_smarthome_nodes::{
    battery, clock, config, discovery, ds18b20, http, hx711, lamp, node, ntp, ota, platform,
    presence, reset_reason, rssi, sensors::scale, solar, state, wifi, FW_VERSION,
};

use battery::Battery;
use config::Config;
use ds18b20::Ds18b20;
use hx711::Hx711;
use platform::{Samples, Sensors};

// The ESP-IDF application descriptor: what espflash 4 checks for, and the
// reason the HAL had to move past 0.22 (#32).
esp_bootloader_esp_idf::esp_app_desc!();

/// A handle on the network stack. `Copy` since embassy-net 0.6, so it is passed
/// by value rather than as a `&'static`.
type WifiStack = Stack<'static>;

/// rust-mqtt 0.3 and `http` speak embedded-io-async **0.6**; embassy-net 0.9's
/// socket speaks 0.7. Rather than move the MQTT client to a newer major -- whose
/// API is a rewrite, against a broker this one is known to work with -- the
/// socket is adapted here, through its own inherent methods.
struct Io06<'a, 'b>(&'a mut TcpSocket<'b>);

impl embedded_io_async::ErrorType for Io06<'_, '_> {
    type Error = embedded_io_async::ErrorKind;
}

impl embedded_io_async::Read for Io06<'_, '_> {
    async fn read(&mut self, buf: &mut [u8]) -> Result<usize, Self::Error> {
        self.0
            .read(buf)
            .await
            .map_err(|_| embedded_io_async::ErrorKind::ConnectionReset)
    }
}

impl embedded_io_async::Write for Io06<'_, '_> {
    async fn write(&mut self, buf: &[u8]) -> Result<usize, Self::Error> {
        self.0
            .write(buf)
            .await
            .map_err(|_| embedded_io_async::ErrorKind::ConnectionReset)
    }

    async fn flush(&mut self) -> Result<(), Self::Error> {
        self.0
            .flush()
            .await
            .map_err(|_| embedded_io_async::ErrorKind::ConnectionReset)
    }
}

/// Staging buffer for a firmware download, one flash sector wide.
///
/// Static rather than stacked: 4 KB is a lot to ask of a task stack, and rather
/// than a heap allocation that could fail halfway through an update with the
/// radio up. See [`ota::Writer::new`] for why the size is a whole sector.
fn ota_staging() -> &'static mut [u8; ota::SECTOR as usize] {
    static mut STAGING: [u8; ota::SECTOR as usize] = [0; ota::SECTOR as usize];
    // SAFETY: one consumer, never re-entered. `run_update` is the only caller,
    // it runs on the single executor thread, and it is awaited to completion
    // inside one publish round -- the next round cannot begin until it has
    // returned.
    unsafe { &mut *core::ptr::addr_of_mut!(STAGING) }
}

// --- Compile-time configuration --------------------------------------------
// Override the credentials at build time, e.g.:
//   SSID=MyNet PASSWORD=hunter2 cargo run --release
// The MQTT broker address is edited here directly.
const SSID: &str = match option_env!("SSID") {
    Some(s) => s,
    None => wifi::PLACEHOLDER_SSID,
};
const PASSWORD: &str = match option_env!("PASSWORD") {
    Some(s) => s,
    None => "your-password",
};

/// Optional MQTT broker credentials, baked in at build time (see .env).
/// When unset the client connects anonymously, so an auth-free broker still
/// works out of the box.
const MQTT_USER: Option<&str> = option_env!("MQTT_USER");
const MQTT_PASSWORD: Option<&str> = option_env!("MQTT_PASSWORD");

/// Home Assistant / Mosquitto broker on the LAN. Baked in at compile time from
/// the `MQTT_BROKER` env var (see `.env` / `.env.example`), like the Wi-Fi
/// credentials. It is a private LAN IP, not a secret, but keeping it out of
/// source is cleaner; the default keeps a plain `cargo build` working.
const MQTT_BROKER: Ipv4Address = parse_ipv4(match option_env!("MQTT_BROKER") {
    Some(s) => s,
    None => "192.168.1.67",
});
const MQTT_PORT: u16 = 1883;

/// Where to ask for the time, baked in like the broker.
///
/// Defaults to the broker's own address: the machine running mosquitto is the
/// home server, which is also the one thing on this LAN that is always up and
/// already knows what time it is. Pointing at a public pool instead would make
/// every reading's timestamp depend on the house having a working uplink, and
/// add a DNS lookup to a path that currently needs none.
const NTP_SERVER: Ipv4Address = parse_ipv4(match option_env!("NTP_SERVER") {
    Some(s) => s,
    None => match option_env!("MQTT_BROKER") {
        Some(s) => s,
        None => "192.168.1.67",
    },
});

/// Const-parse a dotted-decimal IPv4 string (e.g. `"192.168.1.67"`) into an
/// [`Ipv4Address`] at compile time, so `MQTT_BROKER` can come from an env var.
const fn parse_ipv4(s: &str) -> Ipv4Address {
    let o = parse_octets(s);
    Ipv4Address::new(o[0], o[1], o[2], o[3])
}

/// The dotted-decimal → four-octet core, split out so it can be checked at
/// compile time. Lenient by design: extra separators are clamped rather than
/// panicking, so a malformed override yields a wrong (but harmless) address,
/// never a build that fails deep inside const-eval.
const fn parse_octets(s: &str) -> [u8; 4] {
    let b = s.as_bytes();
    let mut octets = [0u8; 4];
    let mut idx = 0;
    let mut cur = 0u16;
    let mut i = 0;
    while i < b.len() {
        let c = b[i];
        if c == b'.' {
            if idx < 3 {
                octets[idx] = cur as u8;
                idx += 1;
            }
            cur = 0;
        } else {
            cur = cur * 10 + (c - b'0') as u16;
        }
        i += 1;
    }
    if idx < 4 {
        octets[idx] = cur as u8;
    }
    octets
}

// Pin the parser against the default broker address at compile time.
const _: () = {
    let o = parse_octets("192.168.1.67");
    assert!(o[0] == 192 && o[1] == 168 && o[2] == 1 && o[3] == 67);
};

// --- Sampling / detection tuning -------------------------------------------
// Topics, the client id and the sensor set come from [`node::active`]; the
// presence threshold and the idle/active poll intervals live in
// [`config::Config`], persisted in flash and tunable live from Home Assistant.

/// How long to wait for the next retained config message after subscribing.
/// Retained values arrive within tens of ms, so once a receive hits this
/// timeout we assume the broker has sent them all and stop draining.
const CONFIG_RECV_WINDOW: Duration = Duration::from_millis(400);

/// How long a cold boot waits for someone at the serial console before carrying
/// on. Short, because it delays every power-up of every node; long enough to
/// paste three lines into a terminal that is already open.
const CONSOLE_WINDOW: Duration = Duration::from_secs(3);

/// The same wait for a board that has no usable credentials at all. It has
/// nothing else it could be doing, so it is worth waiting properly — and after
/// this it boots on and simply fails to join, which is no worse.
const CONSOLE_WINDOW_STRANDED: Duration = Duration::from_secs(120);

/// Config key carrying a tare request. Called out because, unlike every other
/// key, acting on it means deleting the retained message afterwards.
const TARE_KEY: &str = "tare";
/// Config key that forgets the discovery digest; see `REANNOUNCE_CONTROLS`.
const REANNOUNCE_KEY: &str = "reannounce";
/// Config key that zeroes the visit counter. Like the two above it is a button
/// press rather than a setting, so it is consumed rather than stored -- and
/// unlike them it touches RTC RAM instead of the config blob.
const RESET_VISITS_KEY: &str = "reset_visits";

/// How long a wake-up costs on top of the interval it slept, in milliseconds.
///
/// Boot, four HX711 conversions and the sensor reads. Measured from the
/// heartbeat spacing on 2026-09-26: 720 s across 120 idle wakes at a 5 s
/// interval, so 6.0 s a cycle and 1.0 s of it awake. Only the coarse clock uses
/// this, and only to bridge the minutes between two NTP syncs.
const AWAKE_ESTIMATE_MS: u64 = 1000;

/// Give up on a single HX711 conversion after this long. A disconnected sensor
/// (with `DT` pulled up) never becomes ready, so this bounds the boot.
const HX711_TIMEOUT: Duration = Duration::from_millis(500);

/// Upper bound on the whole Wi-Fi join + MQTT publish. Without it a failed join
/// would spin in the high-power state and drain the battery. Sensor sampling
/// happens before this window, so a slow sensor never eats into it.
const WIFI_BUDGET: Duration = Duration::from_secs(20);

/// How long the executor may stop running before the board is restarted.
///
/// Fed by [`feed_watchdog`] while anything is still being polled, so what this
/// actually measures is "the executor has stopped making progress" -- a
/// deadlock, a blocking loop, a driver that never returns. A panic does not go
/// through here at all; it has [`custom_halt`].
const WATCHDOG_SECS: u64 = 60;

/// How often the watchdog is fed. Well inside [`WATCHDOG_SECS`], so a single
/// missed turn is not a reboot: what should trigger it is the executor stopping
/// altogether, not one task running long.
const WATCHDOG_FEED_SECS: u64 = 5;

/// How long to wait for the MQTT DISCONNECT and the TCP FIN to actually leave
/// the board at the end of a round. Short on purpose: the readings are already
/// out by then, so this only buys a tidy shutdown, and it is spent inside
/// [`WIFI_BUDGET`].
const SHUTDOWN_BUDGET: Duration = Duration::from_secs(2);

/// Cadence of the gas sensor's sampling step.
///
/// Sensirion's index algorithm is specified for a 0.5-10 s interval and
/// configured here for exactly one second (`sgp41::SAMPLING_INTERVAL_SECS`), so
/// this is not a tuning knob: changing it without changing that constant makes
/// the index wrong rather than coarse. The step itself takes ~50 ms, so the
/// wait is what sets the pace.
const GAS_STEP_INTERVAL: Duration = Duration::from_secs(1);

/// Hard cap on how long one visit keeps the node awake.
///
/// A bird is expected to leave well inside this. The cap exists for a load that
/// does not — snow, a twig, a squirrel that settles in — so a stuck cell can
/// never hold the CPU awake and flatten the cell.
const VISIT_MAX: Duration = Duration::from_secs(60);

/// Consecutive below-threshold samples that end a visit. More than one so a
/// bird shifting its weight for an instant does not read as a departure.
const VISIT_DEPART_SAMPLES: u8 = 3;

/// Samples taken right after the load first crosses the threshold are dropped:
/// the bird is still landing and the cell is still ringing, so they would drag
/// the median toward a weight nothing ever had.
const VISIT_SETTLE: Duration = Duration::from_millis(400);

/// Convenience: allocate a `T` with `'static` lifetime from a `StaticCell`.
macro_rules! mk_static {
    ($t:ty, $val:expr) => {{
        static STATIC_CELL: static_cell::StaticCell<$t> = static_cell::StaticCell::new();
        STATIC_CELL.init($val)
    }};
}

/// The load-cell driver as this board wires it: esp-hal pins and delay. The
/// driver itself names none of those types (see [`hx711`]).
type Scale<'d> = Hx711<Input<'d>, Output<'d>, Delay>;
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
async fn main(spawner: Spawner) -> ! {
    // --- 1. HAL & async runtime --------------------------------------------
    let hal_config = {
        let mut c = esp_hal::Config::default();
        // 80 MHz rather than the 160 this chip will do. That is exactly the
        // minimum esp-wifi documents for the radio (`MIN_CLOCK` in its `init`,
        // which rejects anything below it), and dynamic power scales with the
        // clock — so this roughly halves what the core burns while idling in
        // the executor.
        //
        // It is a thermal fix, not a power one. A mains node never sleeps, so
        // whatever the core burns ends up as heat in the enclosure and the
        // sensors read their own board rather than the room: measured against
        // a reference thermometer on `schlafzimmer`, 2026-09-03, the air at the
        // electronics sat ~1 °C above the room.
        //
        // Nothing here needs the speed. A round is a handful of I²C
        // transactions and one MQTT publish, and the I²C and UART baud rates
        // derive from APB, not from the CPU clock, so their timing is
        // unchanged. On a battery node the trade is roughly neutral rather than
        // a win — half the clock means twice as long awake for the same work —
        // but the radio-idle stretches, which dominate a wake, still cost less.
        c = c.with_cpu_clock(CpuClock::_80MHz);

        // Arm a watchdog. Every one of them is off by default -- esp-hal's
        // `WatchdogConfig` derives `Default` and `WatchdogStatus::Disabled` is
        // it -- and this firmware had been running that way, which is why a
        // hang that was not a panic could only be ended by a person.
        //
        // **TIMG0 and not the RWDT**, and the difference is the whole design.
        // The RWDT lives in the RTC domain, which stays powered through deep
        // sleep, so arming it would reboot a sleeping node mid-sleep -- on a
        // duty-cycled board that is most of its life. The TIMG watchdogs are in
        // the digital domain, which deep sleep switches off, so this covers
        // exactly the awake window and nothing else.
        //
        // Sixty seconds against a `WIFI_BUDGET` of twenty plus sampling and
        // boot: generous enough that nothing legitimate reaches it, short
        // enough that a hang costs a minute rather than a day. The longest
        // legitimate stretch is an over-the-air write, measured at seventeen
        // seconds end to end on 2026-09-17.
        // (Armed below, on the driver: esp-hal 1.x dropped the field from
        // `Config`, and `init` now disables every watchdog on its way through.)
        c
    };
    let peripherals = esp_hal::init(hal_config);

    esp_println::logger::init_logger_from_env();
    esp_alloc::heap_allocator!(size: 72 * 1024);

    // TIMG0's timer drives esp-rtos, which both the executor and the radio run
    // on; its watchdog is the one armed here.
    let timg0 = TimerGroup::new(peripherals.TIMG0);
    let mut watchdog = timg0.wdt;
    watchdog.set_timeout(MwdtStage::Stage0, HalDuration::from_secs(WATCHDOG_SECS));
    watchdog.enable();
    let sw_int = SoftwareInterruptControl::new(peripherals.SW_INTERRUPT);
    esp_rtos::start(timg0.timer0, sw_int.software_interrupt0);

    // Spawned before anything else can block, because everything below this
    // line is inside the watchdog's window -- including the console wait, which
    // is two minutes on a board that cannot join.
    spawner.spawn(feed_watchdog(watchdog).expect("watchdog task spawns once"));

    // Who am I? A provisioned identity in flash wins over the one this image was
    // built with. Must happen before any peripheral is touched: the sensor set
    // decides which buses come up at all.
    node::init();
    node::set_mac(mac_address());
    let node = node::active();

    info!(
        "node '{}' ({}) booted, {} profile",
        node.id,
        node.name,
        node.power.label()
    );
    // Say where to reach this board if it needs to be told what it is; the MAC
    // is the only name it is sure of before provisioning.
    info!("provision topic: {}", node::provision_topic(node::mac()));
    info!("firmware: {} on board {}", FW_VERSION, node::mac_string());

    // Which network? Credentials stored over the serial console win over the
    // ones compiled in. Resolved before the radio comes up, and before the
    // console window below, so provisioning can report what it is replacing.
    // Before anything can overwrite it: why this boot happened. A deep-sleep
    // wake is the steady state and is dropped; anything else is latched in RTC
    // RAM so the next publish can carry it. See `reset_reason` for why this is
    // worth the two numbers.
    // A panic restarts the board through `custom_halt`, and the hardware calls
    // that a software reset -- the same thing an over-the-air update is. The
    // flag survives the reset in RTC RAM and is what tells them apart.
    let boot_code = if state::panicked() {
        state::set_panicked(false);
        reset_reason::PANIC
    } else {
        reset_reason::code()
    };
    state::note_reset(boot_code);
    // And once more where power cannot erase it. RTC RAM answers "what kind of
    // reset", flash answers "did it restart at all" -- and only the second
    // survives the outage that makes the question worth asking.
    reset_reason::note_boot(boot_code);
    if state::last_reset() != 0 {
        warn!(
            "last non-routine reset: code 0x{:02X}, {} since power-on",
            state::last_reset(),
            state::reset_count()
        );
    }

    let source = wifi::init(built_in_credentials());
    match wifi::active() {
        Some(credentials) => info!(
            "wifi: '{}' ({})",
            credentials.ssid,
            match source {
                wifi::Source::Stored => "from flash",
                wifi::Source::BuiltIn => "built in",
            }
        ),
        None => warn!("wifi: no credentials"),
    }

    // The escape hatch. Only on a cold boot: a deep-sleep wake skips it, so a
    // battery node pays this once per power-up rather than every two seconds.
    if state::is_cold_boot() {
        console_provisioning(peripherals.USB_DEVICE).await;
    }
    // A `persistent` RTC word is not initialised by the startup code, so a
    // counter that has just been added to the firmware starts at whatever was
    // in that slot. This one fired its stuck-load bound on the first boot after
    // the reflash that introduced it -- harmless, since an arrival resets it,
    // but a legitimate first visit would have been misjudged once. Zero it
    // where a cold boot is already being detected.
    if state::is_cold_boot() {
        state::set_present_rounds(0);
        // Belt and braces only: the visit counter guards itself with a checked
        // pair, because this branch cannot cover the case that actually bit --
        // a reflash keeps RTC RAM, so the first boot carrying a *new* counter
        // is not a cold boot. See `scale::VISITS_MAGIC`.
        state::set_visit_count(0);
    }
    state::mark_booted();

    // Runtime config from flash (calibration + tuning), or defaults on a blank
    // sector. Read now, while the radio is still down. It may be updated from
    // Home Assistant during the publish below and persisted before sleep.
    let cfg = config::load();
    info!(
        "config: offset={} scale={} threshold={}g idle={}s active={}s",
        cfg.offset, cfg.scale_factor, cfg.threshold_grams, cfg.idle_secs, cfg.active_secs
    );
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

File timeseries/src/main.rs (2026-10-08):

//! `smarthome-timeseries` -- the long-term memory of the sensor fleet.
//!
//! Home Assistant already sees every node over MQTT auto-discovery, and it
//! keeps a recorder database of its own. What it does not do is keep three
//! years of it: its recorder is tuned for weeks, and the long-run questions
//! this fleet was built to answer -- did insulating the roof change the
//! bedroom's overnight CO2, how does the terrace's temperature swing compare
//! between summers -- need the history to still be there.
//!
//! So this sits beside Home Assistant rather than inside it: one process that
//!
//!   1. follows the same MQTT topics the nodes already publish,
//!   2. writes every reading into QuestDB, which keeps three years of them and
//!      pre-aggregates the history into rollup views, and
//!   3. serves a small dashboard that reads those rollups.
//!
//! Nothing here touches the firmware or Home Assistant's configuration. A node
//! does not know it is being archived, and switching this service off leaves
//! the house working exactly as before.

mod config;
mod model;
mod mqtt;
mod questdb;
mod state;
mod web;

use std::path::PathBuf;
use std::sync::Arc;
use std::time::Duration;

use anyhow::{Context, Result};
use tokio::sync::mpsc;
use tracing::{error, info, warn};
use tracing_subscriber::EnvFilter;

use config::Settings;
use questdb::{schema, Client, Record};
use state::Shared;

/// How long to keep waiting for a database that is not up yet.
///
/// On the home server this process and QuestDB come up together, and systemd's
/// ordering only guarantees that the unit *started*, not that it is answering
/// queries -- QuestDB takes a few seconds to open its tables. Retrying beats
/// failing and being restarted, because a restart loop loses the MQTT
/// subscription too.
const DB_WAIT: Duration = Duration::from_secs(180);

#[tokio::main]
async fn main() -> Result<()> {
    tracing_subscriber::fmt()
        .with_env_filter(
            EnvFilter::try_from_env("SMARTHOME_TIMESERIES_LOG")
                .unwrap_or_else(|_| EnvFilter::new("info")),
        )
        .init();

    let path = settings_path();
    let settings = Settings::load(path.as_deref())?;
    match &path {
        Some(p) => info!(config = %p.display(), "settings loaded"),
        None => info!("no settings file given; using defaults"),
    }

    let client = Client::new(
        settings.questdb_base(),
        &settings.questdb.user,
        &settings.questdb.password,
    )?;
    wait_for_database(&client, settings.questdb_base()).await?;

    let views = schema::ensure(
        &client,
        &settings.questdb.table,
        &settings.questdb.status_table,
        &settings.questdb.annotations_table,
        &settings.retention(),
        &settings.rollup_retention(),
        settings.questdb.rollups,
    )
    .await
    .context("preparing the QuestDB schema")?;

    let shared = Shared::new();
    shared.set_views(views);

    // A view can go invalid while this runs -- QuestDB does that to a view whose
    // base table moves backwards, as after an unclean power loss -- and come back
    // after a rebuild. Asked again every minute, so reads stop using a broken
    // view without a restart, and pick a repaired one up the same way.
    {
        let (client, shared, table) = (
            client.clone(),
            shared.clone(),
            settings.questdb.table.clone(),
        );
        tokio::spawn(async move {
            let mut tick = tokio::time::interval(Duration::from_secs(60));
            loop {
                tick.tick().await;
                match schema::list_views(&client).await {
                    Ok(valid) => {
                        let usable = schema::usable_views(&table, &valid);
                        if usable != shared.views() {
                            warn!(views = ?usable, "usable rollup views changed");
                        }
                        shared.set_views(usable);
                    }
                    Err(e) => warn!(error = %e, "could not re-check the rollup views"),
                }
            }
        });
    }

    // What the database already knows about who is online, so the retained
    // last-wills that arrive on connect are recognised as old news.
    match questdb::series::fetch_status(&client, &settings.questdb.status_table).await {
        Ok(rows) => {
            for (node, online) in &rows {
                shared.seed_online(node, *online);
            }
            info!(nodes = rows.len(), "seeded availability from the database");
        }
        Err(e) => warn!(error = %e, "could not read the last known availability"),
    }

    // Bounded: if QuestDB stops answering, back-pressure should reach the MQTT
    // loop rather than growing a queue until the machine swaps. Readings the
    // bridge cannot take are lost, which on a live feed is the right trade --
    // the alternative is losing all of them to an out-of-memory kill.
    let (tx, rx) = mpsc::channel::<Record>(4_096);

    let writer = tokio::spawn(questdb::writer::run(
        client.clone(),
        settings.questdb.table.clone(),
        settings.questdb.status_table.clone(),
        Duration::from_secs(settings.questdb.flush_interval_secs),
        settings.questdb.batch_max,
        shared.stats(),
        rx,
    ));

    let bridge = tokio::spawn(mqtt::run(settings.clone(), shared.clone(), tx));

    let app = web::App {
        settings: Arc::new(settings.clone()),
        client,
        shared,
    };
    let listener = tokio::net::TcpListener::bind(settings.web.bind)
        .await
        .with_context(|| format!("binding {}", settings.web.bind))?;
    info!(address = %settings.web.bind, "dashboard listening");

    axum::serve(listener, web::router(app))
        .with_graceful_shutdown(shutdown_signal())
        .await
        .context("serving the dashboard")?;

    // The bridge has no shutdown of its own -- it is a reconnect loop with no
    // state worth saving. The writer does: dropping the sender closes the
    // channel, which makes it flush what is buffered and return.
    bridge.abort();
    info!("flushing the last batch");
    match tokio::time::timeout(Duration::from_secs(30), writer).await {
        Ok(Ok(())) => info!("writer stopped cleanly"),
        Ok(Err(e)) => error!(error = %e, "writer task failed"),
        Err(_) => warn!("writer did not finish within 30 s; exiting anyway"),
    }
    Ok(())
}

/// The settings file: first argument, or `$SMARTHOME_TIMESERIES_CONFIG`, or
/// nothing at all (every default works against a localhost broker and
/// database).
fn settings_path() -> Option<PathBuf> {
    std::env::args()
        .nth(1)
        .or_else(|| std::env::var("SMARTHOME_TIMESERIES_CONFIG").ok())
        .map(PathBuf::from)
}
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

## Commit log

2026-07-02 Implement async ESP32-C3 bird scale firmware (closes #1)
    no_std Embassy firmware for the Seeed XIAO ESP32-C3:
    - esp-hal 0.22 + esp-hal-embassy, executor driven by TIMG0
    - Async HX711 load-cell driver (src/hx711.rs): async wait_ready() via
    embassy-time, blocking 24+N clock read, 24-bit two's-complement
    sign-extension to i32 (const-asserted)
    - esp-wifi STA + embassy-net DHCP with background net_task
    - rust-mqtt (embedded-async, MQTT v5) publishing the raw i32 to
    birds/scale/state
    - RTC-timer deep sleep, 5-minute interval
    Toolchain pinned to Rust 1.83.0: Rust >= 1.84 makes c_char unsigned on
    RISC-V, which is incompatible with esp-wifi 0.11's generated bindings.
    Docs: README.md, FLASHIN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
    [main.rs]
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2026-07-07 feat: optional MQTT broker authentication
    Add MQTT_USER / MQTT_PASSWORD, baked in at build time via option_env!
    and fed from .env like the Wi-Fi credentials. When unset the client
    connects anonymously, so an auth-free broker keeps working; when set,
    the client authenticates (needed for the Mosquitto broker's per-device
    user). build.rs gains rerun-if-env-changed hooks for both.
    [main.rs]
2026-07-07 chore: point MQTT_BROKER at the LAN broker (192.168.1.67)
    family-server's eno1 LAN address, reachable from the ESP32 over Wi-Fi.
    [main.rs]
2026-07-10 feat: event-driven weight-triggered sampling to catch bird visits
    Replace the blind 5-minute poll with an event-driven deep-sleep loop that
    only spends Wi-Fi energy when weight is actually on the scale, so short
    bird visits are caught without draining the battery.
    - hx711: add read/wait_ready timeout (returns Option) so a disconnected or
    stuck sensor can't wedge the boot; add power_up/power_down groundwork.
    - state: new module keeping the tare baseline + presence edge in
    RTC-persistent RAM so they survive deep sleep between polls.
    - main: idle poll (skip Wi-Fi, drift-correct baseline) vs active poll
    (publish, track the visit) with a falling-edge publish; bound Wi-Fi
    bring-up + publi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
    [main.rs]
2026-07-12 feat: integrate DS18B20 temperature probe (closes #7)
    Add ambient temperature measurement via a DS18B20 waterproof 1-Wire probe
    alongside the HX711 weight reading.
    - src/ds18b20.rs: hand-rolled 1-Wire bit-bang driver in the hx711.rs style —
    open-drain data line, blocking time slots, async 750 ms conversion wait,
    Skip-ROM single-drop addressing, CRC-8-checked scratchpad, float-free
    decimal-C formatting, compile-time const assertions for CRC/conversion.
    - src/main.rs: read the probe on GPIO2 only on the publish paths (bird
    present / just left), so the ~750 ms conversion never runs on the low-power
    idle-poll cycles; publish C to birds/scale/temperature in the same Wi-Fi
    session.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
    [main.rs]
2026-07-12 feat: configure & calibrate the scale from Home Assistant (closes #8)
    Move calibration and tuning off compile-time constants / the HA template and
    onto the controller, tunable live from Home Assistant over retained MQTT.
    - src/config.rs: runtime Config (offset, scale_factor, threshold in grams,
    idle/active intervals, tare token) persisted as a CRC-32-guarded fixed blob
    in one flash sector via esp-storage; a blank/corrupt sector falls back to
    built-in defaults. Float-free gram formatting; live-apply parser for the
    retained config topics.
    - src/main.rs: load config at boot (radio down); presence threshold and sleep
    intervals now come from config; publish weight as grams (converted o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
    [main.rs]
2026-08-13 feat: HX711 pin fix, periodic heartbeat, deep-sleep toggle
    Hardware bring-up + Home Assistant integration fixes verified on the XIAO
    ESP32-C3 (D0=GPIO2, D1=GPIO3, D2=GPIO4; GPIO0/1 not broken out):
    - main.rs: correct HX711 pins (SCK=GPIO2, DT=GPIO3) and DS18B20 on GPIO4;
    add a periodic heartbeat that brings Wi-Fi up every `heartbeat_secs` even
    with no visitor and publishes temperature + weight, so Home Assistant keeps
    a fresh reading. The idle-wake counter driving it lives in RTC RAM.
    - config.rs: on-flash layout VERSION 3 (adds `deep_sleep` and `heartbeat_secs`,
    eight fields); `heartbeat_wakes()` helper; apply `heartbeat_interval` and
    `deep_sleep` from retained MQTT.
    - state.rs: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
    [main.rs]
2026-08-13 feat: scaffold configurable multi-sensor base platform (#11)
    Groundwork for turning the single-purpose bird scale into a base platform
    where each ESP32-C3 node enables the sensors it physically has. Additive
    only — the working bird-scale path in main.rs is untouched; the new module
    just compiles alongside it.
    - sensors/mod.rs: HAL-agnostic `Sensor` trait (async `measure()` -> readings,
    `descriptors()` for HA discovery), `Reading`/`EntityDescriptor` types, and
    shared helpers (Sensirion CRC-8 with a compile-time check vector, float-free
    fixed-point formatters).
    - sensors/{sht31,scd41,sds011}.rs: stub drivers carrying the datasheet
    constants (I²C addrs/commands, UART frame layout),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
    [main.rs, mod.rs, scd41.rs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]
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2026-08-13 refactor: take MQTT broker address from a build-time env var
    The broker's private LAN IP was hard-coded in src/main.rs. It is not a secret
    (RFC-1918), but on a public repo it is cleaner to keep it out of source, and it
    mirrors how the Wi-Fi/MQTT credentials are handled. `MQTT_BROKER` is now read
    via option_env! and const-parsed into an Ipv4Address (compile-time checked
    against the default); a plain build still works via the default. Documented in
    .env.example and README.
    [main.rs]
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2026-08-14 feat: configurable multi-sensor base platform (#12–#17)
    Turn the single-purpose bird scale into one image that serves the whole
    fleet: `NODE=<name>` at build time picks the sensor set, the identity and
    the power profile, and Home Assistant discovers the result over MQTT.
    - node.rs (#12): per-node table — id/name/namespace, sensor slots, power
    profile, mains cadence. Slots can rename their readings so the outdoor
    node's DS18B20 (`temperature`) and SHT31-D (`air_temperature`) coexist.
    An unknown NODE fails the build in const-eval.
    - sensors/ (#13–#15): real bus I/O for SHT31-D, SCD41 and SDS011. The
    drivers stay HAL-agnostic — generic over embedded-hal-async /
    embedded-io-as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
    [main.rs, mod.rs, node.rs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]
2026-08-14 feat: Home Assistant availability via MQTT last-will + expire_after
    Home Assistant could not tell a dead node from a quiet one. Two
    mechanisms now cover it, because on a half-sleeping fleet neither works
    alone:
    - Mains nodes register a last will on `<ns>/<node>/status` (retained
    `offline`), publish `online` after each connect, and — crucially —
    send a proper DISCONNECT when a round is finished so the broker
    discards the will. Without that, a node that reconnects once per
    round would be announced as dead after every publish.
    - Battery nodes get no will at all: they are legitimately disconnected
    almost all the time, so it would fire seconds after every reading.
    Both profiles th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
    [main.rs, node.rs]
2026-08-14 feat: I²C bring-up probe + flashing guide for the fleet
    Bench validation is the open item on #11, and right now every I²C fault
    looks the same from the serial monitor: "not responding". Wrong pins, a
    missing pull-up, an unpowered sensor and a breakout that straps ADDR
    high are all indistinguishable.
    So on the first measurement of each boot, ask the expected addresses
    whether anything is there (side-effect-free status/data-ready reads) and
    say so in the log. An SHT31-D found only at 0x45 is adopted rather than
    reported missing — breakouts differ on how they strap ADDR.
    The probe runs once per boot and only where it can help: a battery
    node's idle wakes never reach the sensor path at all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
    [platform.rs, sht31.rs]
2026-08-14 feat: provision a board's node identity from NVS, over MQTT
    `NODE=` at build time meant a board could only be told what it is by
    reflashing it. The identity is now resolved at boot — build-time default,
    overridden by a name in flash — so one image can be flashed to every
    board and each one told which node it is afterwards.
    - node.rs: `BUILT_AS` (the compiled-in identity) + `active()`, written
    once by `init()` before any peripheral is touched, since the sensor set
    decides which buses come up at all. `by_name` is shared by the
    build-time selection and by provisioning, so both accept exactly the
    same names; an unknown `NODE=` still fails the build in const-eval.
    - config.rs: the id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
    [main.rs, node.rs, platform.rs]
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2026-08-15 test: make the pure logic host-testable, and run it in CI
    `cargo test` cannot link for riscv32imc, and the crate was a single binary
    pulling in esp-hal, so it would not build for the host either. That left
    compile-time `const` assertions as the only harness — and the habit of checking
    things like the discovery JSON against throwaway host *replicas* of the real
    code, which prove nothing the moment they drift.
    The crate is now a library plus a thin binary, with everything that touches a
    bus, RTC RAM, flash or the radio behind the `hal` feature (on by default, so
    `cargo build` is unchanged). What remains builds for the host: protocol
    decoding, CRCs, the flash blob layouts, `Config::apply`, t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
    [main.rs, mod.rs, node.rs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]
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2026-08-16 test: cover the SCD41 driver's two run modes
    The mode is a per-node build-time choice, and the two halves fail in opposite
    directions, so both are worth pinning down.
    Periodic (mains) must send `start_periodic_measurement` exactly once — a node
    that re-sent it every round would restart the conversion cycle and never read
    anything — and must poll data-ready first, or it reads the previous
    measurement, which on a fresh start is not a measurement at all. Single-shot
    (battery) does neither: one conversion on demand, waited out, then read.
    Both must treat 0 ppm as "no measurement yet" rather than as air; publishing it
    would draw a plausible flat line at zero rather than a gap. Corruption is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
    [scd41.rs]
2026-08-16 feat: end the SDS011 warm-up when the readings settle
    The fan is duty-cycled because it is rated ~8000 h, and how long it stayed
    awake was a flat 20 s — a guess in both directions. Too long for still air, and
    too short for air that is actually changing, which is when the reading matters.
    It now serves a floor and then watches. The floor (10 s) is not optional:
    before the airflow establishes the sensor repeats its last value, so frames
    agree with each other perfectly and a settling check alone would stop on air
    that is not moving yet. After it, frames are read until three in a row agree —
    within 1 µg/m³ plus 5 % of the larger, an absolute floor for clean air where the
    sensor's own nois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
    [main.rs, platform.rs, sds011.rs]
2026-08-16 feat: Wi-Fi credentials in NVS, set over the serial console
    Credentials were compile-time only, which made the one failure that matters
    unrecoverable: a board that cannot join the network cannot be told anything
    over the network either. MQTT provisioning — how the node identity is set — is
    no help here, because reaching the broker is precisely what is broken.
    So the way in is the serial console, the one channel that still works. On a
    cold boot the firmware listens for `ssid` / `psk` / `save`, stores the pair in
    its own flash sector and restarts into it. `clear` returns the board to
    whatever it was flashed with. Physical access already implies the ability to
    reflash, so this gives away n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
    [main.rs, wifi.rs]
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2026-08-16 test: exercise the HX711 bit protocol against fake pins
    The load cell was the last driver with no coverage, and the only one that has
    actually been running — which is the argument for covering it rather than
    against. Its failure mode is the bad kind: get the bit order or the pulse count
    wrong and the scale reports plausible numbers, not obviously broken ones.
    The pins and the delay now come in as `embedded-hal` traits rather than esp-hal
    types, the same move the bus drivers already made. `main` supplies the concrete
    `Input` / `Output` / `Delay` through a `Scale<'d>` alias, so nothing about the
    wiring changed.
    The two fake pins share a line, so the tests can check not just what was read
    b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
    [main.rs]
2026-08-17 feat: sweep the I²C bus when an expected sensor is missing
    "no SHT31-D at 0x44" is what you get whether the sensor is absent, sitting at
    an address nobody expected, or the bus is not working at all. Three problems,
    one message, and completely different fixes — which is a poor place to start a
    bench session.
    So when an expected device is missing, and only then, the firmware sweeps
    0x08–0x77 with zero-length writes and says what answered. Anything answering
    proves the wiring and the pull-ups are fine and the sensor is simply somewhere
    else; nothing answering proves they are not. The sweep is ~110 transactions,
    which is why it is a reaction to a problem rather than part of every boot.
    A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
    [mock.rs, mod.rs, platform.rs]
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2026-08-25 fix: stop a running SCD41 measurement before starting one
    The SCD41 is powered from 3V3 and never sees the ESP32's reset, so after a
    watchdog, a crash or a reflash it can still be in periodic measurement mode
    from the previous boot. In that mode it accepts only read_measurement,
    get_data_ready_status and stop_periodic_measurement, and refuses
    start_periodic -- which left `started` false, so every subsequent round
    retried the same refused command. The node logged "SCD41 found at 0x62" and
    then published nothing at all until someone physically pulled power.
    Found during the `schlafzimmer` bring-up: attaching the serial monitor resets
    the ESP but not the sensor, and the node never recovered.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
    [scd41.rs]
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2026-08-26 feat: make the SCD41 temperature offset tunable from Home Assistant
    The SCD41 measures on a die that heats itself and cancels that with a
    temperature offset -- 4 C out of the box, a figure calibrated for a board
    that runs the sensor continuously. The firmware never touched the
    register, so every node ran on that default whether it fitted or not.
    It does not fit `schlafzimmer`. Head to head with the `bad` node's SHT31-D
    in the same room, both steady for 25 minutes: 24.7 C / 70.9 % against
    26.3 C / 53.6 %. The offset is not cosmetic -- the humidity signal is
    compensated to the offset-corrected temperature, so an offset that
    overshoots the real self-heating skews both outputs, temperature low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
    [main.rs, platform.rs, scd41.rs]
2026-08-26 fix: actually send the MQTT DISCONNECT before dropping the socket
    Every round ended with `client.disconnect()`, which is supposed to make
    the broker discard the last will so a node that simply finished its work
    is not announced as dead. It never reached the broker.
    `rust-mqtt` hands the DISCONNECT to the socket with `write_all` and
    returns; embassy-net leaves it in the TX buffer until the stack next
    polls, and `Drop for TcpSocket` only removes the socket from the set,
    taking whatever is still queued with it. So the broker saw every round
    end as an abrupt drop and published the retained will on the next
    connect -- an `offline` flickering immediately before every `online`,
    observed on both `b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
    [main.rs]
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2026-08-26 feat: read the SCD41's serial number, and let it test itself when it fails
    Two commands the driver never used, both worth their airtime.
    `get_serial_number` (0x3682) returns a unique 48-bit id. Logged once per
    boot next to the address probe, it says which physical sensor sits in
    which node -- and it is the cheapest counterfeit check available. The
    SCD4x is among the most-copied parts around, and fakes tend to answer
    here with zeroes or with the same number on every unit, so a zero is
    called out rather than printed as if it meant something.
    `perform_self_test` (0x3639) asks the sensor whether it believes its own
    hardware is sound. It runs automatically after three consecutive empty
    rounds -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
    [platform.rs, scd41.rs]
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2026-08-30 feat: read the cell voltage, at the cost of the DS18B20's pin
    The XIAO charges a LiPo but cannot measure one: B+ reaches the charger
    and the regulator, never an ADC. A 100k/100k divider with 100 nF at the
    tap gives ADC1 something to read, and D2 is the only pad that can take
    it — ADC1 is GPIO2/3/4, the HX711 owns the first two, and D3 is on ADC2,
    which is unusable while Wi-Fi is up. So the outdoor node gives up its
    DS18B20 for this. The SHT31-D was measuring the air anyway.
    The driver calibrates against the chip's own eFuse reference, so
    conversions arrive in millivolts already corrected for that part; only
    the divider ratio is undone in fixed point. A reading below 2.0 V is not
    published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
    [battery.rs, main.rs, mod.rs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]
2026-09-03 style: drop a redundant closure clippy rejects
    `-D warnings` in CI turns this into a build failure, so the SCD41 offset
    ordering test was holding up everything behind it. Unrelated to the change
    it happens to sit in front of.
    [scd41.rs]
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2026-09-03 feat: move the particulate sensor to the living room, and the kitchen to an SHT31
    The kitchen is where the particulates come from, which made it the obvious
    place and the wrong one.
    The SDS011 is an open optical path with a fan pulling room air through it,
    and kitchen air carries fat aerosol from frying. That films the optics and
    drifts the calibration without ever failing outright — the sensor keeps
    answering, plausibly, with numbers that have walked off. Same shape as the
    SCD41 membrane that cost us a module in August, and the expensive shape,
    because nothing in the log says it is happening.
    The second reason is that the answerable question is in the living room.
    That frying makes smok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
    [node.rs]
2026-09-03 fix: run the mains nodes at 80 MHz and let the radio sleep
    A mains node never sleeps, so everything the core burns turns into heat
    inside the enclosure — and the sensors then measure their own board
    instead of the room. Measured on `schlafzimmer` against a reference
    thermometer, 2026-09-03: the air at the electronics sat ~1.5 °C above the
    room, and the SHT31-D reported it faithfully. The SCD41's temperature
    offset had been calibrated against that same warm SHT31-D, so the error
    was already copied into it and the two agreeing proved nothing.
    80 MHz is exactly the minimum esp-wifi will run the radio at (`MIN_CLOCK`
    in its `init`, which rejects anything below it), and dynamic power scales
    w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
    [main.rs]
2026-09-03 fix: drive the SCD41 on its low-power cadence
    Periodic mode was starting the 5 s cadence (0x21B1) on a node that
    publishes every 60 s, so eleven of every twelve measurements were thrown
    away — and paid for in heat. The SCD41 is the warmest part on the board
    after the ESP, and on `schlafzimmer` it was measurably heating the
    SHT31-D next to it: pulling the SCD41 dropped that sensor by 0.5 °C over
    25 minutes (2026-09-03).
    `start_low_power_periodic_measurement` (0x21AC) samples every 30 s, still
    twice as often as the fastest node publishes. The protocol is otherwise
    identical — data-ready poll, then read_measurement — and automatic
    self-calibration behaves the same in either cadence, so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
    [scd41.rs]
2026-09-04 fix: stop the baseline drift from eating light visitors
    The empty-house drift tracker nudged the baseline by `delta/16` on *any*
    sub-threshold reading. That is right for the slow thermal and mechanical
    creep it was written for, and wrong for a bird.
    A visitor whose load sat below `threshold` — a small species, or one
    perched half on the rim — was pulled into the baseline within roughly 16
    cycles, so the scale read "empty" again while it was still standing
    there. Worse, on departure the delta went *negative*, which is also
    sub-threshold, so no falling edge fired either and the baseline simply
    crept back. The visit left no trace in the logs or on the broker. The
    failure was systematic, no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
    [main.rs]
2026-09-04 fix: watch a bird's visit awake instead of at the sleep interval
    On a rising edge the firmware published one arbitrary HX711 conversion
    and deep-slept for `active_interval` — 10 s by default, which is
    *slower* than the 2 s idle poll. The cadence dropped exactly when dense
    data was wanted, and three things followed from that:
    - the single unaveraged sample could land while the bird was still
    settling, so the published weight described a moment nothing ever
    weighed;
    - the departure was quantised to the same 10 s grid, so the visit
    duration was too coarse to mean much;
    - every one of those cycles paid its own Wi-Fi connect. A two-minute
    visit cost about twelve of them.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
    [main.rs]
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2026-09-04 perf: poll the load cell from light sleep, not a cold boot
    Deep sleep sat inside the poll loop, so every 2 s idle poll cost a full
    ROM boot plus app init — 269 ms measured on this chip — to clock out one
    100 ms conversion. At the default `idle_secs: 2` that is roughly a
    quarter of the node's life spent booting, which made the boot overhead
    its single largest consumer, ahead of the radio it was carefully
    avoiding.
    The polls now happen inside one boot with light sleep between them. A
    cold boot happens once per *publish* instead of once per poll: about six
    an hour on the default heartbeat, against eighteen hundred.
    Two properties of `RtcSleepConfig`'s light-sleep default on the ESP32-C3
    m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
    [main.rs]
2026-09-04 perf: power the load-cell amplifier down between polls
    The HX711 and the bridge it excites are the node's largest standing
    load — about 1.5 mA for the chip, plus the excitation current the load
    cell draws continuously, which for a 1 kΩ cell at ~3.2 V is another
    ~3 mA — and nothing was ever switching them off.
    `power_down()` and `power_up()` had been written, documented and then
    never called. The reason was in the driver's own note: no sleep retained
    the pad level, so parking `PD_SCK` high bought nothing. In deep sleep
    the pad goes high-impedance and `PD_SCK` is left to leakage, which is
    also why the amplifier's deep-sleep current was never a known quantity
    rather than a low one. Light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
    [main.rs]
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2026-09-04 feat: switch on the terrasse SHT31 and load cell
    The SHT31-D is wired to the terrace node. Its slot was off, which is why
    nothing appeared in Home Assistant — a disabled slot is never probed, so
    the absence was the configuration working, not a fault.
    It takes the plain `temperature` and `humidity` keys with no prefix. The
    node this one replaced put its SHT31 behind `air_` to leave those keys
    to a DS18B20, and kept the prefix long after the probe was gone purely
    because renaming it would have orphaned Home Assistant history. That
    history went with the rename, and there is no probe here for the plain
    keys to collide with.
    The scale slot goes on at the same time, at the owner's request, ahe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
    [node.rs]
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
